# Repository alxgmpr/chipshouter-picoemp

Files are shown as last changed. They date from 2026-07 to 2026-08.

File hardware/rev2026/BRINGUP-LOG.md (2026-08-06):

# Rev-2026 Bring-Up Log — Board #1

Plan: `docs/superpowers/plans/2026-08-05-picoemp-rev2026-bringup.md`
Spec: `docs/superpowers/specs/2026-08-05-picoemp-rev2026-bringup-design.md`

Equipment: DMM; bench PSU with current limit. No scope, no HV probe.

---

## ⚠️ Designators below are board #1's, and rev B moved several

This log is a record of what was measured on the first assembled board. The
readings and conclusions stand. **The reference designators do not** — rev B
re-designated things, so a designator here may name a different part on a
later board.

**Follow this log by what each part is, not by what it is called.**

| What it is | Board #1 | Rev B |
|---|---|---|
| HV terminal block, the `HV_RTN` / `HV_SENSE` tap | `J3` | **`J4`** |
| Trigger input SMA | `J4` | **`J3`** |
| 7-pin header: `TRIG_IN`, `GP1`–`GP5`, `GND` | `P1` | **`J6`** |
| 2-pin header: `GND`, `HVPULSE` | `P2` | folded into the 5-pin |
| 4-pin header: `CHARGED`, `+3V3`, `GND`, `HVPWM` | `P3` | folded into the 5-pin |
| 5-pin header: `+3V3`, `CHARGED`, `HVPULSE`, `HVPWM`, `GND` | — | **`J5`** |

The HV output SMA, the JST power input, all three switches and the Pico keep
their designators.

**One functional change, not just a rename.** The arm switch now pulls its net
to `GND`; on board #1 it pulled up to `+3V3`. Both switches are now
pull-to-ground, which is why `firmware/micropython/bringup.py` configures both
with `PULL_UP` and treats a press as a low reading.

**Consequence: the current `bringup.py` will fail the ARM button check on
board #1.** With an internal pull-up on a pin that board #1's arm switch drives
to `+3V3`, the pin reads high whether or not the button is pressed, so the
press is never seen. That script now targets rev B. Board #1 needs the arm
switch read as `PULL_DOWN`, active high.

Everything electrical in the fault-injection path is unchanged — the charge
loop, the sense chain, the isolation barrier and the discharge path are the
same circuit.

---

## Phase 0 — cold checks

Date: 2026-08-05

Board had not been energized before these readings were taken.

| # | Measurement | Expected | Measured | Pass |
|---|---|---|---|---|
| 0.1 | J1 centre → J3.2 | 300 kΩ ±5 % | 299.5 kΩ | ✅ |
| 0.2 | Hold SW3, J1 centre → J3.1 | 300 kΩ ±5 % | 273 kΩ / 299.3 kΩ reversed (see note) | ✅ |
| 0.3 | GND (USB shell) → J3.1 | open > 20 MΩ | OL | ✅ |
| 0.4 | J1 centre → J1 shell | not a short | OL | ✅ |
| 0.5 | Pico 3V3(OUT) → GND | not a short | 36 kΩ | ✅ |
| 0.6 | J2.1 → J2.2 | not a short | 2.2 MΩ | ✅ |

### Note on 0.2 — 273 kΩ rather than 300 kΩ

`R2` is confirmed good by 0.1 at 299.5 kΩ, and SW3 is confirmed closing by
0.2 reading a finite value at all rather than OL. The 27 kΩ shortfall is a
second conduction path between the probe points, not a component fault:

```
J3.1 (HV_RTN) → T1 secondary (T1.3→T1.2) → HV_RECT → D2 anode→cathode → HV_RAIL (J1 centre)
```

`D2.1` is the cathode on `HV_RAIL` and `D2.2` the anode on `HV_RECT`, so this
path forward-biases when the DMM's **red** lead sits on J3.1, putting a
weakly-conducting diode branch in parallel with R2. Solving 273 ∥ 299.5 puts
that branch at ~3.0 MΩ, consistent with a silicon diode at sub-µA DMM test
current.

0.1 is unaffected because `HV_SENSE` never touches `HV_RTN`, so no D2 path
exists for that measurement — which is why it reads clean.

Reversed-polarity confirmation: **299.3 kΩ**, within 0.2 kΩ of 0.1's 299.5 kΩ.
D2 blocks in this direction and R2 is the only path, as predicted. Resolved.

**Practical consequence:** future resistance measurements between `HV_RAIL` and
`HV_RTN` must put the red lead on `HV_RAIL` (J1 centre). The other polarity
reads low through T1's secondary and D2 and does not indicate a fault.

Notes: Board had not been energized before these readings.

---

## Phase 1 — first power

Date: 2026-08-05
PSU: 5.0 V into J2. USB unplugged. Pico unprogrammed.

The PSU's current-limit function was unavailable (constant-voltage only), so
the DMM was used in series on its mA range instead — a direct current reading,
with the mA-jack fuse as the limit. Voltage was then read in a second pass with
the DMM back on volts.

| Reading | Expected | Measured | Pass |
|---|---|---|---|
| Supply current | < 100 mA, no limit | 0.87 mA | ✅ |
| Pico 3V3(OUT) → GND | 3.3 V ±5 % | 3.285 V (−0.45 %) | ✅ |

### Note on the 0.87 mA

Lower than an unprogrammed Pico normally idles at — the RP2040 bootrom's USB
device mode runs the core and usually draws tens of mA. The likely cause is
DMM burden voltage: on a low autoranged mA scale the shunt resistance drops
the input enough that the RP2040 never starts, and a core that isn't running
keeps the current low, which keeps the DMM on the low range.

Not a concern for what Phase 1 tests. Sub-mA draw with the 3V3 rail up means
no leakage path anywhere, which is the stronger version of the result we
wanted. Cross-check in Phase 2: with MicroPython flashed, draw should rise to
tens of mA. If it does not, revisit this.

---

## Phase 2 — I/O self-test

Date: 2026-08-05
MicroPython: v1.28.0, build `RPI_PICO`, `Raspberry Pi Pico with RP2040`
UF2: `RPI_PICO-20260406-v1.28.0.uf2`, familyID `0xe48bff56` (RP2040), header verified before flashing
Port: `/dev/tty.usbmodem212201`
Script: `firmware/micropython/bringup.py`

| Check | Expected | Observed | Pass |
|---|---|---|---|
| STATUS LED | lights alone | lit | ✅ |
| HV_DET LED | lights alone | lit | ✅ |
| CHARGE LED | lights alone | lit | ✅ |
| All three together | all lit | all lit | ✅ |
| CHARGED idle level | 1 | 1 | ✅ |
| ARM button | PASS | PASS | ✅ |
| PULSE button | PASS | PASS | ✅ |

The script's own `RESULT: PASS` covers only the two button presses — it
cannot sense the LEDs. The four LED rows above are operator-confirmed.

`U1` is `SC0915`, a plain Pico, so the non-W `RPI_PICO` build is correct.
Two other `/dev/tty.usbmodem*` ports on this host belong to an unrelated
device and do not respond to mpremote.

### Firmware defect found at the start of Phase 3 — CHARGED misread

`chargetest.py` aborted with "CHARGED already asserted" on its first run,
having read the same pin as 1 in Phase 2 twenty minutes earlier with nothing
electrical changed in between.

**No high voltage was involved.** Measured through ADC0, the `CHARGED` net sat
at a steady 3.20 V for 20 s including an SW3 press. A charged rail would have
had the LDA111 sinking current and holding the net near 0, and SW3 would have
produced a visible step. Neither happened.

Root cause: the RP2040 resets every GPIO pad with its pull-down enabled
(`PADS_BANK0` reset value `0x56`, bit 2 `PDE=1`), and `CHARGED` reaches **two**
pads — GP18 (U1.24) and GP26/ADC0 (U1.31). Both scripts configured only GP18,
leaving GP26's ~65 kΩ pull-down on the net. Two pull-downs in parallel against
R6's 22 kΩ pull-up divide the net to roughly 2 V, inside the RP2040's
indeterminate band (VIL 0.99 V, VIH 2.31 V). The digital read was arbitrary.

Diagnostic evidence — the level flipped on the exact line that reconfigured
GP26:

```
Pin(18, IN)             = 1
Pin(18, IN, PULL_DOWN)  = 0
Pin(18, IN, None)       = 0
-- configuring ADC0 on GP26 --
GP26 net voltage        = 2.767 V  -> settles 3.20 V
Pin(18, IN, None) now   = 1
```

Fix: configure both pads. `ADC(26)` disables that pad's digital pull, leaving
R6 as the only pull-up. `chargetest.py` now also reads `CHARGED` as a voltage
rather than a logic level, and refuses to charge if the net sits between 1.0
and 2.9 V rather than guessing. Verified on the board: 3.20–3.22 V steady,
GP18 = 1 on every sample.

**Upstream `cspico_simple.py` has the same defect** — `Signal(Pin(18, Pin.IN),
invert=True)` with GP26 never touched. It mostly works because a genuinely
charged rail pulls the net hard to near 0 V, which reads correctly; the failure
mode is a spurious "charged" at rest, which is what was seen here. Not fixed —
this port does not modify upstream firmware.

Not carried out: the Phase 1 current cross-check. Supply draw with
MicroPython running was not re-measured, so the 0.87 mA reading above
remains unexplained rather than confirmed as a DMM burden artifact. Low
priority — it did not block anything.

---

## Phase 3 — first charge

Date: 2026-08-05
Shield: Kapton-taped, **sits flush** (see open items). J1: dust cap fitted.
Power: USB. Script: `firmware/micropython/chargetest.py`

Three consecutive runs:

| Run | At rest | Time to assert | Result |
|---|---|---|---|
| 1 | 3.21 V | 2165 ms | PASS |
| 2 | 3.21 V | 2110 ms | PASS |
| 3 | 3.19 V | 2101 ms | PASS |

| Check | Expected | Observed | Pass |
|---|---|---|---|
| CHARGED asserts | within 10 s | 2.1 s | ✅ |
| Repeatability | — | 2101–2165 ms, 3 % spread | ✅ |
| SW3 releases CHARGED | yes | yes, all three runs | ✅ |

**What these numbers do and do not mean.** The charge time and its
repeatability are real: the T1 channel charges consistently, not marginally.

The "asserted at 0.99 V" the script prints is tautological — the poll loop
exits the moment the net crosses `CHARGED_MAX_V = 1.0`, so it reports the
threshold, not a measurement. Worth changing to sample after a short settle
if that number is ever wanted.

The discharge times (5899 / 3046 / 1101 ms) are dominated by operator reaction
time between the prompt and pressing SW3. τ is 141 ms, so the circuit's share
of each is small. These are not a measurement of discharge speed, and the
downward trend across runs is the operator getting quicker.

Rail voltage measured in Phase 4 — see below.

---

## Phase 4 — stock firmware

Date: 2026-08-05
Firmware: `firmware/micropython/cspico_simple.py` copied to `:main.py`

| Check | Expected | Observed | Pass |
|---|---|---|---|
| ARM lights CHARGE LED | immediately | yes | ✅ |
| HV LED follows | ~2 s | yes | ✅ |
| SW3 drops HV LED | yes | yes | ✅ |
| 60 s auto-disarm | CHARGE LED off | yes | ✅ |

PULSE not exercised — no injection tip. See spec section 8.

**The upstream CHARGED defect did not manifest on this board.** Stock firmware
configures GP18 only and leaves GP26's pull-down on the net, but the HV LED
behaved correctly throughout — no spurious assert at rest, no flicker. This
supports the earlier claim that upstream "mostly works" despite the defect,
which had been asserted without observation. One board, one session; not a
strong result, but it is now an observation rather than a guess.

### Rail voltage — approximately 261 V

Measured with the DMM across J3, i.e. `HV_SENSE` to `HV_RTN`: **250 V** while
charged, decaying after auto-disarm.

That reading is loaded. The DMM's 10 MΩ input sits in parallel with R1 plus
the opto LED, so it is not a direct rail measurement:

```
HV_RAIL --[R2 300k]-- HV_SENSE --+--[R1 20M]--[LED]-- HV_RTN
                                 +--[DMM 10M]--------/
```

Solving the node at 250 V with the LED at ~1.2 V:

| Branch | Current |
|---|---|
| through R1 + LED | (250 − 1.2) / 20 M = 12.4 µA |
| through the DMM | 250 / 10 M = 25.0 µA |
| total through R2 | 37.4 µA → 11.2 V across R2 |

**V_rail ≈ 261 V.** This corroborates the ~250 V figure that previously came
only from the firmware's empirically tuned duty cycle, and leaves comfortable
headroom against C3's 630 V and Q2's 650 V.

**Assumption: 10 MΩ DMM input impedance.** The result is sensitive to it — the
same 250 V reading at 1 MΩ input would imply a 329 V rail. Confirm the meter's
spec before treating 261 V as settled.

The observed decay after auto-disarm is consistent: the DMM shortens the bleed
path from 20.3 MΩ to ~6.97 MΩ, so τ falls from 9.5 s to 3.3 s.

This measurement is repeatable and is now the documented way to check the rail
without an HV probe.

---

## Bring-up complete

All five phases pass. The board charges to roughly 261 V in ~2.1 s, asserts
CHARGED, and discharges on SW3. Stock firmware is installed as `main.py`.

## Open after bring-up

- **Rail voltage is approximate, not qualified.** 261 V is derived from a
  loaded divider measurement with an assumed 10 MΩ meter input, not read
  directly. A proper HV probe would settle it.
- **No injection tip, so pulsing has never been exercised.** Suggested parts:
  Würth `744710603` inductor plus a `CONSMA013.062` edge-mount SMA male. See
  `hardware/injection_tips/README.md`.
- **Mounting holes mirrored.** MH1/MH2 sit on the opposite diagonal to the
  1551G's screw bores; the shield is Kapton-taped rather than screwed. The
  proposed fix is to swap MH1's and MH2's Y coordinates — but see the next
  item before editing anything.
- **The shield seats flush, contradicting the layout record.** `CLAUDE.md` and
  `LAYOUT-HANDOFF.md` both state Q2 fouls the shield rim with 0.00 mm clear
  against 2.32 mm needed, and call it the last open item before the shield
  sits flat. It sits flat on the physical board. Either that note is stale or
  the fabbed board differs from the working copy — which is itself on the
  `+25.4 mm` shifted layout rather than the `rev2026` geometry. Establish
  which revision was actually fabbed before touching MH1/MH2.
- **Phase 1's 0.87 mA draw was never explained**, and the cross-check with
  MicroPython running was not taken.
- **Upstream `cspico_simple.py` has the CHARGED two-pad defect** described
  above. Not fixed here; did not manifest on this board.
- **The trigger front-end is only half tested.** Phase 5 §5.3 passes on board
  #1: the buffered path from the header through R14 and U2 to GP0 carries DC,
  slow edges and short pulses. Everything entering through the **SMA** is
  still untested, as are the DC levels (§5.1) and the Schmitt trip points
  (§5.2). No shipped firmware reads GP0 either — `cspico_simple.py`,
  `bringup.py` and `chargetest.py` all ignore it, so the trigger does nothing
  on a board running stock firmware.

---

## Phase 5 — trigger front-end

Date: 2026-08-06 for §5.3, on board #1. **§5.0, §5.1 and §5.2 have not been
run** — their Measured and Pass columns are blank on purpose.

Script: `firmware/micropython/trigtest.py`

The chain, from the netlist:

```
J3 SMA centre ──┬── TRIG_IN ── R14 100R ──┬── U2.2 (A) ──> U2.4 (Y) ── GP0 (U1.1)
J6.1 header ────┘        net "TRIG_BUF" ──┴── R15 10k ── GND

U2 = 74LVC1G17 Schmitt buffer, SOT-23-5, on +3V3 with C6 100n
R16 = 0R bypass across the buffer, DNP — must stay unfitted
```

Two naming traps. **`TRIG_BUF` is the buffer's input node, not its output** —
the output net is plain `GP0`. And `GP0` is not on any header, so the only
places to probe it are U2 pin 4 and the Pico's pin 1.

**Board #1 is rev A, and the tables below are in rev B names.** Nothing
electrical differs in this path — same Pico pins, same nets, same parts — so
`trigtest.py` runs on rev A unedited. Only the silkscreen names change:

| What | Rev B (below) | Rev A (board #1) |
|---|---|---|
| Trigger input SMA | `J3` | **`J4`** |
| 7-pin header: `TRIG_IN`, `GP1`–`GP5`, `GND` | `J6` | **`P1`** |
| Loopback jumper | `J6.1 ↔ J6.2` | **`P1.1 ↔ P1.2`** |
| `+3V3` pin for 5.1.3 | `J5.1` | **`P3.2`** (4-pin: `CHARGED`, `+3V3`, `GND`, `HVPWM`) |

`J3` in a rev A context is the HV terminal block, not the trigger — keep the
two apart when probing.

### 5.0 — cold checks

Unpowered. Confirm U2, R14, R15 and C6 are actually populated first, and that
R16 is not.

| # | Measurement | Expected | Measured | Pass |
|---|---|---|---|---|
| 5.0.1 | J3 centre → J6.1, probed at the far end of a mated cable | 0 Ω | | |
| 5.0.2 | J3 centre → U2.2 | 100 Ω (R14) | | |
| 5.0.3 | U2.2 → GND | 10 kΩ (R15) | | |
| 5.0.4 | J3 centre → GND | 10.1 kΩ | | |
| 5.0.5 | J3 shell → GND | 0 Ω | | |
| 5.0.6 | U2.5 → Pico 3V3 | 0 Ω | | |
| 5.0.7 | U2.3 → GND | 0 Ω | | |
| 5.0.8 | U2.5 → GND | not a short | | |
| 5.0.9 | U2.2 → Pico pin 1 | open — **not** 0 Ω | | |

5.0.1 through the mated cable rather than the pad, because the edge-launch
SMA's centre-pin joint is the thing most likely to be bad. 5.0.9 catches R16
fitted, which would put the unbuffered node straight onto GP0.

`R15` is an easier probe point for the buffer input than U2's SOT-23-5 pins:
**pad 1 is the input node, pad 2 is GND**. Which one is which physically
depends on how R15 is rotated in the layout, so tell them apart with the
meter — the GND pad reads 0 Ω to ground — rather than by position.

### 5.1 — powered, static

USB power, nothing connected to the trigger.

| # | Measurement | Expected | Measured | Pass |
|---|---|---|---|---|
| 5.1.1 | U2.2 at rest | 0 V (R15 pulls it down) | | |
| 5.1.2 | U2.4 at rest | 0 V | | |
| 5.1.3 | U2.2 with TRIG_IN jumpered to J5.1 (+3V3) | 3.3 V | | |
| 5.1.4 | U2.4, same | 3.3 V | | |
| 5.1.5 | both, jumper removed | back to 0 V | | |

### 5.2 — threshold and hysteresis

Bench PSU into `TRIG_IN`, current limit 10 mA, swept slowly 0 → 2 V and back
while watching U2.4 with the DMM. Datasheet numbers are the VCC = 3.0 V column
of the Nexperia 74LVC1G17, rev 16.1; the rail here is 3.3 V, so the real trip
points sit a little above these.

| # | Measurement | Expected | Measured | Pass |
|---|---|---|---|---|
| 5.2.1 | Rising trip point (V_T+) | 1.29 – 1.71 V | | |
| 5.2.2 | Falling trip point (V_T−) | 0.88 – 1.24 V | | |
| 5.2.3 | Gap between them (V_H) | 0.31 – 0.64 V | | |

Two distinct trip points is the point of the measurement — it is what
distinguishes a real Schmitt part from a plain buffer fitted by mistake.
Input leakage is ≤ 1 µA, so R14 drops nothing and the applied voltage is the
node voltage.

### 5.3 — firmware

```
mpremote connect <port> run trigtest.py
```

Needs one jumper, `J6.1 ↔ J6.2` (`P1.1 ↔ P1.2` on board #1), and **nothing
else on TRIG_IN or the SMA** — GP1 would be fighting it.

Precondition: board disarmed and the cap down before mpremote connects. Stock
`main.py` is running on board #1, and `mpremote` interrupts it — but the
RP2040's PWM slice keeps running after the script that started it stops, so
interrupting mid-charge leaves HVPWM driving. `trigtest.py` never references
GP20 and so cannot stop it either. Confirm the HV LED is out first. The script drives its
own trigger through the whole chain and checks GP0 follows, so it is
self-checking rather than operator-judged.

| Check | Expected | Observed | Pass |
|---|---|---|---|
| `IDLE` | PASS — GP0 low and steady, trigger open | PASS | ✅ |
| `DC` | PASS — GP0 follows 0/1/0 | PASS | ✅ |
| `EDGES` | PASS — 50 sent, 50 counted | 50 / 50 | ✅ |
| `NARROW 100/10/1 us, back-to-back` | PASS on all four | PASS ×4 | ✅ |
| `RESULT` | PASS | PASS | ✅ |

**The buffered path is good on board #1.** GP1 → header → R14 → U2 → GP0
carries DC, 50 slow edges with no extras, and a pulse as short as two
consecutive MicroPython pin writes.

Two caveats on what that does *not* cover. The jumper enters at the header, so
the SMA and its centre-pin joint are untested — that is what §5.4 and the
`WATCH` phase are for. And `IDLE` is only a real test of R15 with the jumper
off: fitted, GP1 is already an output at 0 and holds the trigger down itself.

`WATCH` reported no source on the first three runs, correctly — nothing was
driving the trigger. On the first two the jumper was fitted mid-phase, which
does nothing on its own: GP1 was still an output at 0. The script now releases
GP1 to an input before `WATCH` and says so, so a jumper left in place no longer
fights an outside source.

It cannot make high voltage: GP20 and GP14 are never referenced, enforced by
`tests/test_bringup_firmware.py::test_cannot_drive_hv`.

### 5.4 — before plugging a pulse generator into the SMA

**There is no 50 Ω on this input.** R15 is a 10 k pulldown, not a terminator.
A generator whose amplitude is calibrated into 50 Ω delivers twice that into
an open end, so a 5 V setting arrives at the buffer as ~10 V — against a
5.5 V tolerant input with a 6.5 V absolute maximum. Set the generator to
high-Z, or fit a 50 Ω feedthrough terminator at the board, or measure the
amplitude at the SMA before connecting it.

The same reflection is why long unterminated coax with fast edges can produce
extra counted edges. The Schmitt's 0.3 – 0.6 V of hysteresis absorbs small
overshoot, not a 2 V reflection.

`J3`'s shell is board `GND`, so the coax bonds the target's ground to the
PicoEMP's low-voltage ground and hence to USB. It does not touch the HV
isolation barrier, but it is a ground loop with whatever is being glitched.

Propagation delay through U2 is 3.0 ns typ / 5.5 ns max at 3.0 – 3.6 V —
below what a logic analyser resolves, and far below the RP2040's response.

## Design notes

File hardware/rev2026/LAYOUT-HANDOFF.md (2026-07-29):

# Layout Record — PicoEMP Rev-2026

**Status: layout is done; the HV shield is chosen and screwed down, but two
part groups still foul its rim.** Board routed, both gates green. This
file records what was built and why. It was previously a set of instructions
for work not yet started; those instructions have been carried out and are kept
below only where the reasoning still matters.

For orientation in a fresh session, read `CLAUDE.md` in this directory first.

**Plan:** `docs/superpowers/plans/2026-07-25-picoemp-rev2026.md`
**Spec:** `docs/superpowers/specs/2026-07-25-picoemp-rev2026-design.md`
**Branch:** `rev2026`

---

## Verified state — 2026-07-28

| Gate | Result |
|---|---|
| `uv run --with pytest pytest tests/` | **66 passed**, 0 failed, 0 skipped |
| `kicad-cli pcb drc --severity-error --schematic-parity --exit-code-violations` | **0 errors, 0 unconnected, 0 parity issues**, exit 0 |
| Same, **without** `--severity-error` | **0 violations** — warnings are empty too |
| `kicad-cli sch erc --severity-error` | 0 violations |
| Routing | complete |
| Every symbol has a resolvable footprint | yes |

Board: 40.010 × 130.000 mm overall — the **body** is 40.010 × 125.000 and the
south **15.780 mm-wide SMA tab** carries the remaining 5.000 mm. 2 layers,
1.6 mm. **53 footprints** (45 SMD / 5 THT / 3 other — the mounting holes),
252 track segments, **102 vias**, **76 zones** (75 teardrops + the
`MCU GND Pour`). 53 schematic components, 64 nets. `R16` is the only DNP part.

**DRC warnings are empty.** Older revisions describe two cosmetic silk warnings
and nine from the intra-HV rule; both sets are fixed, and the
`Intra-HV spacing at full rail voltage` rule now passes at its 0.8 mm target.
The `Pad Keep Out TP7` keepouts are also gone.

---

## What changed from the as-received port

- **R9's part data corrected.** It carried R4's 75 Ω MPN, DigiKey PN and value
  while being a 2 k part. A genuine upstream schematic bug.
- **C5's missing value** restored to 100 n.
- All Altium metadata stripped; fields normalised to `MPN` / `Manufacturer` /
  `DigiKey`.
- **Symbol classes corrected** — IGBT (with its co-packed antiparallel diode),
  enhancement MOSFETs, non-Schottky rectifiers, a real Darlington opto, and a
  transformer symbol whose windings match this design's actual 1,4-primary /
  2,3-secondary grouping.
- **All five header footprints** moved from 1.00/1.27 mm to the correct 2.54 mm.
- **Designators restored to upstream's scheme** — `D6/D8/D9`, `P1/P2/P3`,
  `J1` = SMA — so `BUILD-DRAWING-REV04.PDF` and the README BOM explainer apply.
- **New trigger front-end:** `U2` 74LVC1G17 Schmitt buffer, `R14` 100 R series,
  `R15` 10 k pulldown, `C6` decoupling, `R16` 0 Ω bypass (DNP), `J4` optional
  SMA (populated).
- **J3** replaced with a Phoenix `MKDS 1,5/2-5.08` (5.08 mm, 300 V) for creepage.

---

## The 1 mm isolation barrier — how it was implemented

The value is **upstream's own design rule**, annotated on
`SCH-PICOEMP-REV04.PDF`:

> `ISOLATION BARRIER, 400V MIN.  >1MM CLEARANCE PER 61010-1.`

Corroborated by measurement — pad geometry on the hi-pot-validated original
board gives ~1.002 mm across the barrier in routed copper.

**Voltages, from primary sources** (component ratings are headroom, not
operating points):

| | |
|---|---|
| HV capacitor charge | **~250 V** — `firmware/micropython/cspico_simple.py` |
| Upstream barrier design rating | **400 V min** |
| Hi-pot proof test | 1 kV, "well beyond the voltages the device can generate" |

It is enforced as a **scoped DRC rule**, not as netclass clearance. An earlier
draft of this document instructed adding the 1 mm figure to the `HV` netclass;
that turned out to be wrong. As a plain netclass clearance it applies between
any two nets touching the class, which makes 0603 (0.70 mm between its own
pads) and 0805 (0.80 mm) parts illegal on HV nets. The `HV` class therefore
carries 0.2 mm clearance / 0.5 mm track, and `picoemp-rev2026.kicad_dru` scopes
the barrier correctly as HV-to-non-HV. Read that file before changing anything
here.

**Known exception:** T1's own primary↔secondary pad spacing is 0.770 mm, below
this rule. That is the ATB3225 package's geometry, not a routing choice, and
upstream accepted it. Targeted exceptions for T1 and T2 are in the `.dru`.

---

## Resolved — items that were open in the previous draft

- **`Q2` DPAK pad spacing.** Flagged as fab-blocking on a DRC reading of
  0.080 mm that could not be reconciled with geometry computing to 1.08 mm.
  Measured directly: **1.080 mm**. The reading was spurious; the footprint is
  fine at 250 V.
- **`LDA111` pad 3 parity.** The symbol has five pins, the footprint six pads,
  because pin 3's lead physically exists while being electrically NC.
  `--schematic-parity` now reports 0 issues. The pad was not deleted — doing so
  would leave a lead unsoldered.
- **Board setup.** Minimum clearance is 0.2 mm (was 0.0). Thickness 1.6 mm, as
  required by the edge-mount SMA which clamps the board edge and is specified
  for 0.062″.
- **Intra-HV clearance.** Recorded as 0.498 mm at SW3, "the thinnest copper on
  the HV side". No longer true — the `Intra-HV spacing at full rail voltage`
  rule in the `.dru` now reports **zero** violations at its 0.8 mm target, and
  SW3 does not feature. The header comment in the `.dru` still says "As of this
  writing it reports 9 violations"; that predates the fixes that cleared them.
  Sub-0.4 mm gaps do exist between other HV nets, but those pairs sit a few
  volts apart, not 250 — `HV_SENSE` is ~1.5% below `HV_RAIL` across the
  300 k / 20 M divider, and `HV_SENSE_LED` is one opto LED drop above `HV_RTN`.
  That is exactly why the rule is scoped to the three pairs that matter.
- **SW3 clearance under the shield.** Previously unverifiable "for want of a
  3D model" — `lib/models/TL3301AF160QJ.STEP` exists and the part measures
  **4.64 mm**, clearing the 1551G's 15.05 mm cavity easily.
- **The two short Edge.Cuts slots at y 96.354–99.300.** These were the
  1551B's snap-tab pockets, not creepage features — nearest HV-netclass copper
  was 16.6 mm. Removed with the switch to the 1551G.
- **MH1/MH2's 32.000 mm spacing.** Recorded as "the dimension a shield keys
  off". It was not — it was 40.010 minus two 4.000 mm corner insets, and
  upstream REV04's fab drill has the identical pattern.

## The HV safety shield — Hammond 1551G, not the 1551B

Upstream uses the **top half of a 1551B** (50 × 25 × 15) as a see-through shield
over the HV end. This port cannot: **J3's Phoenix terminal block is 13.80 mm
tall and a 1551B half-shell gives 5.80 mm of clear height above the board.** The
creepage upgrade to the 5.08 mm Phoenix part and the shield were never checked
against each other.

The replacement is the **1551G box, inverted, lid discarded**. The larger 1551
sizes are box + lid rather than two symmetric halves, so the box is far deeper
than any half-shell. Every figure below is measured from Hammond's own STEP —
`tools/fetch_hammond_shield_model.py` re-downloads and re-axes both models, and
they are gitignored because Hammond's models are not under this project's
licence.

| | 1551B top half | **1551G box, inverted** |
|---|---|---|
| Outer | 50 × 25 × 15 | **50.000 × 35.000 × 17.000** |
| Interior clear height | 5.80 | **15.050** |
| Interior L × W | 47.4 × 21.6 | **44.73 × 29.73** |
| Screws | 2 × #2, 19.000 pitch | **2 × #4 × ½″, diagonal** |

**The screw pattern is a diagonal pair on 38.500 × 23.500 mm** — *not* the
43.88 × 28.88 the drawing appears to give. That is the outside extent of the
Ø5.00 boss recesses: 43.88 − 5.00 and 28.88 − 5.00. The box's Ø2.50 bores and
the lid's Ø3.50 through-holes both sit at (±19.25, ∓11.75), which is what
"includes 2 cover screws" meant. Shell centre on this board is
**(124.390, 119.872)**, south edge flush with the board body, so the screws want
**(112.640, 100.622)** and **(136.140, 139.122)**.

`picoemp:Shield_Hammond_1551G_Box` carries the geometry. Silk marks the north
two corners at (106.890, 94.872) and (141.890, 94.872) plus a `1551G` label —
only the north edge is ambiguous, since the south edge is flush and the width is
centred.

**The lid is not waste.** Its two Ø3.50 holes are on the same diagonal, so the
stack is screw → lid → PCB → box bore, capturing an underside cover on the same
two screws. Its inner recess is 3.05 mm against J3's 3.50 mm pin protrusion, so
trim the pins.

### Still blocking a seat

The rim contacts the board across a solid ~2 mm band (|local Y| 23.0–25.0,
|local X| 15.4–17.5) with a chamfer inboard of it. Probing every part under the
shell against the real STEP, four still foul:

- **Q2** — 0.00 mm clear at local (−8.50, +23.29), needs 2.32. About **0.4 mm
  north**, 0.6 with margin. Beware: a scripted 0.6 mm move shorted `HV_OUT` to
  the `HV_RTN` trunk beside it, so the trunk moves in the same operation. This
  is the only part still fouling.
- ~~D3 / D4 / D5~~ — **resolved.** Moved +1.5 mm south to y 98.4 (with R6 out to
  (128.100, 98.075) to make room); they now clear by 12.75 mm.

Everything else clears: **J3 by 1.20 mm** (the whole point of the 1551G),
SW3 by 10.36, Q1 by 11.32, every passive by 13–14.5. Q4 and R10 sit under the
screw-boss recesses with 0.80 and 1.55 mm.

**MH1/MH2 are on the screw axes** — (112.640, 100.622) and (136.140, 139.122).
MH1's spot had to be cleared: `GND` tracks sat 0.677 mm inside the hole and R10
pad 1 0.206 mm inside, and nothing routes west of it (0.425 mm to the isolation
slot against the 0.65 mm a 0.25 mm track needs). R10 moved to
(116.900, 103.400) rot 180 with `GND` jogged onto B.Cu — vias at
(116.400, 104.700) and (113.000, 108.500) — which sidesteps the corridor
entirely. Nearest copper to MH1 is now +2.210 mm from the hole edge, and the
B.Cu run clears the nearest HV copper by 5.12 mm.

## Still open

- Q2 fouls the shield rim — above. The screw holes and D3/D4/D5 are done.
- TL3301 **internal** standoff at ~246 V across open contacts is unverified —
  no datasheet in repo, only a STEP model.
- P1/P2/P3 have no MPN.
- J3 has no routed creepage slot; the 5.08 mm part's 2.480 mm pad separation is
  the documented fallback. Its schematic `BOM Comments` field still says "Milled
  slot between pads" — stale.

---

## ⚠️ Still true: do not trust the old board's footprints

**The as-received board's imported footprints are not trustworthy.** At least
one — `SamacSys:SOP254P952X470-6N`, the optocoupler — has pads whose rotation
fuses them into two solid copper bars. It would have shorted pins 1‑2‑3 and
4‑5‑6 together.

- **The routed copper geometry is still a valid reference** — that is what was
  hi-pot tested.
- **The footprint definitions are not.** Render anything you take from that file
  before believing it (`kicad-cli fp export svg`).

Related: `hardware/altium_src/kc/` is a *different* in-progress REV04 migration
and its HV sense section is miswired. See `CLAUDE.md`.

---

## Other notes that remain relevant

**T1/T2 pin-1 dot must match `BUILD-DRAWING-REV04.PDF`.** Upstream reversed this
on the original prototype and got a wrong-polarity spike.

**Keep the trigger path short** — `P1.1 → R14 → U2 → GP0` — and away from the HV
section.

**SW3 silk-to-pad clearance is 0.05 mm.** Tight against typical fab guidance
(~0.15–0.2 mm), but it matches KiCad's own stock `TL3301NxxxxxG` precedent. If
your silk DRC rule is stricter, pull the silk notches wider rather than removing
them. This is the source of the two standing `silk_over_copper` warnings.

**Beware "Update Footprints from Library."** It has already wiped DNP
attributes on this project once (commit 3b90f5e). After running it, check that
`R16` is still DNP and that `Q1` still has six pads.

**SW3 now has a 3D model** — `lib/models/TL3301AF160QJ.STEP`, measuring 4.64 mm
tall, so its clearance under the shield is verified rather than assumed. The
note below is kept only for the SW1/SW2 comparison. Check
clearance against the 1551B half-shell by hand: SW1/SW2 are 4.30 mm, SW3 is
5.00 mm.

---

## Next

Tasks 12 and 13 — fab outputs, the DigiKey BOM, and a full pre-fabrication
design review.

**Do not order without** reviewing the gerbers in KiCad's Gerber Viewer,
including the drill file.

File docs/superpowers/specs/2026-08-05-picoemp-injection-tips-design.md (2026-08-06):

# PicoEMP Injection Tips and Fault Detector — Design Spec

**Date:** 2026-08-05
**Status:** Approved
**Follows:** `2026-08-05-picoemp-rev2026-bringup-design.md`
**Board:** Rev-2026 #1, bring-up complete — ~261 V rail, 2.1 s charge, verified charge/discharge

---

## 1. Goal

Build a small set of EM injection tips and prove which of them actually produce
a usable field, using a target that doubles as the detector.

Pulsing has never been exercised on this board — there has been no tip. This
spec covers the first pulse.

## 2. The constraint that shapes everything

**No oscilloscope.** A tip that produces no useful field is indistinguishable
from one that works: the board charges, the pulse fires, and nothing observable
happens either way. Tip-building without a detector is unfalsifiable, and the
whole point of making several tips is to compare them.

The resolution is a target that reports on itself. A spare Pico runs a
deterministic self-checking loop and counts its own corruptions. A wrong answer
is unambiguous proof the tip did something.

## 3. Decisions

| Question | Decision |
|---|---|
| Scope | Tips + free-running target. No trigger, no delay sweep. |
| Detector | The target itself — self-checking loop, fault counter over serial |
| Timing | Manual pulse. See §5. |
| Tip count | 3–4, chosen to span a range rather than to be individually optimal |
| Rigid connector | Taoglas `EMPCB.SMAMST.A` |
| Cable connector | Linx `CONSMA007` — bought, but not built first |
| Standoff | Tip resting on the target package |
| Target firmware | MicroPython |

## 4. Why no trigger

The trigger front-end (`J4` → `R14`/`R15` → `U2` Schmitt → GP0) is the only
genuinely new circuitry in this revision and remains untested. Exercising it is
worth doing — but not here.

The target loops **continuously**, so a randomly-timed pulse always lands
somewhere inside the sensitive window. MicroPython's interpreted execution
makes that window milliseconds wide. Aiming in time is what you need to
characterise a target — to find *which* instruction is vulnerable — not to
answer "does this tip produce a field."

Adding triggering now would mean debugging tip geometry, trigger timing and
delay sweep simultaneously, with no known-good reference for any of them. It
also requires the C firmware, and therefore the Pico SDK and a CMake build.

Triggering is the right destination. It is the wrong next step.

## 5. Tip set

**Buy 3–4 cheap inductors and let the fault counter rank them.** Ferrite
inductors cost under $2; the SMA connectors dominate the bill. With a working
detector, empirical ranking is cheaper and more reliable than prediction.

Selection criteria, in priority order:

1. **Unshielded or open-core construction.** A shielded inductor exists to
   contain its field, which is precisely backwards for a tip. Würth's WE-TIS
   series is explicitly shielded. The repo's `744779068` example works because
   its ferrite cover was removed. Filter on unshielded or open-drum parts.
2. **Core diameter spanning a range** — roughly 6–8 mm for a coarse,
   high-energy tip and 3–4 mm for something more spatially selective.
3. **Low inductance.** Induced voltage in the target follows dB/dt. For a fixed
   core the field is roughly independent of turn count — B ∝ N·I and
   I = V·√(C/L) ∝ 1/N, so the two cancel — and what changes with fewer turns is
   *speed*. Lower L discharges faster and couples harder. Favour the low-µH end.

**No part numbers are specified here.** The repo README's `744710603` does not
appear in Würth's current catalogue, and the README predates 2025. Resolving
real MPNs against live distributor stock belongs in the implementation plan,
not baked into a spec.

### Connectors

`EMPCB.SMAMST.A` (SMA plug, male, board edge, end launch) at $3.83/1 and
$3.26/10, against Linx `CONSMA013.062` at $5.85 for the same function. The
inductor solders to a scrap of PCB carrying the connector, keeping loop area
small.

**Verify board thickness from the datasheet before ordering.** End-launch SMAs
have a fixed slot; the Linx part's `.062` suffix denotes 0.062 in (1.57 mm),
but the Taoglas listing does not state one. Standard scrap FR4 is 1.6 mm and
this is very likely fine, but a mismatched slot means the PCB scrap will not
seat.

`CONSMA007` ($2.35, male plug, crimps to RG-174) is worth owning for a
pigtailed probe when a target needs reaching into. Not built first — a Pico on
a bench needs no reach. When it is built, the fault counter measures what the
cable costs, as a lower fault rate at identical geometry.

## 6. Target and detector

A **spare** Pico — distinct from the PicoEMP's own — running MicroPython.

Required behaviour:

- A deterministic self-checking computation (nested counters reaching a known
  product), repeated forever.
- A running count of results that did not match.
- A heartbeat line carrying a monotonic sequence number.
- Output over USB serial.

Two distinguishable signals:

| Observation | Meaning |
|---|---|
| Mismatch count increments | Data fault — the computation was corrupted |
| Sequence number restarts at zero | The target reset or crashed |

Both count as the tip having done something.

## 7. The control

**Before pulsing, run the target with the PicoEMP charged but not pulsing, for
at least as long as the intended test run. Expect zero faults.**

Without this baseline a fault count is unattributable. MicroPython on a
breadboard can produce anomalies unaided, and a nonzero baseline means the
experiment is measuring the setup rather than the tip.

If the baseline is nonzero, fix that before continuing. Comparing tips against
a noisy floor produces rankings that are not real.

## 8. Standoff

Rest the tip on the target package.

Optimum standoff is approximately R/√2, where R is probe radius (Gaine et al.,
cited in `hardware/injection_tips/README.md`) — about 1 mm for a 3 mm core.
Package height above the die already sits in that range, so contact is both
near-optimal and exactly repeatable. **Repeatability matters more than
optimality when the goal is comparing tips**, since position variation between
trials would swamp the difference being measured.

**Insulate the tip face with Kapton.** With a coil fitted, the coil is a DC
short from `HV_RAIL` to `HV_OUT`, so the SMA shell and the whole tip body sit
at essentially the full rail relative to `HV_RTN`. That is isolated from earth
and will not shock through the target, but it is 261 V of floating metal and
must not rest on exposed target pins.

## 9. Success criteria

| # | Criterion |
|---|---|
| 1 | Baseline run produces zero faults |
| 2 | At least one tip produces a repeatable, nonzero fault count |
| 3 | Tips are ranked by faults per pulse at fixed position |

Criterion 2 is the real gate — it is the first evidence this board can inject a
fault at all. Criterion 3 is what justifies having built more than one tip.

## 10. Safety

1. The pulse is a strong EM transient at close range. It can reset or corrupt
   **the PicoEMP's own Pico**, and disturb USB on both boards. Keep the host
   and both USB cables away from the tip.
2. Expect the target to crash. Flash corruption is a plausible outcome of
   glitching a board — use a spare, not one that matters.
3. All Phase 3 rules from the bring-up spec still apply: shield in place, SW3
   before contact, hands clear of J1.

## 11. Out of scope

- **Triggered injection and delay sweeps.** See §4. The natural follow-on, and
  the point at which the trigger front-end finally gets exercised.
- **Hand-wound and shaped-ferrite tips.** Sub-millimetre probes need a shaped
  core; no shaping capability is available. Off-the-shelf inductors only.
- **Rail voltage qualification.** Still approximate — 261 V derived from a
  loaded divider measurement. Unchanged by this work.

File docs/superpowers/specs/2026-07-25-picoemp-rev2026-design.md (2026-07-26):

# PicoEMP Rev-2026 — Design Spec

**Date:** 2026-07-25
**Status:** Approved
**Base:** NewAE ChipShouter-PicoEMP REV04

---

## 1. Goal

Produce a correct, buildable, 2026-sourceable KiCad revision of the PicoEMP. The
existing KiCad port is mid-migration and not fabricable: 20 duplicated footprints,
a netlist split between legacy Altium and new KiCad names with all copper on the
legacy side, five header footprints at the wrong pitch, and 26 unregistered
libraries. See `hardware/altium_src/kc/audit/AUDIT.md` for the full assessment.

This revision keeps the validated analog design and fixes everything around it.

## 2. Decisions

| Question | Decision |
|---|---|
| Scope | Modernize + targeted fixes |
| Layout | Fresh layout, replicating HV section geometry |
| Build route | **Full hand build. Bare PCB from JLC, no PCBA.** |
| Quantity | ~5 prototypes, personal use |
| Sourcing | **DigiKey** |
| J3 HV tap | Keep, wider pitch + milled creepage slot |
| Pico mount | SMD castellated reflow (hand-soldered) |
| Trigger I/O | Protect + Schmitt buffer, header + DNP SMA pads |
| Schematic strategy | Approach A — preserve verified connectivity, replace symbols/footprints/fields in place |

### Why approach A

The existing schematic's netlist was verified correct against the firmware pin
map, including the quirk where `CHARGED` routes to both GP18 and the ADC-capable
GP26:

| Firmware | Pico pad | Net |
|---|---|---|
| GP14 HVPULSE | 19 | `/HVPULSE` |
| GP18 CHARGED | 24 | `/CHARGED` |
| GP20 HVPWM | 26 | `/HVPWM` |
| GP26 ADC0 | 31 | `/CHARGED` (second tap) |
| GP0 trigger | 1 | to 1×7 header |
| GP6/7/11/27/28 | 9/10/15/32/34 | LEDs, buttons |
| VBUS | 40 | via D1 |
| 3V3 OUT | 36 | `+3V3` |

The hardest part of a schematic — correct connectivity — is already done and
independently confirmed. Redrawing risks it for no gain.

## 3. Frozen

Unchanged from REV04, because these were tuned empirically and documented in
`hardware/design_notes/`:

- **Topology**: T1 charge flyback → D2 rectifier → C3 storage → Q2 IGBT → coil,
  with T2 as the isolated gate-drive transformer.
- **Tuned values**: 2500 Hz at 1.22% duty for charging; 5 µs default pulse; 10 Ω
  gate series (R3/R7); 2 k shunt (R9); 18 V clamp (D7).
- **Pico pin assignment**, so existing firmware runs unmodified and serves as the
  bring-up reference.
- **40 × 116 mm outline, 2-layer**, Hammond 1551B half-shell fit.

## 4. Changes

1. BOM refreshed for 2026 DigiKey availability.
2. J3 moved to a wider-pitch connector with a milled creepage slot.
3. Trigger input protected and buffered.
4. Real HV netclass with enforced DRC.
5. Correct symbols and footprints, served from project-local libraries.
6. Reference designators restored to upstream's scheme.
7. Fresh layout, replicating HV geometry.

## 5. BOM

Sourced from DigiKey, hand-built. Because there is no JLC parts-library
constraint, **most of the upstream BOM is retained** — the substitutions
considered earlier existed only to satisfy JLC's library.

### 5.1 Must change

| # | Ref | Change | Reason |
|---|---|---|---|
| 1 | D6 D9 | `APT1608SRCPRV` → **`APT1608SURCK`** | Original is **obsolete and no longer manufactured**; DigiKey names this as the substitute |
| 2 | R9 | → **`RC0805FR-072KL`** (DK `311-2.00KCRCT-ND`) | Bug: value is 2 k but every part field said 75 R. Design notes confirm 2 k is the validated shunt |
| 3 | J3 | BG306 → **5.08 mm terminal block** + milled slot | Creepage; also drops the BG306's R1/R2 land ambiguity and bulk-only packaging |
| 4 | — | **New trigger front-end**: U2, R14, R15, R16, C6, J4 | Agreed robustness fix |

### 5.2 Retained

| Ref | Part | DigiKey | Status |
|---|---|---|---|
| C1 C2 | TDK C2012X5R1H475K125AB | `445-5980-1-ND` | Active |
| C3 | Murata KRM55TR72J474MH01K | `490-16845-1-ND` | Active |
| C5 | KEMET C0603C104K5RACTU | `399-5089-2-ND` | Active |
| D1 D3 D4 D5 | MCC SM4005PL-TP | `SM4005PL-TPMSCT-ND` | Active |
| D2 | onsemi MURA160T3G | — | Active |
| D7 | onsemi MM3Z18VB | `MM3Z18VBCT-ND` | Active, ±2% grade |
| D8 | Kingbright APT1608CGCK | `754-1116-1-ND` | Active |
| Q1 | IXYS LDA111STR | `212-LDA111SCT-ND` | Active, 23-wk lead |
| Q3 Q4 | AO3422 | — | Active; lowest Vgs(th) of the candidates |
| R1 | CRMA2010AF20M0FKEF | — | Active; 2000 V working, 4× margin |
| R3 R7 | RC0603FR-0710RL | `311-10.0HRCT-ND` | |
| R4 | RC0805FR-0775RL | `311-75.0CRCT-ND` | |
| R5 R10–R13 | RC0603FR-071KL | `311-1.00KHRCT-ND` | |
| R6 | RC0603FR-0722KL | `311-22.0KHRCT-ND` | |
| U1 | Raspberry Pi SC0915 | — | Active; guaranteed to Jan 2036 |
| J1 | Amphenol 132289 **or** Cinch 142-0701-801 | — | Interchangeable pair. **Not** Molex 73251-1150 — 8.76 mm vs 8.50 mm ground pitch plus two locating holes |
| J2 | JST S2B-XH-A(LF)(SN) | `455-2257-ND` | Side entry, 2.5 mm |

**R2 default: retain the TE `3522300KFT`** (DK `A121215CT-ND`), consistent with
the principle of keeping validated parts elsewhere in this revision. It sits below
the opto LED carrying ~24 µA and dissipating ~0.2 mW, so the 3 W / 250 V rating is
not required — if its 17-week lead time blocks the order, substitute any generic
300 k 2512 1% without further analysis.

### 5.2b Switches, headers, mechanical

| Ref | Part | Note |
|---|---|---|
| SW1 SW2 SW3 | C&K KSC7 series, J-bend, 6.2 × 6.2 mm | Actuator heights selected per §10. Upstream used `KSC741JLFS` (390 gf, 4.30 mm) for SW1/SW2 and `TL3301AF160QJ` (160 gf, 5.00 mm) for SW3 |
| P1 | 1×7 header, **2.54 mm** | Pitch corrected — the current port has 1.00 mm |
| P2 | 1×2 header, **2.54 mm** | Pitch corrected — currently 1.27 mm |
| P3 | 1×4 header, **2.54 mm** | Pitch corrected — currently 1.00 mm |
| MH1–MH3 | M3 mounting holes | `MountingHole:MountingHole_3.2mm_M3_Pad_Via` |
| — | Hammond **1551BTRD** shield | Or 1551BCLR / BTSK / BBK / BGY — all fit identically. 3D-printable alternative in `hardware/shield/` |

### 5.2c Off-board, order alongside

Not on the schematic but needed to actually use the tool:

| Item | Part | Note |
|---|---|---|
| Battery holder | Sparkfun `PRT-09925` | 2×AA with switch, JST-XH pigtail → J2 |
| Probe SMA | `CONSMA013.062` | Mates with J1 |
| Probe inductor | `PCV-0-472-03L` | |
| Ferrite | `744710603` | |
| USB isolator | Seeed `114991949` or Adafruit `2107` | **Strongly recommended** when communicating during operation |

### 5.3 New parts

| Ref | Part | Purpose |
|---|---|---|
| U2 | 74LVC1G17, SOT-23-5 | Non-inverting Schmitt buffer on trigger; 5.5 V tolerant input |
| R14 | 100 R 0603 | Trigger series limit |
| R15 | 10 k 0603 | Trigger pulldown — prevents a floating input self-triggering |
| R16 | 0 Ω 0603, **DNP** | Buffer bypass. Populate only with U2 removed |
| C6 | 100 nF 0603 | U2 decoupling |
| J4 | Edge-mount SMA pads, **DNP** | Optional trigger input, no commitment |

### 5.4 NRND — lifetime buy

| Ref | Part | DigiKey | Qty |
|---|---|---|---|
| T1 T2 | ATB322524-0110-T000 | `445-8636-1-ND`, 3,878 stock | **30** |
| Q2 | RGT16BM65DTL | 8,984 stock | **10** |

Both are NRND. The transformer has **no equivalent from any vendor in any
package** — the ATB3225 family has exactly two members and both are NRND. This is
the design's single point of failure.

Q2 is **retained rather than substituted**: it is the validated device, and
upstream warns that "gate charge may be different which will affect drive
waveform." ST `STGD6M65DF2` (650 V, TO-252, co-packed antiparallel diode, in full
production) is recorded as the forward path when ROHM stock is exhausted. Any
replacement must have a co-packed antiparallel diode.

Expected cost: ~$45–60 per board at qty 5, plus ~$45 one-time for the NRND
stockpile. Bare PCBs from JLC are a few dollars for five.

## 6. Schematic and libraries

### 6.1 Library strategy

Create **project-local** `sym-lib-table` and `fp-lib-table`, committed with the
design, so the project opens correctly on any machine.

Available from KiCad stock libraries:

| Need | Footprint |
|---|---|
| D1 D3 D4 D5 | `Diode_SMD:D_SOD-123F` |
| D7 | `Diode_SMD:D_SOD-323F` |
| D2 | `Diode_SMD:D_SMA` |
| Q2 | `Package_TO_SOT_SMD:TO-252-3_TabPin2` |
| Q3 Q4 | `Package_TO_SOT_SMD:SOT-23` |
| U2 | `Package_TO_SOT_SMD:SOT-23-5` |
| C3 | `Capacitor_SMD:C_2220_5750Metric` |
| J1 J4 | `Connector_Coaxial:SMA_Amphenol_132289_EdgeMount` |
| J2 | `Connector_JST:JST_XH_S2B-XH-A_1x02_P2.50mm_Horizontal` |
| U1 | `Module:RaspberryPi_Pico_SMD` |

To be created from manufacturer datasheets:

1. **T1/T2 — ATB322524**, 3.2 × 2.5 mm, 4 pads.
2. **Q1 — LDA111STR**, 6-pin gull-wing SMD, 2.54 mm pitch, 9.52 mm span. KiCad
   has no generic SOP-6 opto land.
3. **Tact switch** and **J3 terminal block**, once those parts are fixed.

### 6.2 Symbol corrections

| Ref | From | To |
|---|---|---|
| Q2 | `Device:Q_NMOS_Depletion` | Project-local IGBT **with antiparallel diode**. KiCad's `Q_NIGBT_*` family has no co-packed-diode variant |
| Q3 Q4 | `Device:Q_NMOS_Depletion` | `Device:Q_NMOS` (enhancement) |
| D1 D3 D4 D5 | `Device:D_Schottky_Small` | `Device:D_Small`. Fixes a documented upstream errata — these were never Schottky |
| Q1 | `*:root_0_mirrored_LDA111STR_*` | Project-local LDA111 symbol with **Darlington** output |
| T1 T2 | `NewAE_AltiumLib:root_0_xformer…` | `Device:Transformer_1P_1S` |

### 6.3 Field normalization

- `MANUFACTURE PART NUMBER 1` → `MPN`
- `MANUFACTURE 1` → `Manufacturer`
- `SUPPLIER PART NUMBER 1` → `DigiKey`
- `PART NUMBER` → **delete** (holds NewAE internal codes like `RCHIP-1K-0603`)
- Delete Altium cruft: `COMPONENT GROUP/KIND/TYPE`, `PIN COUNT`,
  `PP MATERIAL STACK`, `PP ROTATION`, `MOUNTING TECHNOLOGY`,
  `LATESTREVISIONDATE`, `PUBLISHER`, `SNAPEDA_LINK`, `CHECK_PRICES`,
  `AVAILABILITY`, `PRICE`
- Flatten `${ALTIUM_VALUE}` to literal values on all eleven affected symbols;
  give C5 its missing `100n`
- Populate `Datasheet` on every part

### 6.4 Trigger front-end

```
P1.1  ──┬── R14 100R ──┬── U2 74LVC1G17 ──── GP0 (U1 pad 1)
        │              │     (Schmitt)
J4 ─────┘           R15 10k          │
(DNP)                  │          C6 100n
                      GND            │
                                    GND

R16 (0R, DNP): trigger node ──────── GP0   [bypass; never fit with U2]
```

Non-inverting, preserving the firmware's `wait 1 PIN 0` polarity. Adds ~4.6 ns
propagation delay, negligible against the 8 ns PIO quantum and the ~95 ns IGBT
fall time. GP0 becomes input-only from the header's perspective, which matches
firmware usage.

### 6.5 Designators

Restore upstream's scheme so `BUILD-DRAWING-REV04.PDF` and the README BOM
explainer stay valid: `D6/D8/D9` LEDs, `P1/P2/P3` headers, `J1` = SMA,
`J2` = JST, `J3` = HV tap. New parts take `U2, R14, R15, R16, C6, J4`.

## 7. Layout and design rules

### 7.1 Board setup

2-layer, **1.6 mm thickness — must be stated explicitly on the fab order**. The
edge-mount SMA is specified for 0.062″ (1.57 mm) board and clamps the edge.
Outline stays 40 × 116 mm for 1551B shield fit.

### 7.2 Net classes

Replaces the current single 0.2 mm class with `min_clearance` disabled.

| Class | Nets | Clearance |
|---|---|---|
| HV | T1 secondary → D2 → C3 → Q2 collector → J1 centre; R1 top; J3 | Derived by measurement — see below |
| Default | all others | 0.2 mm |

The HV clearance value is **derived, not invented**: measure the existing board's
actual minimum HV-to-other clearance, then set the rule to that value. That copper
was hi-pot tested at 1 kV upstream, so a rule derived from it enforces "no worse
than the validated board." Open the geometry further wherever the fresh layout
allows it for free.

Restore `min_clearance` to a real value so DRC actually runs.

### 7.3 J3 creepage slot

Milled slot between the two HV pads to break the surface creepage path. The
original 2.07 mm pad gap passes IPC-2221B at ~600 V but fails IEC 60664-1
creepage (≈3.2 mm required), and the BG306's 500 VAC rating is a one-minute proof
test, not a working rating.

Fallback if the slot proves impractical: wider pad separation plus conformal
coating.

### 7.4 HV section

Replicate component placement and copper geometry for T1, T2, C1, C2, C3, D2,
D3–D5, Q1, Q2, R1, R2, J3 from the existing board. Route the logic side freely.
The analog layout is part of what was validated.

Transformer dot orientation must match the assembly drawing — upstream flags this
specifically, and reversing it produced the wrong-polarity spike on the original
prototype.

## 8. Verification gates

Each gate blocks the next.

1. **Git initialised, baseline committed.** *(Done — commit `154c225`.)*
2. **ERC clean** — zero errors.
3. **Netlist diff** against the current board. Every difference must be
   intentional: the trigger front-end, J3, and the designator renames.
4. **DRC clean** under the new HV rules.
5. **3D view + shield fit**, particularly switch actuator heights against the
   1551B half-shell.
6. **Fab output review** — gerbers, drill, slot — before ordering.

## 9. Bring-up

Staged, because the board generates ~500 V.

1. Logic only — omit T1, T2, C3, Q2. Verify 3V3, LEDs, buttons, USB enumeration,
   stock firmware runs.
2. Scope the trigger front-end: feed an edge into P1.1, confirm clean output at
   GP0, measure actual buffer delay.
3. Populate HV section. Arm with **no coil and no probe fitted**; confirm CHARGED
   asserts and the 60 s timeout disarms.
4. First pulses into a resistive test jig, not a coil, with the shield fitted.
5. Compare gate-drive waveform against the scope traces in
   `hardware/design_notes/`. This is the acceptance test for the analog path.

## 10. Items to resolve during implementation

These have defined resolution methods, not open questions:

| Item | Resolution |
|---|---|
| Switch actuator height | Measure the 1551B half-shell clearance with the Pico reflowed flat, then select heights from the C&K KSC7 catalogue. SW3 needs to clear the shield; SW1/SW2 are ergonomic only |
| Switch actuation force | Upstream used 390 gf for SW1/SW2, plausibly a deliberate safety choice. Confirm against the chosen part's datasheet |
| D7 land: SOD-323 vs SOD-323F | Datasheet says SOD-323**F**, 200 mW; the current schematic field says only `SOD323`. Verify against the onsemi datasheet and draw to match |
| D1/D3/D4/D5 land: SOD-123F vs SOD-123FL | MCC's drawing gives a 2.36 mm land span. Verify KiCad's `D_SOD-123F` matches before using it |
| JLC minimum routed slot width | Check JLC's current capability page before committing the J3 slot geometry |

## 11. Out of scope

No FPGA, no on-board ADC or comparator trigger front-end, no change to energy
storage or switch topology, no firmware rewrite. Each is defensible later; none is
needed for a correct 2026 board, and each would require re-validation.

Rationale for deferring the FPGA specifically: the PIO trigger path already runs
at the full 125 MHz, giving an 8 ns quantum. The IGBT's 95 ns fall time and the
gate-drive transformer's 0.4 µH leakage dominate that by an order of magnitude, so
faster digital timing buys nothing. What a ChipWhisperer/Husky actually offers —
clock-synchronous glitching and SAD/pattern triggering — is reachable through the
existing external-trigger path (`picoemp_configure_pulse_external()` sets GP14 to
an input), which this revision improves rather than replaces.

## 12. Provenance and licensing

This repository is grafted onto upstream `newaetech/chipshouter-picoemp` history.
Upstream HEAD is `eb2284d` (2024-08-28) and has not moved since; the working copy
was verified byte-identical to it apart from local additions.

Upstream is licensed **CC BY-SA 3.0**. This revision is a derivative work, so if
published it must carry the same licence and attribute NewAE Technology.

Two defects found during the audit are genuine **upstream** bugs worth reporting:

- **R9** carries R4's part data throughout the Altium source (`RCHIP-75R-0805`,
  `RC0805FR-0775RL`, DK `311-75.0CRCT-ND`) despite a value of 2 k. The published
  `.xls` BOM has the correct `RC0805FR-072KL`, so only the schematic is wrong.
- **APT1608SRCPRV** (D6/D9) is obsolete and no longer manufactured, so the
  published BOM can no longer be ordered as-is.

## 13. Deliverables

- Clean `.kicad_sch` and `.kicad_pcb`
- Project-local symbol and footprint libraries
- DigiKey CSV BOM, cart-ready
- Gerbers and drill files for JLC bare-PCB fabrication
- Build note documenting what changed from REV04

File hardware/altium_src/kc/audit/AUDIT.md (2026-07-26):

# PicoEMP KiCad Port — Audit

Audited 2026-07-25 against upstream `chipshouter-picoemp` REV04 (Altium source, `BOM for ChipShouter-PicoEMP.xls`, and the "BOM explainer" in `hardware/README.md`).

Files audited:
- `ChipShouter-Pico.kicad_sch` (48 real components, flat sheet)
- `ChipShouter-Pico.kicad_pcb` (73 footprint instances, 53 unique refs, 2-layer)
- `chipshouter-pico-mcu.kicad_sch` (orphaned — not referenced by the project)
- `production/` (stale export from 2026-07-23, pre-migration)

---

## 1. Blocking issues — the board is not fabricable in its current state

### 1.1 The PCB carries two parallel copies of the design

20 reference designators have **two footprints each** on the board — the original
Altium-imported one and a new KiCad one placed on top of it:

`C1 C2 C5 R1 R2 R3 R4 R5 R6 R7 R9 R10 R11 R12 R13 MH1 MH2 MH3 J1 J2`

`J1` is the worst case: it holds **two different parts** — the original edge-mount
SMA (`CON-SMA-MALE-PCB-EDGE062`) and a new 1x7 pin header. The SMA was
simultaneously re-created as `J6`.

### 1.2 None of the new footprints are connected

All 384 routed segments sit on the legacy Altium net names (`NetC3_2`, `NetP1_1`,
`NetJ1_2`, `VCC`, …). Every KiCad-style net has **zero** copper:

```
+3V3  /CHARGED  /HVPULSE  /HVPWM  Net-(C1-Pad2)  Net-(C5-Pad2)  Net-(D1-A)
Net-(D1-K)  Net-(D2-K)  Net-(D3-K)  Net-(D4-K)  Net-(D5-K)  Net-(D7-A)
Net-(D7-K)  Net-(J1-Pin_1..6)  Net-(J3-Pin_2)  Net-(J6-Ext)  Net-(LED1-A)
Net-(LED2-A)  Net-(LED3-A)  Net-(R7-Pad2)  Net-(U1-GPIO6/7/11/27/28)
```

Each node now exists twice — once under its Altium name (with copper) and once
under its KiCad name (without). `VCC` (31 pads, routed) and `+3V3` (3 pads,
unrouted) are the same rail, split.

The new symbols have been placed and wired in the schematic, but no clean
"Update PCB from Schematic" has ever completed.

### 1.3 Every header footprint has the wrong pitch

All original headers are **2.54 mm**. Every replacement chosen is 1.00 mm or
1.27 mm — a 2–2.5× pitch error. Measured from the board file:

| Ref | Original footprint | Pitch | New footprint assigned | Pitch |
|---|---|---|---|---|
| P1 → J1 | `Miscellaneous Connectors:HDR1X7` | 2.54 | `PinHeader_1x07_P1.00mm_Vertical` | 1.00 |
| P2 → J4 | `Miscellaneous Connectors:HDR1X2` | 2.54 | `PinHeader_1x02_P1.27mm_Vertical` | 1.27 |
| P3 → J5 | `Miscellaneous Connectors:HDR1X4` | 2.54 | `PinHeader_1x04_P1.00mm_Vertical` | 1.00 |
| J2 | `22-23-2021` (Molex KK) | 2.54 | `PinHeader_1x02_P1.27mm_Vertical` | 1.27 |

J2 is the battery input and the actual part is a **JST XH (2.5 mm pitch)**
`S2B-XH-A(LF)(SN)` — a 1.27 mm header is wrong by 2×.

### 1.4 No project library tables

There is no `fp-lib-table` or `sym-lib-table` in the project directory, and the
global table contains only the stock KiCad libraries. **All 26** custom libraries
referenced by the design are unregistered:

```
main  SamacSys  NewAE_AltiumLib  CKG57N_2220  DSS13UTR  ATB322524  MOUNT_M3_TIGHT
CK_KSC7J  LED-0603-RED  LED-0603-GREEN  GCT_BG306  DPAK_TO-252AA_M  SOT95P245X110-3M
RESC1608X55N  RESC2012X70N  RESC5025X06N  RESC6432X06N  CAPC0805_M  CAPC0603_M
CON-SMA-MALE-PCB-EDGE062  DO-214AC  SOD323  22-23-2021  "Miscellaneous Connectors"
MODULE_SC0915_TH  C__Users_colin_Documents_AltiumLL_SamacSys.PcbLib
```

The board still renders because KiCad embeds full footprint geometry in
`.kicad_pcb`. But nothing can be edited, re-linked, or re-synced, and the project
is not portable to another machine.

---

## 2. Component-level gaps

Full per-reference table: `audit/bom-gap-analysis.csv`

### 2.1 Eight components have no footprint at all in the schematic

`D1  Q2  Q3  Q4  SW1  SW2  SW3  J3`

Q2 is the IGBT and Q3/Q4 are the gate-drive MOSFETs — the three most
layout-sensitive parts on the board.

### 2.2 Nine footprints have no library prefix (invalid in KiCad)

| Ref | Footprint field | Should be |
|---|---|---|
| C3 | `CKG57N_2220` | 2220 / EIA 5750 metric, height ≤5 mm for the shield |
| D2 | `SMA` | `Diode_SMD:D_SMA` (DO-214AC) |
| D3 D4 D5 | `DSS13UTR` | verify actual SM4005PL-TP package |
| D7 | `SOD323` | `Diode_SMD:D_SOD-323` |
| T1 T2 | `ATB322524` | custom — needs a real library entry |
| Q1 | `C__Users_colin_Documents_AltiumLL_SamacSys.PcbLib:SOP254P952X470-6N` | absolute Windows path from the original author's PC |

### 2.3 Two symbols have unresolvable `lib_id`s

- `Q1` → `*:root_0_mirrored_LDA111STR_*` — contains literal wildcards
- `T1`, `T2` → `NewAE_AltiumLib:root_0_xformer_2_2_hv_NewAE_AltiumLib.DBLib`

### 2.4 Wrong symbols chosen

| Ref | Part | Symbol used | Problem |
|---|---|---|---|
| Q2 | RGT16BM65DTL (IGBT) | `Device:Q_NMOS_Depletion` | It's an IGBT, not a depletion MOSFET |
| Q3 Q4 | AO3422 | `Device:Q_NMOS_Depletion` | Enhancement-mode, not depletion |
| D1 D3 D4 D5 | SM4005PL-TP | `Device:D_Schottky_Small` | Standard silicon rectifier |

D1/D3/D4/D5 is worth calling out: this is a **known upstream errata** that the port
inherited. `hardware/README.md` says explicitly that the schematic "claimed they
were Schottky diodes, but as @settinger caught this was never the case."

### 2.5 R9 carries R4's part data — real ordering bug

R9's `Value` is `2k`, but every sourcing field still says 75R:

```
PART NUMBER              RCHIP-75R-0805     (should be RCHIP-2K-0805)
MANUFACTURE PART NUMBER  RC0805FR-0775RL    (should be RC0805FR-072KL)
SUPPLIER PART NUMBER     311-75.0CRCT-ND    (should be 311-2.00KCRCT-ND)
ALTIUM_VALUE             75R                (should be 2k)
```

Ordering from this BOM gets a 75R where a 2k belongs. This is not cosmetic — the
upstream design notes identify the **2k shunt on R9 as the final validated gate-drive
choice**, arrived at after sweeping no-shunt / 2k / 10k / 22k.

### 2.6 C5's value renders literally

Eleven symbols use `${ALTIUM_VALUE}` as their `Value`, which KiCad resolves from a
companion `ALTIUM_VALUE` property. That works for R1–R13. **C5 has no
`ALTIUM_VALUE` property**, so its value displays and exports as the literal string
`${ALTIUM_VALUE}`. C5 should be 100 nF 0603.

All eleven should be flattened to real values regardless — the indirection breaks
any BOM tool that doesn't do variable substitution.

### 2.7 The `PART NUMBER` field is NewAE's internal code, not an MPN

`PART NUMBER` holds values like `RCHIP-1K-0603`, `ATB322524_PROTO`,
`MOUNT_M3_TIGHT`. The real MPN lives in `MANUFACTURE PART NUMBER 1`. Any BOM
export keyed on `PART NUMBER` — which is what the field name invites — produces
unorderable internal codes. The BOM analyzer made exactly this mistake.

Fields to normalize: `PART NUMBER` → `MPN`, `MANUFACTURE 1` → `Manufacturer`,
`MANUFACTURE PART NUMBER 1` → `MPN`, `SUPPLIER PART NUMBER 1` → `DigiKey`.

### 2.8 J1–J5 are all DNP and excluded from BOM

Defensible for J3 (HV calibration, upstream says optional) and arguably the debug
headers. **Not** defensible for J2 — that's the battery power input.

### 2.9 Zero LCSC part numbers

Not one component has an LCSC number. `production/bom.csv` has an empty
`LCSC Part #` column on all 28 lines. Nothing can be assembled by JLCPCB yet.

---

## 3. Not in the BOM at all (off-board, upstream Part 4)

| Item | Upstream PN | Note |
|---|---|---|
| Enclosure | Hammond `1551BTRD` | 3D-printable alternative in `hardware/shield/` |
| Battery holder | Sparkfun `PRT-09925` | 2×AA with switch, JST-XH pigtail → J2 |
| Probe SMA | `CONSMA013.062` | mates with J6 |
| Probe inductor | `PCV-0-472-03L` | |
| Ferrite | `744710603` | |
| USB isolator | Seeed `114991949` or Adafruit `2107` | **strongly recommended** in operation |

---

## 4. Design-rule observations

- Board is 2-layer — fine and cheap at JLCPCB.
- **There is no high-voltage net class.** A single netclass (`Default` / `All Nets`)
  applies 0.2 mm clearance to everything, and `min_clearance` is set to `0.0`
  (disabled). This board generates ~500 V and upstream hi-pot tests it at 1 kV.
  The existing copper inherits the Altium spacing, but nothing in the current rule
  set protects it — any re-route will silently close the isolation gap.
  Add an `HV` netclass covering `NetC3_2` / the transformer secondary / J3 / J6
  before touching the layout.
- `EXCLUDE DNP` is `false` in `fabrication-toolkit-options.json` while J1–J5 are
  marked DNP. Decide which behaviour you want before exporting.

## 4a. READ THIS FIRST — net state of the sourcing findings

Sections 4b–4g were written as research landed, and later passes corrected
earlier ones. **This table is the reconciled answer.** Where a later section
contradicts an earlier one, the later one wins.

### Lifecycle — the parts with no forward path

| Ref | Part | Status | Successor |
|---|---|---|---|
| T1 T2 | ATB322524-0110-T000 | **NRND** (§4b, §4e) | **None from any vendor, any package** |
| Q2 | RGT16BM65DTL | **NRND** (§4e — §4b said Active, wrong) | None at ROHM in DPAK → **STGD6M65DF2** |
| D6 D9 | APT1608SRCPRV | **Obsolete** (§4c, §4g) | KT-0603R / APT1608SURCK |

Everything else on the board is Active. Buy T1/T2 and Q2 in quantity now.

### Long lead times on Active parts

D7 MM3Z18VB **39 wk** · US1J-13-F **32 wk, currently out of stock** ·
LDA111STR **23 wk** · C1/C2 TDK **24 wk** · U1 SC0915 **18 wk** ·
R2 3522300KFT **17 wk** · C5 KEMET **12 wk**

### Traps that will bite you

1. **The LCSC SMA does not fit your footprint.** Molex `C841205` has 8.76 mm
   ground pitch + 2 drilled locating holes; your `SMA_Amphenol_132289_EdgeMount`
   has 8.50 mm and no holes. Respin or consign. (§4g — §4c was wrong.)
2. **D7's footprint field says `SOD323`; the part is SOD-323F.** Different land.
   (§4f)
3. **Pico W / Pico 2 W are not drop-ins** — GPIO23/24/25/29 are reassigned to the
   radio. Plain Pico 2 (SC1631) *is* a clean swap. (§4g)
4. **BG306 `-2-` is the R2 mirrored land pattern**; R1 is the stocked standard.
   And `-G` is bulk box, not reel. (§4d)
5. **TL3301 QJ vs QG is lead form**, not packaging — J-lead vs gull wing, not
   footprint-compatible. (§4c, §4d)
6. **SM4005PL is standard recovery (trr 1–3 µs)**, MURA160/US1J are 75 ns. Never
   treat them as alternates for each other. (§4f)
7. **Don't sub CRCW-HP or RCA for R1** — those are anti-surge families, not
   high-voltage. R1's schematic property claiming 400 V is wrong; the real
   CRMA2010 rating is 2000 V. (§4f)
8. **Green LED Vf matters** — an emerald-green 525 nm part at Vf 3.1 V gives
   ~0.2 mA through the existing 1 k and is invisible. (§4c)

### Corrections to my own earlier claims, for the record

| Claim | Where | Corrected to |
|---|---|---|
| Q2 RGT16BM65DTL is Active | §4b | **NRND at ROHM** (§4e) |
| AO3422 is 30 V | brief | **55 V**, and load-bearing (§4c) |
| PMV37ENEAR "don't design it in" | §4c | **Active at Nexperia** — fine by hand, not via JLC (§4d) |
| TL3301AF160QJ has no LCSC listing | §4c | **`C273520` exists**, Active, 11-wk lead (§4d) |
| All three SMAs interchangeable | §4c | **Molex is not** (§4g) |
| D7 is SOD-323, 300 mW | §4b | **SOD-323F, 200 mW** (§4f) |
| CRMA2010 is 400 V rated | §2.7 metadata | **2000 V** (§4f) |
| "Standardize all three switches" | §4c | Valid, but SW3's 5 mm height is deliberate (§4d) |

### Assembly reality at JLCPCB

Only **one** part on the board is a JLCPCB Basic part as-designed. Adopting the
§4c/§4b swaps (C5, D2, red LED) adds three more. Everything else is Extended →
per-line setup fee.

**Cannot be machine-placed regardless of part choice:** the edge-mount SMA
(wave/manual, $3.50 + $0.0173/joint, +1 day), the JST XH if added (through-hole),
and the HV output connector (absent from JLC's library, and specified in bulk
box packing).

## 4b. Sourcing & lifecycle — HV path

Verified against LCSC/JLCPCB parts library and manufacturer pages, 2026-07-25.
Stock figures go stale; re-check before ordering.

### The one part that should change your plans

**T1/T2 — ATB322524-0110-T000 is Not For New Designs.** Digi-Key lists Product
Status "Not For New Designs"; other distributors report "PRODUCTION (NOT
RECOMMENDED FOR NEW DESIGN)". The series has exactly two members
(`ATB322524` and the 1.5 mm-tall `ATB322515`, `C415291`) and **both are NRND**.
There is no TDK successor series, and no equivalent 3.2×2.5 mm 1:10 SMD step-up
transformer from Würth, Coilcraft, Sumida or Murata.

Good news: contrary to its reputation it is currently **well stocked** —
`C249001`, LCSC retail 4,721 / JLCPCB library 973, $0.42 @1k. **Buy a lifetime
supply now.** This part is the single point of failure for the whole design.

Also note its withstanding voltage is **500 Vrms** on a ~500 V rail — essentially
zero margin. That's inherent to the original design, not something the port
introduced.

### JLCPCB assembly economics

**Only one part in the entire HV path is a JLCPCB Basic part** (US1M, and only if
you adopt it as the D2 substitute). Everything else is Extended, which means a
per-line setup fee. Budget for that, or accept hand-assembly on some lines.

### Per-part findings

| Ref | Part | Status | LCSC | Action |
|---|---|---|---|---|
| Q2 | RGT16BM65DTL | Active | `C3193927`, **retail stock 22** | Stock is the risk, not lifecycle |
| Q1 | LDA111STR | Active | `C17531663` | See note below |
| T1 T2 | ATB322524-0110-T000 | **NRND** | `C249001` | Buy lifetime supply |
| C3 | KRM55TR72J474MH01K | — | **not stocked** | Substitute required |
| D2 | MURA160T3G | Active | `C50432` **stock 0** | Substitute required |
| D1 D3 D4 D5 | SM4005PL-TP | Active | `C151774` retail only — **not in JLC assembly library** | Substitute required for PCBA |
| D7 | MM3Z18VB | Active | **not stocked** | Substitute required |
| R1 | CRMA2010AF20M0FKEF | Active | `C2091374` | Keep |
| R2 | 3522300KFT | Active | `C4262190` | Can downgrade — see below |

### Substitutions worth taking

- **D2 → US1M (`C412437`).** SMA, **1000 V** vs 600 V, same trr 75 ns, a
  **JLCPCB Basic part** with 503k in stock, and ~20× cheaper ($0.006 vs $0.10).
  Strictly better than both the original and upstream's `US1J-13-F` suggestion.
  600 V on a ~500 V rail plus flyback overshoot was always thin.
- **D1/D3/D4/D5 → ES1J (`C2892680`).** SOD-123FL, 600 V 1 A, JLC stock 53k,
  $0.005. Required anyway since the original isn't in the assembly library.
- **D7 → MM3Z18VST1G (`C236092`).** onsemi SOD-323, Vz 17.56–18.35 V (**±2%**) —
  the same tolerance grade as the "B" suffix original. Do **not** reach for
  `BZT52C18S` (±5%) unless you have to; upstream warns this zener "drastically
  affects the drive waveform," and a failed D7 destroys Q2.
- **C3 → FM55X474K631EFG (`C692326`).** 0.47 µF 630 V X7R 2220, $0.40 @1k.
  The board's `CKG57N_2220` land (8.0 mm span, 4.0 mm gap) accepts both
  metal-terminal and plain 2220 chips, so no footprint change.
  Two caveats: any 630 V class-2 MLCC loses a large fraction of its capacitance
  at 500 V DC bias (true of the original too), and the Murata KRM55 /TDK CKG57N
  metal terminals exist specifically for **board-flex crack protection** — a
  plain 2220 gives that up.
- **R2 → RC2512FK-07300KL (`C137027`), optional.** $0.036 vs $0.62. Safe because
  R2 is *not* a high-voltage position: it sits in series *below* the opto LED
  (HV → R1 20 M → Q1 LED → R2 300 k → GND), so at ~24 µA it drops only ~7.4 V and
  dissipates ~0.2 mW. R1 takes essentially the entire 490 V. Keep the TE part only
  if you want margin against R1 failing short.

### Substitutions to be careful with

- **Q2.** Any IGBT replacement **must** have a co-packed antiparallel diode.
  Best drop-in is **STGD6M65DF2 (`C472580`)** — ST, TO-252, 650 V, same G/C/E
  pinout, soft/fast antiparallel diode, JLC stock 808, $0.68.
  `AOD5B65MQ1E` (`C3193928`) is cheaper but has roughly half the current and
  power (52 W vs 94 W) and a lower Vge(th) of 4.2 V, so it turns on earlier —
  recheck gate drive and the D7 clamp if you use it.
  **Avoid** `ISL9V3040D3ST-F085C` (400 V clamped ignition IGBT — will avalanche)
  and `NCE07TD60BK` (no co-packed diode found in its datasheet).
- **Q1.** Correction to the audit above and to common description: LDA111STR is
  **not** a solid-state relay. It's a unidirectional-input optocoupler with a
  **Darlington output**, CTR min 300%, BVceo only 30 V. The isolation is the
  barrier, not the output rating. In circuit the LED is fed through R1 (20 M) off
  the ~500 V rail, so **LED current is only ~24 µA** — that is precisely why
  upstream says other optos won't work as-is. Candidate subs (`4N33SR2M`
  `C898962`, `TIL113SM` `C900043`) share the standard 6-pin opto pinout and fit
  `SOP254P952X470-6N`, but are all specified at **If = 10 mA**. Expect to drop R1
  to ~4.7 M for usable CTR, which quadruples bleeder current and shortens HV
  decay. Upstream notes the feedback circuit can simply be omitted.
- **R1.** Keep `CRMA2010AF20M0FKEF`. It is effectively the only 20 MΩ HV-rated
  2010 at LCSC, and its margin is comfortable (0.5 W, 2000 V working vs ~490 V
  actual — 4×). **Do not drop in a plain CRCW/RC 2010**: standard 2010 thick
  films are 200 V working and will drift or arc at ~490 V.

### Correction to §2.4 above

The agent's schematic read shows D1/D3/D4/D5 are **not** in the 500 V path.
D3/D4 sit on the HVPWM gate-drive line to Q3, D5 on HVPULSE to Q4, and D1 is
battery-input protection at J2. Their 600 V rating is safety margin against
isolation breakdown, not a working requirement — consistent with upstream's
"in circuit they will be exposed to 4V max ever." The wrong *symbol*
(`D_Schottky_Small`) is still worth fixing; the part choice is not urgent.

Also: the `DSS13UTR` footprint geometry (pads 1.15 × 1.30 mm at ±1.55 mm,
4.25 mm span) confirms **SOD-123FL** — not SMA/DO-214AC and not SMAF.

### Not independently verified

Digi-Key/Mouser "Product Status" flags for LDA111STR, CRMA2010AF20M0FKEF and
MM3Z18VB could not be surfaced directly. TDK's own product pages for both ATB
parts returned HTTP 403, so the NRND status rests on Digi-Key and secondary
distributors rather than TDK directly.

## 4c. Sourcing & lifecycle — logic, connectors, switches, LEDs

### Obsolete or unavailable

- **D6/D9 red LED `APT1608SRCPRV` is OBSOLETE** at Kingbright, and has no LCSC
  listing. Must be replaced. → **`C2286` KT-0603R**, JLCPCB **Basic**,
  7.8 M in stock, $0.0053. Clean drop-in.
- **SW3 `TL3301AF160QJ` — no LCSC listing**, and all QJ variants are dead stock
  (15 / 16 / 0 units across the family).
- **J3 `BG306-02-A-2-0400-L-G` — not on LCSC at all.** Consign or substitute.
- **C1/C2 `C2012X5R1H475K125AB`** — exact MPN not on LCSC (nearest TDK has 87 units).
- **`S2B-XH-A` was never ported.** Zero occurrences in the KiCad schematic —
  J2 carries the Molex KK-254 (`22-23-2021`) identity instead. If you want the
  JST XH battery input, it needs adding: `C157931`, 2.5 mm pitch, THT.

### AO3422 — the datasheet spec I gave you was wrong

Q3/Q4 are **55 V / 2.1 A**, not 30 V. That matters: tracing the schematic, Q3
(gate `HVPWM`) and Q4 (gate `HVPULSE`) each drain into an ATB322524 **flyback
primary**. The drain sees Vin + reflected voltage + leakage spike, so the 55 V is
deliberate headroom, not incidental. Vgs(th) is 0.6/1.3/2.0 V and the part is
characterized to 2.5 V gate drive, so 3.3 V RP2040 drive has ≥1.3 V worst-case
overdrive — fine.

Status: **Active** (Digi-Key, 608 k stock). One small distributor shows NRND —
an outlier. Note the **AO3422L** variant *is* obsolete; don't order that.
LCSC `C37130`, JLC assembly stock 28 k, Extended.

Upstream's suggested alternate **PMV37ENEAR is effectively unavailable**
(`C553095`, LCSC retail stock **1**). Do not design it in.

**There is no JLCPCB Basic equivalent at 55 V.** The only Basic SOT-23 N-channel
parts ≥30 V are 2N7002 (`C8545` — 115 mA, far too weak) and AO3400A (`C20917` —
only 30 V).

→ **CJ2310 (`C75882`)** is the best swap: 60 V, 3 A, identical Vgs(th) window
(0.5–2.0 V), *lower* Rds(on) (125 mΩ vs 160 mΩ @4.5 V), same SOT-23 pinout,
262 k in stock, $0.031 — 9× the stock at half the price of the AO3422.
AO3400A only if you add a primary snubber and scope the drain ringing to confirm
it stays under 30 V; chasing "Basic" here costs 25 V of avalanche margin on a
flyback switch.

### Switches — assembly stock is the blocker, and SW3 has a lead-form trap

**SW1/SW2 `KSC741JLFS`** is Active at C&K, LCSC retail 12,874 — but **JLC
assembly stock is only 39**. At two per board that's ~19 boards.
→ `C221750` **KSC441JST2LFS**, same C&K 6.2×6.2 mm J-lead family, IP67, 957 in
stock. Verify the J-lead pad pattern is identical before committing.

**SW3:** in the E-Switch TL3301 series the final letter is the **lead form** —
**QJ = J-lead, QG = gull-wing**. They are *not* footprint-interchangeable. The
available `C273519` TL3301AF160**QG** has the same actuator height and 160 gf
force but needs a gull-wing pad change.

This reconciles with upstream's note that "SW1 SW2: you can use the same PN as
SW3 (the footprint is the same)" — that holds for the J-lead QJ part against the
J-lead KSC741J, not for the QG.

⚠️ **Schematic/PCB mismatch on SW3**: the schematic says `TL3301AF160QJ` with no
footprint; the PCB places `CK_KSC7J` (the KSC741J footprint). Cleanest resolution
is to **standardize all three switches on one part** — which also fixes the SW1/SW2
stock problem.

Note the force change if you go cheap: `C318884` (Basic, 918 k stock, $0.018) is
**160 gf vs 390 gf**. These are the arm/trigger buttons; the heavy action is
arguably a deliberate safety feature. Treat that as a design decision, not a
substitution.

### J3 — the HV output connector is over-stressed ⚠️

C3 is a 0.47 µF / **630 V** storage cap, so this 0.1"-pitch connector carries
roughly **500–600 V**.

Measured J3 pad geometry from the board file: pads 1.02 × 1.9 mm, offset
(2.54, −3.3) mm → **closest corner-to-corner spacing ≈ 2.07 mm**.

| Standard | Requirement at ~600 V | Result |
|---|---|---|
| IPC-2221B, external uncoated | ≈0.50 mm | **passes** |
| IEC 60664-1 creepage, PD2, mat. group IIIa | ≈3.2 mm | **fails** |

But the binding constraint is the connector itself: the BG306's **500 VAC
dielectric withstanding voltage is a one-minute proof test, not a working
rating**. Good practice puts DWV at 2–3× working voltage. Running ~600 V against
a 500 V proof test leaves *negative* margin.

Options, in order:
1. **Go wider pitch** — `C25170858` PZ508V (5.08 mm, THT, $0.064) or JST VH
   3.96 mm (`C16728` VH-2A, 111 k stock, $0.023). 1.5–2× the creepage.
2. **Keep 2.54 mm but mill a slot between the two HV pads** to break the surface
   creepage path, plus conformal coating. Cheapest fix, keeps existing injection
   tips compatible.
3. If you must stay 2.54 mm SMD: `C5142235` or `C42381025` — but both are
   **right-angle** while the BG306 is top-entry vertical, so almost certainly not
   a drop-in.

### Edge-mount SMA

Amphenol **132289**, Cinch **142-0701-801** and Molex **73251-1150** are
cross-referenced as interchangeable, all 50 Ω edge-mount for 0.062" board — so
your `Connector_Coaxial:SMA_Amphenol_132289_EdgeMount` choice is sound. Caveat:
Molex describes theirs as right-angle vs end-launch for the other two; verify
ground-tab and center-pin geometry.

Only the Molex is on LCSC — `C841205`, JLC 2,684, **$4.19** (by far the most
expensive part on the board), Extended.

⚠️ **Avoid the cheap "SMA-KE" parts** (`C496549`, `C504007`, ~$0.40). Their
datasheets show **vertical PCB-mount jacks** — transmission perpendicular to the
board. Not edge-launch, not drop-ins, despite matching the search terms.

**JLC cannot machine-place this** — an edge-mount connector straddles the board
edge. Hand-solder regardless.

### Green LED — check Vf before substituting

D6/D8/D9 run from **+3V3 through 1 k** (R11/R12/R13). The original APT1608CGCK is
a 570 nm yellow-green at Vf ≈2.2–2.5 V → ~0.8–1.1 mA. An "emerald green" 525 nm
InGaN part at Vf ≈3.1 V gives **~0.2 mA — essentially invisible**.

There is **no JLCPCB Basic 0603 green LED**; the only Basic 0603 parts are red
and white. → **`C965805` XL-1608SYGC-06**, Vf 2.2 V, 570–575 nm, 730 k stock,
$0.006. If you want the Basic 0805 green (`C2297`) you must also drop R11–R13 to
~100–220 Ω.

### Raspberry Pi Pico

`C7203002`, JLC stock **834**, $6.16, Extended. Low stock plus high price makes
this a common order-blocker; realistic options are consignment or hand-soldering.

**Pico 2 (SC1631) is pin-compatible** — same 40-pin castellated layout, same
51×21 mm outline, same BOOTSEL/USB/LED placement, and GPIO23/24/25/29 keep their
functions. Only physical difference is one extra underside test pad. But **the
plain Pico 2 is not on LCSC** (only Pico 2 W, `C42394205`).
*Unverified:* whether the RP2350 A2 GPIO input erratum affects any PicoEMP input
path — worth checking before switching, since this tool reads GPIO.

### Cheap wins

- **C5 → `C14663` CC0603KRX7R9BB104** (YAGEO 100 nF 50 V X7R 0603): JLCPCB
  **Basic**, 81 M stock, **$0.0022** vs $0.0186. No reason not to.
- **C1/C2 → `C98192` CL21A475KBQNNNE** (Samsung 4.7 µF 50 V X5R 0805), 1.18 M
  stock, $0.018. Keep 50 V — C1/C2 sit on the flyback primary rail where the
  designer wanted ringing headroom; the nearest Basic part is only 25 V.

### Cannot be machine-assembled by JLCPCB, whatever part you pick

The edge-mount SMA (J1/J6), the JST XH if you add it (through-hole), and the HV
output connector (absent from JLC's library). Budget for hand-soldering or
consignment on those three.

### Recommended swap summary

| Ref | From | To | LCSC | Why |
|---|---|---|---|---|
| Q3 Q4 | AO3422 | CJ2310 | `C75882` | 60 V, better Rds(on), 9× stock, ½ price |
| SW1 SW2 | KSC741JLFS | KSC441JST2LFS | `C221750` | JLC stock 39 → 957, same family |
| SW3 | TL3301AF160QJ | standardize with SW1/SW2 | — | QJ unavailable; QG is a different lead form |
| J3 | BG306 (2.54 mm) | wider pitch, or slot the PCB | `C16728` / `C25170858` | 600 V on a 500 V-DWV 0.1" connector |
| D6 D9 | APT1608SRCPRV | KT-0603R | `C2286` | **obsolete** → Basic, 7.8 M stock |
| D8 | APT1608CGCK | XL-1608SYGC-06 | `C965805` | Vf 2.2 V matches the 1k/3V3 drive |
| C1 C2 | TDK C2012X5R… | CL21A475KBQNNNE | `C98192` | not on LCSC → 1.18 M stock |
| C5 | KEMET C0603C104 | CC0603KRX7R9BB104 | `C14663` | Basic, 8× cheaper |
| D2 | MURA160T3G | US1M | `C412437` | Basic, 1000 V vs 600 V, 20× cheaper |
| D1 D3 D4 D5 | SM4005PL-TP | ES1J | `C2892680` | original absent from JLC library |
| D7 | MM3Z18VB | MM3Z18VST1G | `C236092` | not stocked; ±2% grade preserved |
| C3 | KRM55TR72J474MH01K | FM55X474K631EFG | `C692326` | not stocked |
| R2 | 3522300KFT | RC2512FK-07300KL | `C137027` | optional; 20× cheaper, not an HV position |

## 4d. Corrections — verified against manufacturer datasheets

A later lifecycle pass contradicted several claims in §4c. These supersede it.

### PMV37ENEAR is Active at Nexperia — I overstated the case against it

§4c said "effectively unavailable — do not design it in." That was based on LCSC
stock of 1, and it conflated *LCSC availability* with *lifecycle*.

Nexperia's product page states **"Product status: Production."** It is a good
part: 60 V, 3.5 A, Vgs(th) 1.3/1.7/2.7 V, Rds(on) 64 mΩ @4.5 V, AEC-Q101
qualified, Tj to 175 °C. The `R` suffix is just reel packaging — Nexperia's
ordering table lists the base type `PMV37ENEA`.

**Correct statement:** perfectly viable for a hand build ordered from
DigiKey/Mouser; not viable through LCSC/JLCPCB assembly. If you're going the
JLC-assembly route, CJ2310 is still the recommendation — but on threshold it's
worth noting the AO3422 (0.6–2.0 V) and CJ2310 (0.5–2.0 V) both have a *lower*
Vgs(th) window than the PMV37ENEA (1.3–2.7 V).

### TL3301AF160QJ is listed at LCSC and is Active at E-Switch

§4c said "no LCSC listing" and left lifecycle unverified. Both wrong:

- **Active** at E-Switch per Digi-Key, with an 11-week standard factory lead time.
  Also stocked at Newark, Future, Heisener.
- **It is on LCSC as `C273520`** — poorly stocked, but it exists. The
  well-stocked QG variant is `C273519`.

The QJ/QG distinction holds and is slightly richer than stated: in the TL3301
ordering scheme the two trailing characters are **contact material** (`Q` = silver,
`R` = gold) then **termination** (`J` = J-lead, `G` = gull wing). Same 6×6 mm
switch either way, but J-lead pads tuck under the body and gull-wing pads extend
outward — **not footprint-compatible**.

### "Standardize all three switches" needs a caveat — the height difference is deliberate

| | Body | Actuator height | Force |
|---|---|---|---|
| KSC741J LFS (SW1/SW2) | 6.2 × 6.2 mm | **4.30 mm** | **390 gf** |
| TL3301AF160QJ (SW3) | 6.0 × 6.0 mm | **5.00 mm** | 160 gf |

Upstream's README says SW3 "should be 5mm high to provide clearance," and
separately that "if you are mounting R-Pi Pico with pins you probably want higher
switches (like SW3)." So the taller actuator on SW3 is an intentional mechanical
choice, not an accident of sourcing.

Standardizing is still the cleanest fix for the schematic/PCB mismatch, but pick
the height against your actual build: 5 mm if the Pico is on pin headers or you
want discharge-button clearance through the shield, 4.3 mm if the Pico is
reflowed flat. Both parts are J-lead, so the land pattern is the compatible axis —
that is what upstream's "the footprint is the same" refers to.

Also note the feel difference is large (390 gf vs 160 gf). §4c flagged the heavy
action as a possible safety feature on the arm/trigger buttons; that reading is
supported by the fact that SW1/SW2 got the 390 gf part and the optional discharge
button got the 160 gf one.

### BG306 — two ordering-code details that affect your layout and assembly

Verified against GCT's factory drawing (Rev D3). The part is a **female socket**
(2.54 mm pitch, vertical top-entry, SMT, LCP, phosphor bronze, gold flash),
mating with GCT BG301/303/304/305 pins. 3 A, **500 VAC DWV** — confirming §4c.

Decoding `BG306-02-A-2-0400-L-G`:

- **`-2-` is the R2 land pattern**, not a mounting or gender option. R1 and R2
  differ only in the solder-pad offset relative to pin 1 (mirrored). **R1 is the
  more commonly stocked variant** and is what GCT treats as standard.
  ⚠️ **Verify your J3 pads match R2**, not R1 — this is exactly the kind of thing
  an Altium→KiCad footprint port gets backwards.
- **`-G` is plastic-box bulk packing** (1,000 pcs MOQ), *not* tape and reel.
  Tape-and-reel (`B`) is only offered for 3–8 contacts **and only on the standard
  R1 footprint**. So R2 + reel may not be a stocked combination at all — meaning
  this part cannot be machine-placed as specified regardless of who assembles it.

Both points reinforce §4c's recommendation to move J3 to a wider pitch: you'd be
solving the creepage problem and the packaging problem at the same time.

### S2B-XH-A is side-entry, not vertical

If you add the JST XH battery input: `S2B-XH-A` is **side-entry (right-angle)**
through-hole. **`B2B-XH-A` is the top-entry (vertical) counterpart** — same
family, same 2.5 mm pitch. The `S` vs `B` prefix is exactly this distinction.
3 A, 250 V, −25 to +85 °C.

Pick deliberately: the original board takes the battery pigtail off the edge,
which is what the side-entry part is for.

### Confirmed, no change

- **AO3422**: Active/Production, datasheet Rev 2.1 (March 2024). 55 V, 2.1 A,
  Vgs(th) 0.6/1.3/2.0 V, explicitly rated for 2.5–12 V gate drive. §4c's
  correction to the 30 V figure stands.
- **KSC741J LFS**: Active. SMT **J-bend** (the `J` in the part number is the
  termination option), IP67, 300k cycles, 50 mA @ 32 VDC.

*Caveats from this pass:* aosmd.com 404'd and C&K/Littelfuse returned 403 to
automated fetch, so AO3422 and KSC741J statuses rest on Digi-Key/Mouser plus
current-dated datasheets rather than manufacturer lifecycle pages.

## 4e. Correction — Q2 is also NRND. Two of three critical parts are now on notice.

### RGT16BM65DTL is NRND at ROHM

§4b said "Active — Rohm's product page lists it as Recommended." **That is wrong.**
ROHM's own product page states **"Not recommended for new designs."** Distributors
have not caught up — Digi-Key still shows Active with 8,984 in stock, which is
where the earlier reading came from.

The whole low-current RGT branch is NRND, not just this part:

| Part | Package | Status at rohm.com |
|---|---|---|
| RGT16BM65D | TO-252 / TO-252GE | Not recommended for new designs |
| RGT8BM65D | TO-252GE | Not recommended for new designs |
| RGT16NL65D | LPDL / TO-263L | Not recommended for new designs |
| RGT16NS65D | LPDS / TO-263S | Not recommended for new designs |

**There is no ROHM successor in DPAK.** Reading ROHM's 2024 shortform IGBT
catalog: the TO-252 column across the entire 650 V Field Stop Trench portfolio
contains exactly two parts — RGT8BM65D (4 A) and RGT16BM65D (8 A) — and both are
now NRND. Every newer 650 V family is large-package only and ≥20 A:

- RGTV (tsc 2 µs) — TO-220NFM, TO-247N/GE
- RGS (tsc 8 µs) — TO-220NFM, TO-3PFM
- RGTH / RGW / RGWS (high & ultra-high speed) — TO-247N, TO-247GE

ROHM publishes **no named replacement** — the product page offers only a generic
"Recommended Products Search." No PCN or cross-reference document was found.

Two spec corrections while we're here: **VGES is ±30 V**, not ±20 V (unusually
high, and useful headroom given D7 clamps the gate at 18 V). And RGT is *not* a
high-speed family in ROHM's own taxonomy — it's the 5 µs short-circuit-tolerant
general-inverter series (the fast families are RGW/RGWS/RGTH). At tf 95 ns it's
still fine for this flyback.

### What this means

The upstream README names five parts as "very hard to sub and core to the
design." **Two of them are now NRND**, and they are the two with no drop-in
replacement anywhere:

| Part | Role | Status | Successor |
|---|---|---|---|
| **T1/T2 ATB322524** | HV flyback transformer, ×2 per board | NRND | **none — no vendor, any package** |
| **Q2 RGT16BM65DTL** | Main pulse switch | NRND | none at ROHM in DPAK; other vendors only |
| Q1 LDA111STR | HV sense opto | Active | n/a — but **23-week lead time** |
| D7 MM3Z18VB | Gate clamp | Active | MM3Z18VST1G |
| U1 SC0915 | Pico | Active | Pico 2 pin-compatible |

Both NRND parts still have healthy distributor stock today. Neither is EOL. But
the design has no forward path on either without a vendor change, and one of
them (the transformer) has no equivalent from *anyone* in that footprint.

**Practical stance:** buy Q2 and T1/T2 in quantity now, same as the transformer
advice in §4b. For Q2 specifically, §4b's recommendation to move to
**STGD6M65DF2 (`C472580`)** is now more than a stock workaround — it's the
lifecycle answer too, since ST's part is in full production and ROHM has no DPAK
path forward. Confirm the co-packed antiparallel diode requirement holds.

If you ever do consider a MOSFET instead (upstream says "in theory you can use a
MOSFET, pinout should be compatible"), a 650 V DPAK superjunction part like ROHM
**R6507END3** exists — but that's a real circuit change, not a drop-in: no
co-packed FRD, different tail-current behaviour, different gate drive.

### LDA111STR — confirmed Active, with a supply caveat

Digi-Key: Active, 1,515 in stock, 7,000 factory stock, **23-week manufacturer
lead time**. That lead time is worth treating as a soft supply warning even
though the lifecycle is clean.

Corroborates §4b: it is a **Darlington-output optocoupler**, not an SSR —
Littelfuse files it under Optocouplers → Single Optocouplers. VCEO **30 V**,
100 mA, CTR 300–30,000% @ IF = 1 mA, isolation 3750 Vrms.

New and useful: **turn-on 8 µs, turn-off 345 µs.** That is slow — fine for the
enable/interlock/HV-sense role it actually has, and conclusively useless for
pulse timing. Anyone tempted to repurpose it should know that.

Suffixes: `LDA111` = 6-DIP, `LDA111S` = 6-SMD gull-wing, `LDA111STR` = same on
tape and reel. Littelfuse does **not** cross-reference the OptoMOS SSRs
(CPC1017N, CPC1002N, LCA110) as replacements — those are MOSFET-output relays
with entirely different characteristics.

### ATB322524 — confirmed, with the full family table

| Part | Ratio | L @100 kHz | DCR pri/sec | Leakage | Withstand | Rated I | Size (mm) |
|---|---|---|---|---|---|---|---|
| ATB322515-0110-T000 | 1:10 | 7.0 µH ±20% | 0.5 Ω / 60 Ω | 0.4 µH | 500 Vrms | 0.6 A | 3.2 × 2.5 × **1.55** |
| ATB322524-0110-T000 | **1:10.2** | 7.0 µH ±20% | 0.5 Ω / 60 Ω | 0.4 µH | 500 Vrms | 0.7 A | 3.2 × 2.5 × **2.4** |

That is the entire ATB3225 step-up family — two parts, both NRND. Decode:
`ATB` + `322524` (L×W×T) + `-0110` (turn ratio) + `-T` (taping) + `000`.
No other ratio codes exist.

A Digi-Key forum thread asking this exact question got the reply from Digi-Key
tech support that they could not find an alternative. Nearest functional
relatives are much larger and pin-incompatible: Coilcraft **LPR6235**
(6.2 × 3.5 mm, 1:20/1:50/1:100) and Würth **74488540070/120/250**
(1:100/1:50/1:20) — both need a new footprint and a reworked flyback ratio.

### Verification caveats for this pass

rohm.com was read directly, so the Q2 NRND call is first-hand. But
littelfuse.com and product.tdk.com both returned HTTP 403 to automated fetch, so
the LDA111 and ATB322524 statuses still rest on Digi-Key plus TTI/Octopart
mirroring the manufacturer-declared status, not on manufacturer lifecycle pages.
No TDK PCN or last-time-buy date was found — that needs a direct query to TDK or
a franchised distributor.

## 4f. Corrections — D7 package, diode recovery class, R1 voltage rating

### D7 is SOD-323**F**, 200 mW — your footprint field says `SOD323` ⚠️

Read from the onsemi B-series datasheet: MM3Z18VB is **SOD-323F (SC-90)**, the
**flat-lead** variant, at **200 mW** — not plain SOD-323 at 300 mW. Several
distributor listings state "SOD-323 / 300 mW" sloppily, which is where the wrong
figure in §4b came from.

**SOD-323F and SOD-323 are different land patterns.** Your schematic's Footprint
field is the bare string `SOD323` (already flagged in §2.2 as having no library
prefix) — when you give it a real library reference, make sure it resolves to
**SOD-323F**, not SOD-323.

This also affects the §4b substitute: `MM3Z18VST1G` was described as
"SOD-323, 300 mW." Verify the package of whatever you pick actually matches the
land you draw. Note there is a near-identical Diotec part **MM3Z18** (no `VB`) at
300 mW / ±5% — easy to order by mistake.

Manufacturer is **onsemi**, originally **Fairchild** (onsemi absorbed them in
2016). No genuine alternate manufacturer for this exact MPN was found in
distributor catalogs. **39-week factory lead time** at Digi-Key despite ~369 k in
stock.

### SM4005PL-TP is STANDARD recovery — trr 1000–3000 ns

From MCC's own datasheet: **trr = 1000 ns min / 3000 ns max**. That is
**~15–40× slower** than MURA160T3G or US1J (both 75 ns).

**These are not interchangeable.** If SM4005PL and MURA160/US1J ever end up on
the same BOM line or listed as alternates for each other, that substitution is
only valid for 50/60 Hz line rectification — not in any switching, snubber or
flyback role.

In this design that's tolerable, because §4b established D1/D3/D4/D5 sit on gate
drive lines and battery input rather than the HV path. But it does mean §4b's
suggested **ES1J (trr 35 ns)** is a *faster* part than the original, not an
equivalent one — the closest true functional twin is **S1JFL (`C894229`)**,
standard recovery, SOD-123FL. Either works here; know which you're choosing.

Package confirmed **SOD-123FL** from MCC's package drawing (3.30–3.85 mm overall,
land pattern 0.91 × 1.22 mm on 2.36 mm span). SOD-123FL = DO-219AB = SMF =
S-Flat = "SMAF" are the same flat-lead family.

Nice detail that explains the whole `D_Schottky_Small` confusion in §2.4:
**DSS13U is a real part — an SMC Diode Solutions 30 V 1 A Schottky in SOD-123FL.**
The Altium footprint got its name from a Schottky part that shares the package,
which is very likely how the wrong symbol class propagated into the schematic.

Also: MCC does **not** make a non-PL "SM4005." The `PL` suffix *is* the SOD-123FL
variant. Bare "SM4005" is a generic industry number whose package varies by
vendor — Rectron/Weitron/CDIL ship SMA, but **Diotec's SM4005 is a MELF
(DO-213AB)**. Don't order by the short number.

### R1's `RATED VOLTAGE` property says 400 VDC — the real figure is 2000 V

§2.7 flagged the Altium metadata fields as low-quality. Here's a concrete case:
the `RATED VOLTAGE` property on R1 reads **400VDC**. Vishay's current datasheet
(doc 68043, rev Oct 2024) gives CRMA2010 a **2000 V** maximum working voltage.

At 20 MΩ / 0.5 W the √(P×R) limit is 3162 V, so the part is bound by the 2000 V
ceiling — roughly **4× margin** over the ~490 V it actually sees. §4b's "keep it"
call stands, with even more headroom than stated.

Manufacturer is **Vishay** (sold as Vishay Dale), not Bourns. Active at Digi-Key.
Decode: `CRMA|2010|A` 3-sided term `|F` Ni-barrier `|20M0` `|F` ±1% `|K` 100 ppm
`|E` Sn100 `|F` full reel.

**Correction to §4b's fallback list:** Bourns **CHV2010A** at 20 MΩ is available
**only at ±5%** — its ±1% range stops at 10 MΩ. The §4b suggestion of two 10 MΩ
CHV2010 in series is unaffected (10 MΩ is inside the ±1% range), but don't expect
a single 20 MΩ 1% Bourns part.

Better 1:1 alternates if you ever need one, both 2000 V at 2010:
**Vishay CRHV** (the non-automotive twin of CRMA — same family) and
**KOA Speer HV73** (2000 VDC, 10 kΩ–100 MΩ, ±0.5/1/2/5%).

⚠️ **Do not sub CRCW-HP or RCA.** Those are *anti-surge / high-power* families,
not high-voltage families. CRCW2010's limiting element voltage is 400 V — which
is almost certainly the source of the wrong number in the schematic property.

### Lead times worth planning around

Lifecycle is clean on these, but the factory lead times are long enough to matter
if you order at the wrong moment:

| Part | Ref | Lead time | Note |
|---|---|---|---|
| MM3Z18VB | D7 | **39 weeks** | ~369 k in stock now |
| US1J-13-F | D2 alt | **32 weeks** | **currently out of stock at Digi-Key** |
| LDA111STR | Q1 | 23 weeks | §4e |
| 3522300KFT | R2 | 17 weeks | §4b suggests a cheaper sub anyway |

The US1J stock-out reinforces §4b's recommendation to use **US1M** for D2
instead — it's a Basic part with 503 k in JLC stock, and 1000 V rather than 600 V.

### Confirmed, no change

- **MURA160T3G** — Active, 600 V / 1 A / trr 75 ns / DO-214AC.
- **3522300KFT** — Active, TE/CGS Type 3522 (formerly Holsworthy), 250 V working
  / 500 V max overload. §4b's figures stand.

### Verification caveats for this pass

onsemi.com, mccsemi.com (HTML) and te.com all return HTTP 403 to automated
fetch, so lifecycle status for MURA160T3G, MM3Z18VB, SM4005PL-TP and 3522300KFT
rests on Digi-Key's Active field rather than manufacturer pages. The MCC and
Vishay *datasheets* were read directly, so the package and electrical corrections
above are first-hand. TE's Type 3522 datasheet was never retrieved — the 250 V /
500 V figures come from element14/Newark parametric data, so give that a browser
check if it becomes load-bearing.

## 4g. Corrections — the SMA sub does not fit your footprint; Pico W is not a drop-in

### ⚠️ The only LCSC-stocked SMA is incompatible with the footprint you chose

§4c said Amphenol 132289, Cinch 142-0701-801 and Molex 73251-1150 are "cross-
referenced as interchangeable." **That is wrong for the Molex** — which is a
problem, because the Molex is the *only* one of the three on LCSC (`C841205`),
and your schematic/PCB uses `Connector_Coaxial:SMA_Amphenol_132289_EdgeMount`.

Measured from the KiCad 10 libraries on this machine:

| | Amphenol 132289 | Molex 73251-1150 |
|---|---|---|
| Ground-pad pitch | **8.50 mm** (Y = ±4.25) | **8.76 mm** (Y = ±4.38) |
| Signal pad | 1.5 × 5.08 mm, on centerline | 5.08 × 2.29 mm at X = −1.72 |
| Drilled holes | **none** — pure SMD land | **2 × Ø0.46 mm locating posts** |

Two hard blockers: the ground pitch is 0.26 mm off, and the Molex needs two
drilled locating holes near the board edge that the Amphenol pattern doesn't
have. **Swapping to the Molex requires a board respin**, not just a BOM edit.

**Amphenol 132289 ↔ Cinch 142-0701-801 remains a valid second-source pair** —
both are the classic .375" square-flange end-launch jack for .062" board, and
TE/Linx's own cross-reference guide lists both as equivalents of Linx
`CONSMA003.062-L`. Neither is on LCSC.

All three accept 1.57 mm / .062" board, so PCB thickness is not the
differentiator — the land pattern is.

**Practical consequence:** you have three options, none of which is "order
`C841205` and move on":
1. Keep the Amphenol/Cinch footprint and **consign** the connector (it's
   hand-soldered either way — see below).
2. Use **JLCPCB's own in-house SMA `C9900107125`** (package TH-5P, wave
   soldering, Economic + Standard tiers) and draw its footprint.
3. Respin the J6 land for the Molex, accepting the two extra drill hits.

*Caveat:* Amphenol's and Molex's own drawing PDFs both 403'd, so these
dimensions come from the KiCad library footprints (which cite those drawings)
plus the Cinch drawing, which was read directly. **Verify against manufacturer
drawings before committing to fab** if you plan to second-source across them.

### JLCPCB cannot machine-place any edge-mount SMA — confirmed as far as it can be

JLC's own SMA (`C9900107125`) is listed as package **TH-5P, assembly method
"Wave Soldering."** `CON-SMA-EDGE-S` (`C5356059`) is Standard-PCBA only. No
official statement says any edge-mount SMA is machine-placed, and all evidence
points to the manual path.

Concrete cost of the through-hole/manual path: **$3.50 hand-soldering fee +
$0.0173 per joint**, and **+1 day** on SMT time. JLC's T&Cs warn that "there will
be some risk since the secondary processing is all carried out manually."

Also relevant if you consign: consigned parts "will not be tested regarding
quality or function before or after PCBA production," and JLC disclaims
responsibility for defects traced to them. And JLC only assembles boards it also
fabricated.

### ⚠️ Pico W / Pico 2 W are footprint-compatible but NOT pin-function compatible

§4c listed Pico 2 W (`C42394205`) among the LCSC options without qualification.
**Do not treat a W board as a drop-in.** On the wireless variants the four
housekeeping GPIOs are reassigned to the CYW43439 radio:

| GPIO | Pico / Pico 2 | Pico W / Pico 2 W |
|---|---|---|
| 23 | SMPS power-save control | **WL_ON** |
| 24 | VBUS sense | **WL_D** |
| 25 | user LED | **WL_CS** |
| 29 | ADC3 / VSYS÷3 | **WL_CLK** (shared) |

The user LED moves to the radio chip (WL_GPIO0), and reading VSYS requires
cooperating with the SPI bus to the radio. Part numbers: Pico W = SC0918,
Pico 2 W = SC1633.

### Pico 2 (SC1631) confirmed a genuine drop-in — my §4c flag resolved

Verified against the official Pico 2 datasheet: same 51 × 21 mm × 1 mm board,
same 40-pin castellated + 2.54 mm THT layout, same 4 × 2.1 mm mounting holes,
same 26 exposed GPIO with 3 ADC — and critically **GPIO23/24/25/29 keep their
Pico 1 functions**, which is the thing that usually breaks these swaps.
Raspberry Pi lists "Hardware and software compatibility with Raspberry Pi Pico 1"
as a Pico 2 feature.

**Longevity commitments, verbatim from the datasheets:**
- Pico 1 series (SC0915, SC0918): **"will remain in production until at least
  January 2036"**
- Pico 2: **"guarantee availability … until at least January 2040"**

SC0915 is Active at Digi-Key (~45.8 k stock, 18-week lead). So there's no
lifecycle pressure to move — but if you do, SC1631 is clean.

Two caveats carried forward: **no JLCPCB part number was found for the plain
Pico 2 (SC1631)** — Pico, Pico H, Pico W and Pico 2 W all have C-numbers, but the
non-W Pico 2 didn't surface. And the **RP2350 GPIO-input errata** remains
unverified — a firmware concern, not a footprint one, but worth checking for a
tool that reads GPIO.

### Red LED obsolescence confirmed, with the manufacturer's own substitute

Digi-Key status on APT1608SRCPRV: **"Obsolete and no longer manufactured,"** and
Digi-Key names **APT1608SURCK** as the substitute. §4c's finding stands.

Useful for matching the replacement: the original is Vf **1.85 V typ / 2.5 V max**
at 20 mA, λdom 640 nm, 150° viewing angle. The `C2286` KT-0603R recommended in
§4c (Vf 1.8–2.4 V) is a good electrical match.

Green APT1608CGCK is **Active** (7-week lead), Vf **2.1 V typ**, λdom 570 nm — so
§4c's Vf-matching argument for `C965805` (2.2 V) is sound.

### Both capacitors are Active — the §4c swaps are for stock, not lifecycle

- **TDK C2012X5R1H475K125AB**: Active, 24-week lead. Not an EOL problem — §4c's
  substitution is purely because LCSC doesn't stock it.
- **KEMET C0603C104K5RACTU**: Active, ~6.7 M in stock, 12-week lead. Lowest-risk
  part on the board.

⚠️ **DC bias on C1/C2 is worth taking seriously.** A 4.7 µF 50 V X5R in an 0805
at ~1.25 mm thickness is near the physical limit for that dielectric volume, and
Class-II ceramics lose capacitance steeply under DC bias. TDK publishes a DC Bias
curve for this exact P/N, but **product.tdk.com 403'd, so no numeric derating was
obtained — do not accept a percentage figure without pulling that curve
yourself** (TDK's MLCC product centre / SEAT tool has it interactively). If you
need real 4.7 µF at working voltage, measure at bias, move to 1206, or
overspecify. This applies equally to the Samsung substitute in §4c.

## 5. Housekeeping

- `chipshouter-pico-mcu.kicad_sch` (1.1 MB) is orphaned — the project references
  only the flat top sheet. It still contains stale duplicates of D1, R11–R13,
  SW1, SW2, U1. Delete it or it will be mistaken for live design data.
- `production/` is a stale 2026-07-23 export of the pre-migration board.
- **The project is not under version control.** `.history/` is VS Code local
  history, not a repo. A migration of this scope without git is the single
  highest-risk thing here.

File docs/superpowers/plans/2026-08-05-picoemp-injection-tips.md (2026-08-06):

# PicoEMP Injection Tips Implementation Plan

> **For agentic workers:** REQUIRED SUB-SKILL: Use superpowers:subagent-driven-development (recommended) or superpowers:executing-plans to implement this plan task-by-task. Steps use checkbox (`- [ ]`) syntax for tracking.

**Goal:** Build five EM injection tips and determine, with evidence, which of them can inject a fault into a live target.

**Architecture:** A spare Pico runs a self-checking loop and prints one line per block; a host-side analyser turns a captured log into a fault count. Tips are five off-the-shelf ferrite inductors on SMA plugs, four of them forming a diameter sweep at constant inductance so a difference in fault rate is attributable to core size alone. A baseline run with the board charged but not pulsing gates everything downstream.

**Tech Stack:** MicroPython on RP2040; `mpremote` over USB CDC; pytest for the analyser and the target's expected-value constant.

## Global Constraints

- **Spec:** `docs/superpowers/specs/2026-08-05-picoemp-injection-tips-design.md`. Section references are to it.
- **The target must be a spare Pico**, not the PicoEMP's own, and not one that matters. Flash corruption is a plausible outcome.
- **Insulate every tip face with Kapton.** With a coil fitted the SMA shell sits at essentially the full rail relative to `HV_RTN` — 261 V of floating metal that must not rest on target pins.
- **Keep the host laptop and both USB cables away from the tip.** The pulse can reset or corrupt the PicoEMP's own Pico.
- All Phase 3 bring-up rules still apply: shield in place, SW3 before contact, hands clear of J1.
- **Python via `uv` only** (`uv run --with pytest pytest`). Never bare `pip`.
- Charge PWM stays at **2500 Hz, `duty_u16(800)`**. Do not retune.

## Deviation from the spec

§3 of the spec says 3–4 tips. **This plan builds five.** A second distributor
search surfaced two more in-stock 10 µH parts at 8.5 mm and 10.0 mm, which
turns two scattered diameter points into a four-point sweep at constant
inductance — a better-sampled experiment for about $1.40 more. Build effort is
held near the spec's number by assembling the four sweep tips first and keeping
the fifth in reserve (Task 5).

## Parts

Inductors — all unshielded, through-hole, radial drum core:

| Role | MPN | Dia | L | I peak | t to peak | $1 | Stock |
|---|---|---|---|---|---|---|---|
| Sweep A | `7447462100` | 6.0 mm | 10 µH | 57 A | 3.4 µs | 0.90 | 672 |
| Sweep B | `744772100` | 7.8 mm | 10 µH | 57 A | 3.4 µs | 0.97 | 3063 |
| Sweep C | `DRC-0707-100K-UL` | 8.5 mm | 10 µH | 57 A | 3.4 µs | 0.70 | 566 |
| Sweep D | `DRC-0807-100K-UL` | 10.0 mm | 10 µH | 57 A | 3.4 µs | 0.70 | 463 |
| Reserve | `7447462022` | 6.0 mm | 2.2 µH | 121 A | 1.6 µs | 0.90 | 197 |

Currents are `V·√(C/L)` and times `(π/2)·√(LC)` with C = 0.47 µF and V = 261 V.

Connectors: **5 × Taoglas `EMPCB.SMAMST.A`**, SMA plug male, board edge, end
launch, $3.26 at qty 10.

Total about $20.

## File Structure

| File | Responsibility |
|---|---|
| `firmware/micropython/glitch_target.py` | Target: self-checking loop, one line per block. No GPIO — pure compute and print. |
| `hardware/rev2026/tools/analyze_glitch_log.py` | Host: turn a captured log into block/fault counts. |
| `hardware/rev2026/tests/test_glitch_target.py` | Host tests for both of the above. |
| `hardware/rev2026/TIP-LOG.md` | Results: baseline, per-tip fault rates, ranking. |

`glitch_target.py` deliberately imports nothing from `machine`, so its
computation is importable and testable on CPython.

---

### Task 1: The target's self-checking loop

**Files:**
- Create: `firmware/micropython/glitch_target.py`
- Create: `hardware/rev2026/tests/test_glitch_target.py`

**Interfaces:**
- Consumes: nothing.
- Produces: `glitch_target.py` exposing `BLOCK_N` (int), `EXPECTED` (int), `compute_block()` returning int, and `format_line(seq, acc)` returning a string. Task 2's analyser parses the exact format `format_line` emits.

- [ ] **Step 1: Write the failing tests**

Create `hardware/rev2026/tests/test_glitch_target.py`:

```python
"""Host-side checks on the glitch target.

The load-bearing test is that EXPECTED actually equals what compute_block()
returns. If that constant were wrong, every block would report a fault, the
baseline control in Task 5 would be nonzero, and the whole experiment would
be measuring a typo. glitch_target.py imports nothing from `machine`
precisely so this can run on CPython.
"""

import importlib.util
import sys

import conftest

REPO = conftest.ROOT.parents[1]
TARGET = REPO / 'firmware' / 'micropython' / 'glitch_target.py'

def _load():
    spec = importlib.util.spec_from_file_location('glitch_target', TARGET)
    mod = importlib.util.module_from_spec(spec)
    sys.modules['glitch_target'] = mod
    spec.loader.exec_module(mod)
    return mod

def test_expected_matches_the_computation():
    """The constant the target compares against is the value it computes."""
    gt = _load()
    assert gt.compute_block() == gt.EXPECTED

def test_block_is_large_enough_to_be_hit():
    """The vulnerable window must be wide enough for an untriggered pulse.

    A block of a few hundred iterations would complete in microseconds and a
    hand-pressed pulse would essentially never land inside it. See spec
    section 4 -- skipping the trigger is only justified by a wide window.
    """
    gt = _load()
    assert gt.BLOCK_N >= 10000, \
        f'BLOCK_N = {gt.BLOCK_N} is too small for untriggered pulsing'

def test_line_format_is_parseable():
    """format_line emits exactly what the analyser expects."""
    gt = _load()
    assert gt.format_line(7, 12345) == 'SEQ 7 ACC 12345'

def test_target_uses_no_gpio():
    """The target must not touch hardware -- it has to run on CPython too."""
    source = TARGET.read_text()
    assert 'import machine' not in source
    assert 'from machine' not in source
```

- [ ] **Step 2: Run tests to verify they fail**

```bash
cd hardware/rev2026 && uv run --with pytest pytest tests/test_glitch_target.py -v
```

Expected: all four FAIL — `glitch_target.py` does not exist, so `_load()` raises `FileNotFoundError`.

- [ ] **Step 3: Write `firmware/micropython/glitch_target.py`**

```python
# PicoEMP glitch target -- a Pico that reports on its own corruption.
#
# Runs a deterministic block of work, checks the result, and prints one line
# per block. A line whose ACC differs from EXPECTED is a data fault. If the
# capture stops, the target reset.
#
# Imports nothing from `machine` on purpose: the computation must be
# importable on CPython so tests/test_glitch_target.py can verify EXPECTED.
#
# Run with:  mpremote connect <port> run glitch_target.py
#
# THIS BOARD WILL BE DELIBERATELY GLITCHED. Use a spare Pico. Flash
# corruption is a plausible outcome.

BLOCK_N = 100000
EXPECTED = BLOCK_N

def compute_block():
    """Count to BLOCK_N the slow way.

    Deliberately the simplest possible loop. A fault that skips, repeats or
    corrupts one iteration shows up directly in the total, with nothing else
    going on to confuse the attribution.
    """
    acc = 0
    for _ in range(BLOCK_N):
        acc += 1
    return acc

def format_line(seq, acc):
    return 'SEQ %d ACC %d' % (seq, acc)

def main():
    print('GLITCH TARGET BLOCK_N %d EXPECTED %d' % (BLOCK_N, EXPECTED))
    seq = 0
    while True:
        print(format_line(seq, compute_block()))
        seq += 1

if __name__ == '__main__':
    main()
```

- [ ] **Step 4: Run tests to verify they pass**

```bash
cd hardware/rev2026 && uv run --with pytest pytest tests/test_glitch_target.py -v
```

Expected: four PASS.

- [ ] **Step 5: Time one block on the actual target**

Connect the **spare** Pico. Flash MicroPython on it if it is bare, exactly as in the bring-up plan Task 4 — `RPI_PICO` build for an RP2040, confirmed via `Board-ID` in `/Volumes/RPI-RP2/INFO_UF2.TXT`.

```bash
uv run --with mpremote mpremote connect <target-port> run firmware/micropython/glitch_target.py
```

Watch the rate of `SEQ` lines. **Aim for roughly one line per second.** If blocks are much faster than that the vulnerable window is narrow and pulses will mostly miss; much slower and each trial takes too long. Adjust `BLOCK_N` and update `EXPECTED` to match, then re-run Step 4 — the test will catch a mismatch.

This step also confirms the `__name__ == '__main__'` guard fires under `mpremote run`. If nothing prints, that is why; call `main()` unconditionally and re-run the tests.

- [ ] **Step 6: Commit**

```bash
git add firmware/micropython/glitch_target.py hardware/rev2026/tests/test_glitch_target.py
git commit -m "Glitch target: self-checking loop with a host-verified expected value"
```

---

### Task 2: The log analyser

**Files:**
- Create: `hardware/rev2026/tools/analyze_glitch_log.py`
- Modify: `hardware/rev2026/tests/test_glitch_target.py`

**Interfaces:**
- Consumes: the `SEQ <n> ACC <v>` format produced by `format_line` in Task 1.
- Produces: `analyze(text, expected)` returning a dict with keys `blocks` (int), `faults` (list of `(seq, acc)` tuples), `fault_rate` (float), `last_seq` (int or None), `malformed` (int).

- [ ] **Step 1: Write the failing tests**

Append to `hardware/rev2026/tests/test_glitch_target.py`:

```python
import importlib.util as _ilu

ANALYZER = conftest.ROOT / 'tools' / 'analyze_glitch_log.py'

def _load_analyzer():
    spec = _ilu.spec_from_file_location('analyze_glitch_log', ANALYZER)
    mod = _ilu.module_from_spec(spec)
    sys.modules['analyze_glitch_log'] = mod
    spec.loader.exec_module(mod)
    return mod

CLEAN_LOG = """GLITCH TARGET BLOCK_N 100000 EXPECTED 100000
SEQ 0 ACC 100000
SEQ 1 ACC 100000
SEQ 2 ACC 100000
"""

FAULTED_LOG = """GLITCH TARGET BLOCK_N 100000 EXPECTED 100000
SEQ 0 ACC 100000
SEQ 1 ACC 99999
SEQ 2 ACC 100000
SEQ 3 ACC 100002
"""

def test_clean_log_reports_no_faults():
    a = _load_analyzer().analyze(CLEAN_LOG, 100000)
    assert a['blocks'] == 3
    assert a['faults'] == []
    assert a['fault_rate'] == 0.0
    assert a['last_seq'] == 2

def test_faulted_log_reports_both_directions():
    """Both a low and a high ACC are faults -- a glitch can skip or repeat."""
    a = _load_analyzer().analyze(FAULTED_LOG, 100000)
    assert a['blocks'] == 4
    assert a['faults'] == [(1, 99999), (3, 100002)]
    assert a['fault_rate'] == 0.5

def test_truncated_final_line_is_counted_not_crashed():
    """A capture cut off mid-line must not look like a fault.

    The target is reset by design during these runs, so the last line of a
    real log is very often a partial one. Counting that as a corrupted
    result would manufacture faults out of the capture ending.
    """
    a = _load_analyzer().analyze(CLEAN_LOG + 'SEQ 3 AC', 100000)
    assert a['blocks'] == 3
    assert a['faults'] == []
    assert a['malformed'] == 1

def test_empty_log_is_not_a_division_by_zero():
    a = _load_analyzer().analyze('', 100000)
    assert a['blocks'] == 0
    assert a['fault_rate'] == 0.0
    assert a['last_seq'] is None
```

- [ ] **Step 2: Run tests to verify they fail**

```bash
cd hardware/rev2026 && uv run --with pytest pytest tests/test_glitch_target.py -v
```

Expected: the four new tests FAIL with `FileNotFoundError`; Task 1's four still PASS.

- [ ] **Step 3: Write `hardware/rev2026/tools/analyze_glitch_log.py`**

```python
#!/usr/bin/env python3
"""Turn a captured glitch-target log into a fault count.

Usage:  uv run tools/analyze_glitch_log.py <logfile> [expected]

A fault is any block whose ACC differs from EXPECTED, in either direction --
a glitch can skip an iteration or repeat one. A truncated final line is
counted as malformed rather than as a fault: the target gets reset on purpose
during these runs, so real logs routinely end mid-line.
"""

import re
import sys

LINE = re.compile(r'^SEQ (\d+) ACC (\d+)$')
HEADER = re.compile(r'^GLITCH TARGET BLOCK_N (\d+) EXPECTED (\d+)$')

def analyze(text, expected):
    blocks = 0
    faults = []
    malformed = 0
    last_seq = None
    for line in text.splitlines():
        line = line.strip()
        if not line or HEADER.match(line):
            continue
        m = LINE.match(line)
        if not m:
            malformed += 1
            continue
        seq, acc = int(m.group(1)), int(m.group(2))
        blocks += 1
        last_seq = seq
        if acc != expected:
            faults.append((seq, acc))
    return {
        'blocks': blocks,
        'faults': faults,
        'fault_rate': (len(faults) / blocks) if blocks else 0.0,
        'last_seq': last_seq,
        'malformed': malformed,
    }

def main(argv):
    if not 2 <= len(argv) <= 3:
        print(__doc__.strip())
        return 2
    text = open(argv[1]).read()
    if len(argv) == 3:
        expected = int(argv[2])
    else:
        m = HEADER.search(text)
        if not m:
            print('No header line in log; pass expected explicitly.')
            return 2
        expected = int(m.group(2))
    a = analyze(text, expected)
    print('blocks     %d' % a['blocks'])
    print('faults     %d' % len(a['faults']))
    print('fault rate %.4f' % a['fault_rate'])
    print('last seq   %s' % a['last_seq'])
    print('malformed  %d' % a['malformed'])
    for seq, acc in a['faults']:
        print('  SEQ %d ACC %d (delta %+d)' % (seq, acc, acc - expected))
    return 0

if __name__ == '__main__':
    sys.exit(main(sys.argv))
```

- [ ] **Step 4: Run tests to verify they pass**

```bash
cd hardware/rev2026 && uv run --with pytest pytest tests/test_glitch_target.py -v
```

Expected: eight PASS.

- [ ] **Step 5: Run the full suite**

```bash
cd hardware/rev2026 && uv run --with pytest pytest tests/
```

Expected: 77 pre-existing plus 8 new = 85 passing.

- [ ] **Step 6: Commit**
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

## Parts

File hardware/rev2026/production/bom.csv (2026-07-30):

Designator | Footprint | Quantity | Value | LCSC Part #
C1, C2 | 0805 | 2 | 4.7uF/50V | C2012X5R1H475K125AB
C3 | 2220 | 1 | 0.47uF,630V,X7T | GR355DD7LQ474KW01K
C5, C6 | 0603 | 2 | 100n | C0603C104K5RACTU
D1, D3, D4, D5 | D_SOD-123FL | 4 | SM4005PL-TP | SM4005PL-TP
D2 | D_SMA | 1 | MURA160T3G | MURA160T3G
D6, D9 | 0603 | 2 | LED, 0603, Red | APT1608SURCK
D7 | D_SOD-323F | 1 | MM3Z18VB | MM3Z18VB
D8 | 0603 | 1 | LED, 0603, Green | APT1608CGCK
J1, J4 | SMA_Linx_CONSMA020_062_G_EdgeMount | 2 | EDGE-SMA | CONSMA020.062-G
J2 | JST_XH_S2B-XH-A_1x02_P2.50mm_Horizontal | 1 | 1x2_Pin_Header | S2B-XH-A(LF)(SN)
J3 | TerminalBlock_Phoenix_MKDSN-1,5-2-5.08_1x02_P5.08mm_Horizontal | 1 | MKDSN 1,5/2-5,08 | 1548128
P1 | PinHeader_1x07_P2.54mm_Vertical | 1 | Header 7
P2 | PinHeader_1x02_P2.54mm_Vertical | 1 | Header 2
P3 | PinHeader_1x04_P2.54mm_Vertical | 1 | Header 4
Q1 | SOP-6_LDA111 | 1 | LDA111STR | LDA111STR
Q2 | TO-252-3_TabPin2 | 1 | RGT16BM65DTL | RGT16BM65DTL
Q3, Q4 | SOT-23 | 2 | AO3422 | AO3422
R1 | 2010 | 1 | 20M | CRMA2010AF20M0FKEF
R10, R11, R12, R13, R5 | 0603 | 5 | 1k | RC0603FR-071KL
R14 | 0603 | 1 | 100R | RC0603FR-07100RL
R15 | 0603 | 1 | 10k | RC0603FR-0710KL
R2 | 2512 | 1 | 300K | 3522300KFT
R3, R7 | 0603 | 2 | 10R | RC0603FR-0710RL
R4 | 0805 | 1 | 75R | RC0805FR-0775RL
R6 | 0603 | 1 | 22k | RC0603FR-0722KL
R9 | 0805 | 1 | 2k | RC0805FR-072KL
SW1, SW2 | SW_Push_1P1T_NO_CK_KSC7xxJ | 2 | KSC741J LFS | KSC741JLFS
SW3 | SW_Push_ESwitch_TL3301AJ | 1 | TL3301AF160QJ | TL3301AF160QJ
T1, T2 | ATB322524 | 2 | ATB322524 | ATB322524-0110-T000
U1 | RaspberryPi_Pico_SMD | 1 | SC0915 | SC0915
U2 | SOT-23-5 | 1 | 74LVC1G17 | 74LVC1G17GV,125

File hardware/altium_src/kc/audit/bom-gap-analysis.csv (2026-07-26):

Ref | Sch Value | ALTIUM_VALUE | Upstream Desc | Upstream MPN | Upstream Mfr | Sch MPN | Internal PN | Footprint | FP Status | Symbol lib_id | Sym Status | Issues
C1 | 4.7uF/50V |  | 4.7uF 50V 0805 | C2012X5R1H475K125AB | TDK |  |  | Capacitor_SMD:C_0805_2012Metric_Pad1.18x1.45mm_HandSolder | OK | Device:C_Small | OK
C2 | 4.7uF/50V |  | 4.7uF 50V 0805 | C2012X5R1H475K125AB | TDK |  |  | Capacitor_SMD:C_0805_2012Metric_Pad1.18x1.45mm_HandSolder | OK | Device:C_Small | OK
C3 | 0.47uF,630V,X7T |  | 0.47uF 630V X7T 2220 | KRM55TR72J474MH01K | Murata |  |  | CKG57N_2220 | UNRESOLVABLE | Device:C_Small | OK | footprint unresolvable ((no lib prefix))
C5 | ${ALTIUM_VALUE} |  | 100nF 0603 | C0603C104K5RACTU | KEMET |  |  | Capacitor_SMD:C_0603_1608Metric_Pad1.08x0.95mm_HandSolder | OK | Device:C_Small | OK | VALUE RENDERS LITERALLY
D1 | SM4005PL-TP |  | 600V 1A rectifier | SM4005PL-TP | MCC |  |  |  | MISSING | Device:D_Schottky_Small | OK | footprint missing ((none))
D2 | MURA160T3G |  | 600V 1A fast recovery | MURA160T3G | onsemi |  |  | SMA | UNRESOLVABLE | Device:D_Small | OK | footprint unresolvable ((no lib prefix))
D3 | SM4005PL-TP |  | 600V 1A rectifier | SM4005PL-TP | MCC |  |  | DSS13UTR | UNRESOLVABLE | Device:D_Schottky_Small | OK | footprint unresolvable ((no lib prefix))
D4 | SM4005PL-TP |  | 600V 1A rectifier | SM4005PL-TP | MCC |  |  | DSS13UTR | UNRESOLVABLE | Device:D_Schottky_Small | OK | footprint unresolvable ((no lib prefix))
D5 | SM4005PL-TP |  | 600V 1A rectifier | SM4005PL-TP | MCC |  |  | DSS13UTR | UNRESOLVABLE | Device:D_Schottky_Small | OK | footprint unresolvable ((no lib prefix))
D7 | MM3Z18VB |  | 18V zener SOD-323 | MM3Z18VB | onsemi |  |  | SOD323 | UNRESOLVABLE | Device:D_Zener_Small | OK | footprint unresolvable ((no lib prefix))
J1 | Header 7 |  | 1x7 hdr 2.54mm | - | - |  |  | Connector_PinHeader_1.00mm:PinHeader_1x07_P1.00mm_Vertical | OK | Connector:Conn_01x07_Pin | OK | DNP; excluded from BOM
J2 | 1x2_Pin_Header |  | JST XH 2-pin THT | S2B-XH-A(LF)(SN) | JST | 22-23-2021n22-23-2021 | Molex_2_Pin | Connector_PinHeader_1.27mm:PinHeader_1x02_P1.27mm_Vertical | OK | Connector:Conn_01x02_Pin | OK | MPN MISMATCH vs upstream (22-23-2021n22-23-2021 vs S2B-XH-A(LF)(SN)); DNP; excluded from BOM
J3 | BG306-02-A-2-0400-L-G |  | 2-pin SMD hdr (HV cal) | BG306-02-A-2-0400-L-G | GCT |  |  |  | MISSING | Connector:Conn_01x02_Pin | OK | footprint missing ((none)); DNP; excluded from BOM
J4 | Header 2 |  | 1x2 hdr 2.54mm | - | - |  |  | Connector_PinHeader_1.27mm:PinHeader_1x02_P1.27mm_Vertical | OK | Connector:Conn_01x02_Pin | OK | DNP; excluded from BOM
J5 | Header 4 |  | 1x4 hdr 2.54mm | - | - |  |  | Connector_PinHeader_1.00mm:PinHeader_1x04_P1.00mm_Vertical | OK | Connector:Conn_01x04_Pin | OK | DNP; excluded from BOM
J6 | EDGE-SMA |  | Edge-mount SMA | 0732511150 / 142-0701-801 | Molex / Cinch |  |  | Connector_Coaxial:SMA_Amphenol_132289_EdgeMount | OK | Connector:Conn_Coaxial_Power | OK
LED1 | LED, 0603, Red |  | Red 0603 LED | APT1608SRCPRV | Kingbright |  |  | LED_SMD:LED_0603_1608Metric_Pad1.05x0.95mm_HandSolder | OK | Device:LED | OK
LED2 | LED, 0603, Green |  | Green 0603 LED | APT1608CGCK | Kingbright |  |  | LED_SMD:LED_0603_1608Metric_Pad1.05x0.95mm_HandSolder | OK | Device:LED | OK
LED3 | LED, 0603, Red |  | Red 0603 LED | APT1608SRCPRV | Kingbright |  |  | LED_SMD:LED_0603_1608Metric_Pad1.05x0.95mm_HandSolder | OK | Device:LED | OK
Q1 | LDA111STR |  | Low-current opto | LDA111STR | IXYS | LDA111STR |  | C__Users_colin_Documents_AltiumLL_SamacSys.PcbLib:SOP254P952X470-6N | UNRESOLVABLE | *:root_0_mirrored_LDA111STR_* | UNRESOLVABLE | footprint unresolvable (C__Users_colin_Documents_AltiumLL_SamacSys.PcbLib); symbol lib unresolvable (*:root_0_mirrored_LDA111STR_*)
Q2 | RGT16BM65DTL |  | IGBT 650V DPAK | RGT16BM65DTL | Rohm |  |  |  | MISSING | Device:Q_NMOS_Depletion | OK | footprint missing ((none))
Q3 | AO3422 |  | NMOS 30V SOT-23 | AO3422 | AOS |  |  |  | MISSING | Device:Q_NMOS_Depletion | OK | footprint missing ((none))
Q4 | AO3422 |  | NMOS 30V SOT-23 | AO3422 | AOS |  |  |  | MISSING | Device:Q_NMOS_Depletion | OK | footprint missing ((none))
R1 | ${ALTIUM_VALUE} | 20M | 20M 2010 1% | CRMA2010AF20M0FKEF | Vishay | CRMA2010AF20M0FKEF | RCHIP-20M-2010 | Resistor_SMD:R_2010_5025Metric_Pad1.40x2.65mm_HandSolder | OK | Device:R_Small | OK | value is a variable ref, not flattened
R2 | ${ALTIUM_VALUE} | 300K | 300K 2512 3W | 3522300KFT | TE/CGS | 3522300KFT | RCHIP-300K-2512 | Resistor_SMD:R_2512_6332Metric_Pad1.40x3.35mm_HandSolder | OK | Device:R_Small | OK | value is a variable ref, not flattened
R3 | ${ALTIUM_VALUE} | 10R | 10R 0603 | RC0603FR-0710RL | Yageo | RC0603FR-0710RL | RCHIP-10R-0603 | Resistor_SMD:R_0603_1608Metric_Pad0.98x0.95mm_HandSolder | OK | Device:R_Small | OK | value is a variable ref, not flattened
R4 | 75R | 75R | 75R 0805 | RC0805FR-0775RL | Yageo | RC0805FR-0775RL | RCHIP-75R-0805 | Resistor_SMD:R_0805_2012Metric_Pad1.20x1.40mm_HandSolder | OK | Device:R_Small | OK
R5 | ${ALTIUM_VALUE} | 1k | 1k 0603 | RC0603FR-071KL | Yageo | RC0603FR-071KL | RCHIP-1K-0603 | Resistor_SMD:R_0603_1608Metric_Pad0.98x0.95mm_HandSolder | OK | Device:R_Small | OK | value is a variable ref, not flattened
R6 | ${ALTIUM_VALUE} | 22k | 22k 0603 | RC0603FR-0722KL | Yageo | RC0603FR-0722KL | RCHIP-22K-0603 | Resistor_SMD:R_0603_1608Metric_Pad0.98x0.95mm_HandSolder | OK | Device:R_Small | OK | value is a variable ref, not flattened
R7 | ${ALTIUM_VALUE} | 10R | 10R 0603 | RC0603FR-0710RL | Yageo | RC0603FR-0710RL | RCHIP-10R-0603 | Resistor_SMD:R_0603_1608Metric_Pad0.98x0.95mm_HandSolder | OK | Device:R_Small | OK | value is a variable ref, not flattened
R9 | 2k | 75R | 2k 0805 | RC0805FR-072KL | Yageo | RC0805FR-0775RL | RCHIP-75R-0805 | Resistor_SMD:R_0805_2012Metric_Pad1.20x1.40mm_HandSolder | OK | Device:R_Small | OK | MPN MISMATCH vs upstream (RC0805FR-0775RL vs RC0805FR-072KL)
R10 | ${ALTIUM_VALUE} | 1k | 1k 0603 | RC0603FR-071KL | Yageo | RC0603FR-071KL | RCHIP-1K-0603 | Resistor_SMD:R_0603_1608Metric_Pad0.98x0.95mm_HandSolder | OK | Device:R_Small | OK | value is a variable ref, not flattened
R11 | ${ALTIUM_VALUE} | 1k | 1k 0603 | RC0603FR-071KL | Yageo | RC0603FR-071KL | RCHIP-1K-0603 | Resistor_SMD:R_0603_1608Metric_Pad0.98x0.95mm_HandSolder | OK | Device:R_Small | OK | value is a variable ref, not flattened
R12 | ${ALTIUM_VALUE} | 1k | 1k 0603 | RC0603FR-071KL | Yageo | RC0603FR-071KL | RCHIP-1K-0603 | Resistor_SMD:R_0603_1608Metric_Pad0.98x0.95mm_HandSolder | OK | Device:R_Small | OK | value is a variable ref, not flattened
R13 | ${ALTIUM_VALUE} | 1k | 1k 0603 | RC0603FR-071KL | Yageo | RC0603FR-071KL | RCHIP-1K-0603 | Resistor_SMD:R_0603_1608Metric_Pad0.98x0.95mm_HandSolder | OK | Device:R_Small | OK | value is a variable ref, not flattened
SW1 | KSC741J LFS |  | Tactile SPST | KSC741JLFS | ITT C&K |  |  |  | MISSING | Switch:SW_Push | OK | footprint missing ((none))
SW2 | KSC741J LFS |  | Tactile SPST | KSC741JLFS | ITT C&K |  |  |  | MISSING | Switch:SW_Push | OK | footprint missing ((none))
SW3 | TL3301AF160QJ |  | Tactile SPST (discharge) | TL3301AF160QJ | E-Switch |  |  |  | MISSING | Switch:SW_Push | OK | footprint missing ((none))
T1 | ATB322524 |  | 1:10 HV pulse xfmr | ATB322524-0110-T000 | TDK | ATB322524 | ATB322524_PROTO | ATB322524 | UNRESOLVABLE | NewAE_AltiumLib:root_0_xformer_2_2_hv_NewAE_AltiumLib.DBLib | UNRESOLVABLE | footprint unresolvable ((no lib prefix)); symbol lib unresolvable (NewAE_AltiumLib:root_0_xformer_2_2_hv_NewAE_AltiumLib.DBLib)
T2 | ATB322524 |  | 1:10 HV pulse xfmr | ATB322524-0110-T000 | TDK | ATB322524 | ATB322524_PROTO | ATB322524 | UNRESOLVABLE | NewAE_AltiumLib:root_0_xformer_2_2_hv_NewAE_AltiumLib.DBLib | UNRESOLVABLE | footprint unresolvable ((no lib prefix)); symbol lib unresolvable (NewAE_AltiumLib:root_0_xformer_2_2_hv_NewAE_AltiumLib.DBLib)
U1 | SC0915 | * | RPi Pico module | SC0915 | Raspberry Pi |  | SC0915 | Module:RaspberryPi_Pico_SMD | OK | MCU_Module:RaspberryPi_Pico_Extensive | OK

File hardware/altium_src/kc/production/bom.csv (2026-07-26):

Designator | Footprint | Quantity | Value | LCSC Part #
C1, C2 | CAPC0805_M | 2 | 4.7uF/50V
C3 | CKG57N_2220 | 1 | 0.47uF,630V,X7T
C5 | CAPC0603_M | 1 | 100n
D1, D3, D4, D5 | DSS13UTR | 4 | DSS13UTR
D2 | DO-214AC | 1 | MURA160T3G
D6, D9 | LED-0603-RED | 2 | LED, 0603, Red
D7 | SOD323 | 1 | MM3Z18VB
D8 | LED-0603-GREEN | 1 | LED, 0603, Green
J1 | CON-SMA-MALE-PCB-EDGE062 | 1 | EDGE-SMA
J2 | 22-23-2021 | 1 | 1x2_Pin_Header
J3 | BG306-R2-2PIN | 1 | BG306-02-A-2-0400-L-G
MH1, MH2, MH3 | MOUNT_M3_TIGHT | 3 | M3, Tight Fit
P1 | HDR1X7 | 1 | Header 7
P2 | HDR1X2 | 1 | Header 2
P3 | HDR1X4 | 1 | Header 4
Q1 | SOP254P952X470-6N | 1 | LDA111STR
Q2 | DPAK_TO-252AA_M | 1 | RGT16BM65DTL
Q3, Q4 | SOT95P245X110-3M | 2 | AO3422
R1 | RESC5025X06N | 1 | 20M
R10, R11, R12, R13, R5 | RESC1608X55N | 5 | 1k
R2 | RESC6432X06N | 1 | 300K
R3, R7 | RESC1608X55N | 2 | 10R
R4 | RESC2012X70N | 1 | 75R
R6 | RESC1608X55N | 1 | 22k
R9 | RESC2012X70N | 1 | 2k
SW1, SW2, SW3 | CK_KSC7J | 3 | KSC741J LFS
T1, T2 | ATB322524 | 2 | ATB322524
U1 | MODULE_SC0915_TH | 1 | SC0915

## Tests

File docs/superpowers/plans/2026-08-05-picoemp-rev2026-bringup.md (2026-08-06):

# PicoEMP Rev-2026 Bring-Up Implementation Plan

> **For agentic workers:** REQUIRED SUB-SKILL: Use superpowers:subagent-driven-development (recommended) or superpowers:executing-plans to implement this plan task-by-task. Steps use checkbox (`- [ ]`) syntax for tracking.

**Goal:** Take the first hand-assembled Rev-2026 board from "just soldered" to a verified charge-and-discharge cycle, with every step gated on a cheaper test passing first.

**Architecture:** Two throwaway-safe MicroPython scripts plus a measurement log. `bringup.py` exercises LEDs, buttons and the CHARGED input and is *structurally incapable* of making high voltage — it never references GP20 or GP14, and a host-side AST test enforces that permanently. `chargetest.py` is the only file that touches GP20, and does so under a hard timeout in a `try/finally`. Bench phases are recorded in a log file so a failure is diagnosable later.

**Tech Stack:** MicroPython on RP2040/RP2350; `mpremote` over USB CDC (driven from Bash, no Thonny needed); pytest for host-side static checks; `kicad-cli` netlist export as the pin-map source of truth.

## Global Constraints

- **Spec:** `docs/superpowers/specs/2026-08-05-picoemp-rev2026-bringup-design.md`. All section references below are to it.
- **Pulsing is out of scope.** No task may configure GP14 (`HVPULSE`). No injection tip exists.
- **Phase order is a safety gate.** A failing phase stops the sequence; do not proceed to the next task.
- **Discharge before contact.** Hold `SW3` one second before touching the board any time it has been armed.
- **Never touch J1.** Its centre pin carries `HV_RAIL` continuously while charged, not only during a pulse.
- **Python via `uv` only** (`uv run --with pytest pytest`), per `hardware/rev2026/CLAUDE.md`. Never bare `pip`.
- Charge PWM parameters are fixed at **2500 Hz, `duty_u16(800)`** — the empirically tuned values from `firmware/micropython/cspico_simple.py`. Do not retune.
- Rail voltage is **never measured** (§7). `CHARGED` asserting proves the sense chain conducts, not that the rail is 250 V.

## File Structure

| File | Responsibility |
|---|---|
| `hardware/rev2026/BRINGUP-LOG.md` | Measured values and pass/fail per phase. Created Task 1, appended thereafter. |
| `firmware/micropython/bringup.py` | Phase 2 I/O self-test. Provably cannot charge. Never edited to add charging. |
| `firmware/micropython/chargetest.py` | Phase 3 commanded, timeout-bounded charge/discharge. The only file touching GP20. |
| `hardware/rev2026/tests/test_bringup_firmware.py` | Host-side: pin map matches netlist; safety invariants hold. |

Splitting the two scripts is deliberate. Keeping `bringup.py` permanently charge-free makes "Phase 2 cannot make high voltage" a checkable invariant rather than a claim about a code path.

---

### Task 1: Phase 0 — cold checks and the log

No power, no code. Deliverable is a completed measurement table.

**Files:**
- Create: `hardware/rev2026/BRINGUP-LOG.md`

**Interfaces:**
- Consumes: nothing.
- Produces: `BRINGUP-LOG.md` with a `## Phase 0` section. Later tasks append `## Phase N` sections in the same table format.

- [ ] **Step 1: Confirm the board has never been energized**

If it has been powered since assembly, hold `SW3` for one second before proceeding. C3 self-bleeds at τ ≈ 9.5 s but stalls at the opto LED knee, so time alone is not sufficient.

- [ ] **Step 2: Take the six readings**

DMM on resistance. Probe points per §4:

| # | Measurement | Expect | Failure means |
|---|---|---|---|
| 0.1 | J1 centre pin → J3.2 | 300 kΩ ±5 % | `R2` missing/bad — no fast discharge path |
| 0.2 | **Hold SW3**, J1 centre pin → J3.1 | 300 kΩ ±5 % | `SW3` not closing — no manual discharge |
| 0.3 | P3.3 (GND) → J3.1 | open, > 20 MΩ | Isolation barrier breached |
| 0.4 | J1 centre pin → J1 shell | not a short | IGBT `Q2` shorted collector-to-emitter |
| 0.5 | P3.2 (+3V3) → P3.3 (GND) | not a short | 3V3 rail fault |
| 0.6 | J2.1 → J2.2 | not a short | Input rail fault |

Expected-but-not-a-fault: `J3.2 → J3.1` with SW3 **released** reads open, not 20 MΩ. The DMM's ohms source is under 1 V and will not forward-bias the opto LED in series with R1.

- [ ] **Step 3: Write the log**

Create `hardware/rev2026/BRINGUP-LOG.md`:

```markdown
# Rev-2026 Bring-Up Log — Board #1

Plan: `docs/superpowers/plans/2026-08-05-picoemp-rev2026-bringup.md`
Spec: `docs/superpowers/specs/2026-08-05-picoemp-rev2026-bringup-design.md`

Equipment: DMM; bench PSU with current limit. No scope, no HV probe.

---

## Phase 0 — cold checks

Date: YYYY-MM-DD

| # | Measurement | Expected | Measured | Pass |
|---|---|---|---|---|
| 0.1 | J1 centre → J3.2 | 300 kΩ ±5 % | | |
| 0.2 | Hold SW3, J1 centre → J3.1 | 300 kΩ ±5 % | | |
| 0.3 | GND → J3.1 | open > 20 MΩ | | |
| 0.4 | J1 centre → J1 shell | not a short | | |
| 0.5 | +3V3 → GND | not a short | | |
| 0.6 | J2.1 → J2.2 | not a short | | |

Notes:
```

Fill in the Measured and Pass columns with the actual readings. Replace `YYYY-MM-DD` with the real date.

- [ ] **Step 4: Gate**

If any row fails, stop. Do not start Task 2. Record what failed in Notes.

- [ ] **Step 5: Commit**

```bash
git add hardware/rev2026/BRINGUP-LOG.md
git commit -m "Phase 0 cold checks on board #1"
```

---

### Task 2: Phase 1 — first power, current-limited

**Files:**
- Modify: `hardware/rev2026/BRINGUP-LOG.md`

**Interfaces:**
- Consumes: Task 1's gate (Phase 0 all-pass).
- Produces: a powered board known free of assembly shorts.

- [ ] **Step 1: Set up the supply**

Bench PSU to **5.0 V, current limit 100 mA**, output OFF. USB unplugged. The Pico is unprogrammed at this point — that is intentional. GPIOs default high-Z and `R5`/`R10` hold Q3's and Q4's gates at GND, so HV-off is the passive state and no firmware bug can change it.

Connect to `J2` (S2B-XH-A, JST XH 2.50 mm): **pin 1 = `VEXT_IN`, pin 2 = `GND`**. Verify polarity with the DMM against P3.3 before enabling the output.

- [ ] **Step 2: Enable output and read**

| Reading | Expect |
|---|---|
| PSU current | well under 100 mA, not in limit |
| P3.2 → P3.3 | 3.3 V ±5 % |

If the PSU goes into current limit, switch off immediately and stop. That is the assembly-short screen doing its job.

- [ ] **Step 3: Append to the log**

```markdown
## Phase 1 — first power, current-limited

Date: YYYY-MM-DD
PSU: 5.0 V, limit 100 mA, into J2. USB unplugged. Pico unprogrammed.

| Reading | Expected | Measured | Pass |
|---|---|---|---|
| PSU current | < 100 mA, no limit | | |
| +3V3 (P3.2 → P3.3) | 3.3 V ±5 % | | |

Notes:
```

- [ ] **Step 4: Power down**

PSU output off, disconnect J2. Remaining phases run on USB.

- [ ] **Step 5: Commit**

```bash
git add hardware/rev2026/BRINGUP-LOG.md
git commit -m "Phase 1 first power on board #1"
```

---

### Task 3: `bringup.py` and its safety invariant

Host-side work. No hardware needed; can be done while the board sits unpowered.

**Files:**
- Create: `firmware/micropython/bringup.py`
- Create: `hardware/rev2026/tests/test_bringup_firmware.py`

**Interfaces:**
- Consumes: `tests/test_netlist.py::_nets` (existing helper mapping a kicad-cli netlist to `{net_name: {"REF.PIN", ...}}`), `tests/conftest.py::SCH`.
- Produces: `firmware/micropython/bringup.py` exposing module-level int constants `PIN_STATUS_LED = 7`, `PIN_HV_DET_LED = 6`, `PIN_CHARGE_LED = 27`, `PIN_ARM_SW = 28`, `PIN_PULSE_SW = 11`, `PIN_CHARGED = 18`, and a `main()` taking no arguments. Task 6's test imports `GPIO_TO_PAD` from `tests/test_bringup_firmware.py`.

- [ ] **Step 1: Write the failing tests**

Create `hardware/rev2026/tests/test_bringup_firmware.py`:

```python
"""Host-side checks on the bring-up firmware.

Two things are enforced here. First, the scripts' pin numbers must match
the board -- a transposed digit would light the wrong LED at best and
drive HVPWM at worst. Second, bringup.py must remain structurally unable
to make high voltage: Phase 2 of the spec claims "there is no command, no
code path, and no button that can make high voltage", and that claim is
only worth anything if something checks it.
"""

import ast
import subprocess

import pytest

import conftest
from test_netlist import KC, _nets

REPO = conftest.ROOT.parents[1]
BRINGUP = REPO / 'firmware' / 'micropython' / 'bringup.py'
CHARGETEST = REPO / 'firmware' / 'micropython' / 'chargetest.py'

# Raspberry Pi Pico GPIO number -> physical pad number on the module.
# The Pico is not regularly numbered (GND pads interrupt the sequence at
# 3, 8, 13, 18, 23, 28, 33, 38), so this is an explicit table rather than
# arithmetic.
GPIO_TO_PAD = {
    0: 1, 1: 2, 2: 4, 3: 5, 4: 6, 5: 7, 6: 9, 7: 10, 8: 11, 9: 12,
    10: 14, 11: 15, 12: 16, 13: 17, 14: 19, 15: 20, 16: 21, 17: 22,
    18: 24, 19: 25, 20: 26, 21: 27, 22: 29, 26: 31, 27: 32, 28: 34,
}

# bringup.py constant name -> net-name fragment its GPIO must land on.
BRINGUP_PINS = {
    'PIN_STATUS_LED': 'STATUS_LED',
    'PIN_HV_DET_LED': 'HV_DET_LED',
    'PIN_CHARGE_LED': 'CHARGE_LED',
    'PIN_ARM_SW': 'ARM_SW',
    'PIN_PULSE_SW': 'PULSE_SW',
    'PIN_CHARGED': 'CHARGED',
}

# GPIOs that must never appear in bringup.py, and why.
FORBIDDEN_IN_BRINGUP = {20: 'HVPWM -- would enable charging', 14: 'HVPULSE -- pulsing is out of scope'}

def _constants(path):
    """Module-level `NAME = <int>` assignments, as a dict."""
    tree = ast.parse(path.read_text())
    out = {}
    for node in tree.body:
        if isinstance(node, ast.Assign) and isinstance(node.value, ast.Constant) \
                and isinstance(node.value.value, int):
            for target in node.targets:
                if isinstance(target, ast.Name):
                    out[target.id] = node.value.value
    return out

def _int_literals(path):
    """Every integer literal anywhere in the module."""
    return {n.value for n in ast.walk(ast.parse(path.read_text()))
            if isinstance(n, ast.Constant) and isinstance(n.value, int)}

@pytest.fixture(scope='module')
def node_to_net(tmp_path_factory):
    out = tmp_path_factory.mktemp('net') / 'net.net'
    subprocess.run([KC, 'sch', 'export', 'netlist', '--format', 'kicadsexpr',
                    '-o', str(out), str(conftest.SCH)], check=True,
                   capture_output=True)
    nets = _nets(out.read_text())
    return {n: name for name, nodes in nets.items() for n in nodes}

def test_bringup_pin_map_matches_netlist(node_to_net):
    """Every pin constant lands on the net its name claims."""
    consts = _constants(BRINGUP)
    for name, fragment in BRINGUP_PINS.items():
        assert name in consts, f'{name} not defined in bringup.py'
        gpio = consts[name]
        assert gpio in GPIO_TO_PAD, f'{name} = GP{gpio} is not a Pico GPIO'
        node = f'U1.{GPIO_TO_PAD[gpio]}'
        assert node in node_to_net, f'{name} = GP{gpio} ({node}) is not connected'
        assert fragment in node_to_net[node], \
            f'{name} = GP{gpio} sits on net {node_to_net[node]!r}, expected {fragment!r}'

def test_bringup_cannot_drive_hv():
    """bringup.py must not mention GP20 or GP14 at all.

    This is deliberately blunt. Checking "GP20 is only used behind a guard"
    would require reasoning about reachability; checking that the number
    never appears is decidable, and costs nothing because bringup.py has
    no legitimate reason to reference either pin.
    """
    literals = _int_literals(BRINGUP)
    for gpio, why in FORBIDDEN_IN_BRINGUP.items():
        assert gpio not in literals, \
            f'bringup.py contains the literal {gpio} -- {why}'

def test_bringup_never_imports_pwm():
    """No PWM import means no way to drive the transformer, whatever the pin."""
    source = BRINGUP.read_text()
    assert 'PWM' not in source, 'bringup.py references PWM'
```

- [ ] **Step 2: Run the tests to verify they fail**

```bash
cd hardware/rev2026 && uv run --with pytest pytest tests/test_bringup_firmware.py -v
```

Expected: all three FAIL — `bringup.py` does not exist yet, so `_constants` raises `FileNotFoundError`.

- [ ] **Step 3: Write `firmware/micropython/bringup.py`**

```python
# PicoEMP bring-up self-test -- Phase 2
#
# Exercises every LED, both buttons and the CHARGED input, and prints a
# structured result. It CANNOT make high voltage: GP20 (HVPWM) and GP14
# (HVPULSE) are never referenced, so both stay high-Z and R5/R10 hold the
# Q3/Q4 gates at GND. `tests/test_bringup_firmware.py` enforces that.
#
# Run with:  mpremote connect <port> run bringup.py
# Do not save this as main.py -- it is a test, not the firmware.

from machine import Pin
import utime

PIN_STATUS_LED = 7
PIN_HV_DET_LED = 6
PIN_CHARGE_LED = 27
PIN_ARM_SW = 28
PIN_PULSE_SW = 11
PIN_CHARGED = 18

LEDS = (
    ('STATUS', PIN_STATUS_LED),
    ('HV_DET', PIN_HV_DET_LED),
    ('CHARGE', PIN_CHARGE_LED),
)

BUTTON_TIMEOUT_MS = 15000

def led_walk():
    """Light each LED alone for a second, then all three together."""
    pins = [(name, Pin(gpio, Pin.OUT)) for name, gpio in LEDS]
    for _, pin in pins:
        pin.off()
    for name, pin in pins:
        print('LED %s: ON -- confirm it lit' % name)
        pin.on()
        utime.sleep_ms(1000)
        pin.off()
    print('LED ALL: ON')
    for _, pin in pins:
        pin.on()
    utime.sleep_ms(2000)
    for _, pin in pins:
        pin.off()
    print('LED ALL: OFF')

def wait_for_press(name, pin, pressed_level):
    """Block until `pin` reads `pressed_level`, or the timeout expires."""
    print('BUTTON %s: press it now (%d s)' % (name, BUTTON_TIMEOUT_MS // 1000))
    deadline = utime.ticks_add(utime.ticks_ms(), BUTTON_TIMEOUT_MS)
    while utime.ticks_diff(deadline, utime.ticks_ms()) > 0:
        if pin.value() == pressed_level:
            print('BUTTON %s: PASS' % name)
            return True
        utime.sleep_ms(10)
    print('BUTTON %s: FAIL -- no press seen' % name)
    return False

def main():
    print('=== PicoEMP bring-up self-test (Phase 2) ===')
    print('HVPWM and HVPULSE are not driven by this script.')

    led_walk()

    # SW1 pulls ARM_SW up to +3V3, so pressed reads high against a pulldown.
    arm = Pin(PIN_ARM_SW, Pin.IN, Pin.PULL_DOWN)
    # SW2 pulls PULSE_SW down to GND, so pressed reads low against a pullup.
    pulse = Pin(PIN_PULSE_SW, Pin.IN, Pin.PULL_UP)
    # R6 already pulls CHARGED up to +3V3; the opto pulls it low when the
    # rail is charged. No internal pull.
    charged = Pin(PIN_CHARGED, Pin.IN)

    print('CHARGED idle level: %d (1 = not charged, expected at rest)'
          % charged.value())

    ok_arm = wait_for_press('ARM', arm, 1)
    ok_pulse = wait_for_press('PULSE', pulse, 0)

    print('=== RESULT: %s ===' % ('PASS' if (ok_arm and ok_pulse) else 'FAIL'))

main()
```

- [ ] **Step 4: Run the tests to verify they pass**

```bash
cd hardware/rev2026 && uv run --with pytest pytest tests/test_bringup_firmware.py -v
```

Expected: `test_bringup_pin_map_matches_netlist`, `test_bringup_cannot_drive_hv` and `test_bringup_never_imports_pwm` all PASS.

- [ ] **Step 5: Run the full suite for regressions**

```bash
cd hardware/rev2026 && uv run --with pytest pytest tests/
```

Expected: 66 pre-existing tests still pass, plus the 3 new ones.

- [ ] **Step 6: Commit**

```bash
git add firmware/micropython/bringup.py hardware/rev2026/tests/test_bringup_firmware.py
git commit -m "Phase 2 bring-up self-test, with its no-HV invariant enforced"
```

---

### Task 4: Phase 2 — flash and run the self-test

**Files:**
- Modify: `hardware/rev2026/BRINGUP-LOG.md`

**Interfaces:**
- Consumes: `firmware/micropython/bringup.py` from Task 3; Task 2's gate.
- Produces: a Pico running MicroPython, with a verified I/O set.

- [ ] **Step 1: Identify the Pico variant**

Hold BOOTSEL, plug USB. A volume named `RPI-RP2` (RP2040) or `RP2350` mounts.

```bash
cat /Volumes/RPI-RP2/INFO_UF2.TXT 2>/dev/null || cat /Volumes/RP2350/INFO_UF2.TXT
```

The `Board-ID` line names the exact board — `RPI-RP2` for a Pico/Pico W, `RP2350` for a Pico 2/Pico 2 W. This determines which UF2 to fetch.

- [ ] **Step 2: Get the MicroPython UF2**

Downloading a file needs the operator's go-ahead. Ask before fetching; or the operator downloads the matching build from `micropython.org/download/` themselves. Do not guess the variant — flashing an RP2350 build to an RP2040 leaves a Pico that does not enumerate.

- [ ] **Step 3: Flash**

```bash
cp <micropython>.uf2 /Volumes/RPI-RP2/
```

The volume unmounts and the Pico reboots into MicroPython.

- [ ] **Step 4: Find the port**

```bash
ls /dev/tty.usbmodem*
```

- [ ] **Step 5: Run the self-test**

```bash
uv run --with mpremote mpremote connect /dev/tty.usbmodemXXXX run firmware/micropython/bringup.py
```

Watch the board through the LED walk, then press ARM and PULSE when prompted. Expected final line: `=== RESULT: PASS ===`.

- [ ] **Step 6: Append to the log**

```markdown
## Phase 2 — I/O self-test

Date: YYYY-MM-DD
MicroPython build:
Port:

| Check | Expected | Observed | Pass |
|---|---|---|---|
| STATUS LED | lights alone | | |
| HV_DET LED | lights alone | | |
| CHARGE LED | lights alone | | |
| All three together | all lit | | |
| CHARGED idle level | 1 | | |
| ARM button | PASS | | |
| PULSE button | PASS | | |

Notes:
```

- [ ] **Step 7: Gate**

Any LED that does not light, or either button not registering, stops the sequence. An LED failure is cosmetic but a button failure is not: `SW3` is a different switch from `SW1`/`SW2`, but a soldering problem on one tactile switch is reason to re-check all three, and `SW3` is the discharge control.

- [ ] **Step 8: Commit**

```bash
git add hardware/rev2026/BRINGUP-LOG.md
git commit -m "Phase 2 I/O self-test on board #1"
```

---

### Task 5: `chargetest.py`

**Files:**
- Create: `firmware/micropython/chargetest.py`
- Modify: `hardware/rev2026/tests/test_bringup_firmware.py`

**Interfaces:**
- Consumes: `GPIO_TO_PAD`, `_constants`, `_int_literals`, `node_to_net` fixture, and the `CHARGETEST` path constant — all already defined in `tests/test_bringup_firmware.py` by Task 3.
- Produces: `firmware/micropython/chargetest.py` with `PIN_HVPWM = 20`, `PIN_CHARGED = 18`, `PIN_HV_DET_LED = 6`, `CHARGE_TIMEOUT_MS`, `pwm_on()`, `pwm_off()`, `main()`.

- [ ] **Step 1: Write the failing tests**

Append to `hardware/rev2026/tests/test_bringup_firmware.py`:

```python
def test_chargetest_pin_map_matches_netlist(node_to_net):
    """chargetest.py's own pin constants land on the right nets."""
    expected = {
        'PIN_HVPWM': 'HVPWM',
        'PIN_CHARGED': 'CHARGED',
        'PIN_HV_DET_LED': 'HV_DET_LED',
    }
    consts = _constants(CHARGETEST)
    for name, fragment in expected.items():
        assert name in consts, f'{name} not defined in chargetest.py'
        gpio = consts[name]
        assert gpio in GPIO_TO_PAD, f'{name} = GP{gpio} is not a Pico GPIO'
        node = f'U1.{GPIO_TO_PAD[gpio]}'
        assert node in node_to_net, f'{name} = GP{gpio} ({node}) is not connected'
        assert fragment in node_to_net[node], \
            f'{name} = GP{gpio} sits on net {node_to_net[node]!r}, expected {fragment!r}'

def test_chargetest_does_not_pulse():
    """Pulsing is out of scope: GP14 must not appear."""
    assert 14 not in _int_literals(CHARGETEST), \
        'chargetest.py contains the literal 14 -- HVPULSE, pulsing is out of scope'

def test_chargetest_pwm_is_bounded():
    """Charging must be enabled only inside a try whose finally stops it.

    Without this, an exception mid-charge (a keyboard interrupt from
    mpremote, an mpremote disconnect) leaves the transformer running with
    nobody watching.
    """
    tree = ast.parse(CHARGETEST.read_text())
    tries = [n for n in ast.walk(tree) if isinstance(n, ast.Try) and n.finalbody]
    assert tries, 'chargetest.py has no try/finally'

    def calls_pwm_off(nodes):
        return any(isinstance(n, ast.Call) and isinstance(n.func, ast.Name)
                   and n.func.id == 'pwm_off'
                   for node in nodes for n in ast.walk(node))

    assert any(calls_pwm_off(t.finalbody) for t in tries), \
        'no try/finally in chargetest.py calls pwm_off() in its finally'

def test_chargetest_has_a_charge_timeout():
    """A charge attempt must be time-bounded, per the spec's Phase 3."""
    consts = _constants(CHARGETEST)
    assert 'CHARGE_TIMEOUT_MS' in consts, 'no CHARGE_TIMEOUT_MS in chargetest.py'
    assert 0 < consts['CHARGE_TIMEOUT_MS'] <= 30000, \
        f"CHARGE_TIMEOUT_MS = {consts['CHARGE_TIMEOUT_MS']} is not a sane bound"
```

- [ ] **Step 2: Run the tests to verify they fail**

```bash
cd hardware/rev2026 && uv run --with pytest pytest tests/test_bringup_firmware.py -v
```

Expected: the four new tests FAIL (`chargetest.py` does not exist); the three from Task 3 still PASS.

- [ ] **Step 3: Write `firmware/micropython/chargetest.py`**

```python
# PicoEMP commanded charge test -- Phase 3
#
# The ONLY script in this set that drives GP20 (HVPWM). It charges for at
# most CHARGE_TIMEOUT_MS, reports whether CHARGED asserted, then stops the
# PWM unconditionally and waits for the operator to discharge with SW3.
#
# SAFETY: J1's centre pin carries HV_RAIL from the moment CHARGED asserts
# until discharge -- not only during a pulse. Cap it, keep the shield on,
# and hold SW3 for a second before touching anything.
#
# Run with:  mpremote connect <port> run chargetest.py

from machine import Pin, PWM
import utime

PIN_HVPWM = 20
PIN_CHARGED = 18
PIN_HV_DET_LED = 6
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

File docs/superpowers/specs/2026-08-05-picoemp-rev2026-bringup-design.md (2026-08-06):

# PicoEMP Rev-2026 — First-Article Bring-Up Spec

**Date:** 2026-08-05
**Status:** Approved
**Subject:** First assembled Rev-2026 board, serial #1
**Board branch:** `rev2026`

---

## 1. Goal

Take one hand-assembled Rev-2026 board from "just soldered" to "verified able to
charge and discharge its high-voltage rail," without ever putting the operator
or the board at risk of a fault that a cheaper test would have caught first.

Pulse output is explicitly **out of scope**. No injection tip exists yet, and an
open SMA is the wrong load for a first pulse. See §8.

## 2. Constraints

| Constraint | Value |
|---|---|
| Test equipment | DMM; bench PSU with adjustable current limit |
| No oscilloscope | Rail voltage is **inferred**, never measured (§7) |
| No HV probe | Same |
| Injection tip | None available |
| HV shield | Hot-glued in place — see §6 |

## 3. Established facts

These were verified against the netlist and board file, not assumed.

**Stock firmware runs unmodified.** Every GPIO in `cspico_simple.py` and
`firmware/c/` matches this board:

| Net | Pico pin | GPIO | Firmware |
|---|---|---|---|
| `ARM_SW` | 34 | GP28 | `Pin(28)` |
| `PULSE_SW` | 15 | GP11 | `Pin(11)` |
| `CHARGED` | 24, 31 | GP18, GP26/ADC0 | `Pin(18)` |
| `CHARGE_LED` | 32 | GP27 | `Pin(27)` |
| `HV_DET_LED` | 9 | GP6 | `Pin(6)` |
| `STATUS_LED` | 10 | GP7 | `Pin(7)` |
| `HVPULSE` | 19 | GP14 | `pulse_out_pin = 14` |
| `HVPWM` | 26 | GP20 | `Pin(20)` |
| `GP0` (trigger in) | 1 | GP0 | C fw `fast_trigger` |

**HV charging draws from the Pico's own 3V3 regulator**, not VBUS:
`+3V3 → D3 → R4 (75 R) / R3 (10 R) → T1 / T2 primaries`. USB alone powers the
whole board, and 3V3-rail current is therefore a direct charging indicator.

**An unprogrammed Pico cannot charge.** GPIOs default high-Z; `R5` and `R10`
pull Q3's and Q4's gates to `GND`. HV-off is the passive state.

**`SW3` is the discharge control.** It shorts `HV_SENSE ↔ HV_RTN`, shunting R1
and the opto LED and leaving `R2` (300 k) across C3 — τ = 141 ms, peak 833 µA.
Unattended, C3 also self-bleeds through R2 + R1 + opto at τ ≈ 9.5 s, down to the
opto LED knee.

**The SMA carries the rail continuously while charged.** `J1` pad 1 (centre pin)
is on `HV_RAIL`; pads 2 (shell tabs) are on `HV_OUT`. The centre pin sits at
approximately the full rail relative to the shell from the moment `CHARGED`
asserts until discharge — not only during a pulse. J1 is outside the shield by
design.

## 4. Probe points

The 2.54 mm headers make every signal reachable without clipping to fine-pitch
parts.

| Signal | Location |
|---|---|
| `GND` | P3.3, P2.1, P1.7, J2.2 |
| `+3V3` | P3.2 |
| `CHARGED` | P3.1 |
| `HVPWM` | P3.4 |
| `HVPULSE` | P2.2 |
| `TRIG_IN` | P1.1, J4 centre |
| `HV_RTN` | J3.1 |
| `HV_SENSE` | J3.2 |
| `HV_RAIL` | J1 centre pin |
| `HV_OUT` | J1 shell |

`J2` is an S2B-XH-A (JST XH, 2.50 mm): pin 1 = `VEXT_IN`, pin 2 = `GND`.

## 5. Phases

Each phase gates the next. A failure stops the sequence.

### Phase 0 — cold checks

Nothing powered. On the first run the board has never been energized, so C3
cannot hold charge. If Phase 0 is repeated after Phase 3, hold `SW3` for one
second first.

| # | Measurement | Expect | Meaning of failure |
|---|---|---|---|
| 0.1 | J1 centre → J3.2 | 300 kΩ ±5 % | `R2` missing or bad — no fast discharge path |
| 0.2 | **Hold SW3**, J1 centre → J3.1 | 300 kΩ ±5 % | `SW3` not closing — no manual discharge |
| 0.3 | Any GND → J3.1 | open (> 20 MΩ) | Isolation barrier breached |
| 0.4 | J1 centre → J1 shell | not a short | IGBT `Q2` shorted C-to-E |
| 0.5 | P3.2 → GND | not a short | 3V3 rail fault |
| 0.6 | J2.1 → GND | not a short | Input rail fault |

0.1 and 0.2 together validate the complete discharge loop **before anything can
charge**. This is the single highest-value phase.

One reading to expect but not to trust: `J3.2 → J3.1` with SW3 **released**
runs through R1 plus the opto LED. A DMM's ohms source is typically under 1 V
and will not forward-bias the LED, so it reads open rather than 20 MΩ. That is
normal and is why 0.2 holds SW3 instead.

### Phase 1 — first power, current-limited, no firmware

Bench PSU **5.0 V, limit 100 mA**, into J2. USB unplugged. Pico unprogrammed.

- PSU must not enter current limit.
- `+3V3` at P3.2 reads 3.3 V ±5 %.

Pass criterion: rail up, no current limit. This is the assembly-short screen; it
is the only phase where current limiting is load-bearing.

### Phase 2 — bring-up firmware over USB

Flash MicroPython, then a purpose-written bring-up script — **not** stock
firmware.

The script's defining property: **it never configures GP20.** `HVPWM` stays
high-Z, so charging is impossible for as long as it runs. There is no command,
no code path, and no button that can make high voltage in Phase 2.

It must:
- drive `STATUS_LED`, `HV_DET_LED` and `CHARGE_LED` individually on command
- report `ARM_SW`, `PULSE_SW` and `CHARGED` state
- print over USB serial, drivable through the serial MCP tools

Pass criterion: all three LEDs light on command; both buttons read correctly;
`CHARGED` reads its idle state.

### Phase 3 — first charge

Shield glued down. Plastic dust cap on J1. USB power (Phase 1 already cleared
shorts, and the console is needed here).

Add a **time-limited, explicitly commanded** charge routine to the script:
enable HVPWM at the tuned 2500 Hz / 1.22 % duty, with a hard timeout.

Expected sequence:
1. 3V3-rail current steps up.
2. After a few seconds, `CHARGED` asserts and the HV LED lights.
3. Stop PWM.
4. Press `SW3`. `CHARGED` de-asserts.

Pass criterion: charge asserts, and discharge drops it. Hands clear of J1 for
the whole phase.

### Phase 4 — stock firmware

`cspico_simple.py` as `main.py`, or the C firmware for its serial console.
Confirm ARM and the HV LED behave as in Phase 3. **Still no pulsing.**

## 6. HV shield

The 1551G box seats only from the underside: the board's `MH1`/`MH2` pattern is
the mirror of the box's screw diagonal.

For this article the box is **hot-glued** over the HV section. This is accepted
as adequate for Phases 3–4 — the box is captive, the operator's hands stay clear
of it, and J1 (the actual exposed hazard) is outside the shield either way.

Expect the box to rock rather than sit flush: `Q2` is a known rim fouler
(0.00 mm clear against 2.32 mm needed) and was the last open layout item. Glue
takes up the gap.

**Root cause, for the next revision.** The re-axed `Hammond_1551G_Box.step`
places its two Ø2.50 bores at (−11.75, −19.25) and (+11.75, +19.25) from shell
centre — exactly where MH1/MH2 sit. But KiCad negates Y when placing a 3D model
at a footprint, so model-frame Y runs opposite to board-frame Y. Positions read
off the model and used directly as board coordinates come out mirrored, which
flips a diagonal pair onto the other diagonal.

Fix: **swap MH1's and MH2's Y coordinates.** They already sit at shell-centre
∓19.25, so the swap mirrors the pair without moving anything else. To be
confirmed against the physical box before the file is edited. Not part of this
bring-up.

## 7. What is not being measured

With no HV probe, rail voltage is never read directly. `CHARGED` asserting means
enough voltage to drive the sense chain's opto through R2 + R1 — it does **not**
confirm ~250 V. The firmware's tuned duty cycle is the only basis for that
figure.

Consequence: Phase 3 proves the charge and discharge *mechanisms* work. It does
not qualify the rail voltage. Anything depending on a known rail — pulse energy,
repeatability — waits for a probe.

## 8. Out of scope

**Pulsing.** With no tip the SMA is an open circuit, so a pulse dumps nothing
and leaves the rail standing on an exposed centre pin. Pulse bring-up needs a
tip or dummy load and is a separate session.

Suggested tip parts, per `hardware/injection_tips/README.md`: Würth `744710603`
ferrite-core inductor plus a `CONSMA013.062` edge-mount SMA male.

## 9. Safety rules for every phase

1. `SW3` for one second before touching the board, whenever it has been armed.
2. Never touch J1. Keep a plastic dust cap fitted from Phase 3 on.
3. Shield stays glued down from Phase 3 on.
4. One hand behind your back while any phase can charge — no path across the
   chest.

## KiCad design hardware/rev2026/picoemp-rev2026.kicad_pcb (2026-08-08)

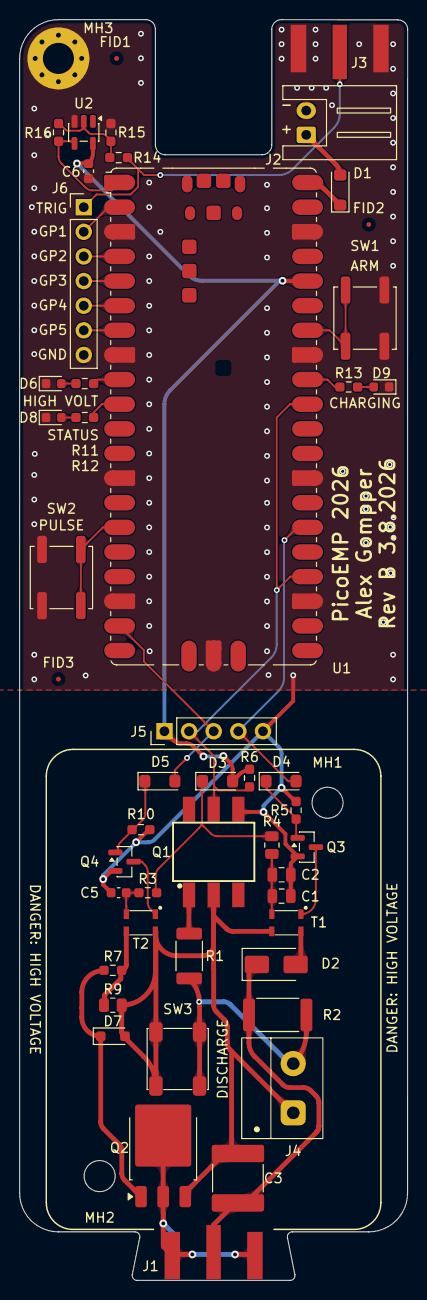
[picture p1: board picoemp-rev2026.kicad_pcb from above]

Board: 2 copper layers, 40.0 x 130.0 mm, 52 parts (0 on the bottom side), 38 nets.

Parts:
C1, C2: 4.7uF/50V; C_0805_2012Metric
C3: 0.47uF,630V,X7T; C_2220_5750Metric
C5, C6: 100n; C_0603_1608Metric
D1, D3, D4, D5: SM4005PL-TP; D_SOD-123FL
D2: MURA160T3G; D_SMA
D6, D9: LED, 0603, Red; LED_0603_1608Metric
D7: MM3Z18VB; D_SOD-323_HandSoldering
D8: LED, 0603, Green; LED_0603_1608Metric
FID1, FID2, FID3: Fiducial; Fiducial_0.5mm_Mask1.5mm
J1, J3: EDGE-SMA; SMA_Linx_CONSMA020_062_G_EdgeMount
J2: 1x2_Pin_Header; JST_XH_S2B-XH-A_1x02_P2.50mm_Horizontal
J4: MKDSN 1,5/2-5,08; TerminalBlock_Phoenix_MKDSN-1,5-2-5.08_1x02_P5.08mm_Horizon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
J5: Header 4; PinHeader_1x05_P2.54mm_Vertical
J6: Header 7; PinHeader_1x07_P2.54mm_Vertical
MH1, MH2: M3; MountingHole_3.2mm_M3
MH3: M3; MountingHole_3.2mm_M3_Pad_Via
Q1: LDA111STR; SOP-6_LDA111
Q2: RGT16BM65DTL; TO-252-3_TabPin2
Q3, Q4: AO3422; SOT-23
R1: 20M; R_2010_5025Metric
R2: 300K; R_2512_6332Metric
R3, R7: 10R; R_0603_1608Metric_Pad0.98x0.95mm_HandSolder
R4: 75R; R_0805_2012Metric
R5, R10, R11, R12, R13: 1k; R_0603_1608Metric_Pad0.98x0.95mm_HandSolder
R6: 22k; R_0603_1608Metric_Pad0.98x0.95mm_HandSolder
R9: 2k; R_0805_2012Metric
R14: 100R; R_0603_1608Metric_Pad0.98x0.95mm_HandSolder
R15: 10k; R_0603_1608Metric_Pad0.98x0.95mm_HandSolder
R16: 0R; R_0603_1608Metric_Pad0.98x0.95mm_HandSolder
SW1, SW2: KSC741J LFS; SW_Push_1P1T_NO_CK_KSC7xxJ
SW3: TL3301AF160QJ; SW_Push_ESwitch_TL3301AJ
T1, T2: ATB322524
U1: SC0915; RaspberryPi_Pico_SMD
U2: 74LVC1G17; SOT-23-5

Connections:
+3V3: C6.1, D3.2 (A), J5.1, R6.2, U1.36 (3V3), U2.5 (VCC)
/ARM_SW: SW1.1, U1.34 (GPIO28_ADC2)
/CHARGED: J5.2, Q1.5 (C), R6.1, U1.24 (GPIO18), U1.31 (GPIO26_ADC0)
/CHARGE_LED: R13.1, U1.32 (GPIO27_ADC1)
/GP0: R16.1, U1.1 (GPIO0), U2.4
/GP1: J6.2, U1.2 (GPIO1)
/GP2: J6.3, U1.4 (GPIO2)
/GP3: J6.4, U1.5 (GPIO3)
/GP4: J6.5, U1.6 (GPIO4)
/GP5: J6.6, U1.7 (GPIO5)
/HVPULSE: D5.2 (A), J5.3, U1.19 (GPIO14)
/HVPWM: D4.2 (A), J5.4, U1.26 (GPIO20)
/HV_DET_LED: R11.1, U1.9 (GPIO6)
/HV_GATE: D7.1 (K), Q2.1 (G), R7.1
/HV_GATE_DRV: R7.2, R9.2, T2.3
/HV_OUT: J1.2 (Ext), Q2.2 (C)
/HV_RAIL: C3.2, D2.1 (K), J1.1 (In), R2.1
/HV_RECT: D2.2 (A), T1.2
/HV_RTN: C3.1, D7.2 (A), J4.1, Q1.2 (K), Q2.3 (E), R9.1, SW3.1, T1.3, T2.2
/HV_SENSE: J4.2, R1.1, R2.2, SW3.2
/HV_SENSE_LED: Q1.1 (A), R1.2
/LED_CHARGE_A: D9.2 (A), R13.2
/LED_HV_DET_A: D6.2 (A), R11.2
/LED_STATUS_A: D8.2 (A), R12.2
/PRI_CLAMP: D3.1 (K), R3.2, R4.2
/PULSE_SW: SW2.1, U1.15 (GPIO11)
/Q3_GATE: D4.1 (K), Q3.1 (G), R5.2
/Q4_GATE: D5.1 (K), Q4.1 (G), R10.2
/STATUS_LED: R12.1, U1.10 (GPIO7)
/T1_PRI_A: Q3.3 (D), T1.1
/T1_PRI_B: C1.2, C2.2, R4.1, T1.4
/T2_PRI_A: Q4.3 (D), T2.1
/T2_PRI_B: C5.2, R3.1, T2.4
/TRIG_BUF: R14.2, R15.1, R16.2, U2.2
/TRIG_IN: J3.1 (In), J6.1, R14.1
/VBUS: D1.1 (K), U1.40 (VBUS)
/VEXT_IN: D1.2 (A), J2.1
GND: C1.1, C2.1, C5.1, C6.2, D6.1 (K), D8.1 (K), D9.1 (K), J2.2, J3.2 (Ext), J5.5, J6.7, MH3.1 (1_1), Q1.4 (E), Q3.2 (S), Q4.2 (S), R5.1, R10.1, R15.2, SW1.2, SW2.2, U1.3 (GND), U1.8 (GND), U1.13 (GND), U1.18 (GND), U1.23 (GND), U1.28 (GND), U1.33 (AGND), U1.38 (GND), U1.D2 (GND), U2.3 (GND)

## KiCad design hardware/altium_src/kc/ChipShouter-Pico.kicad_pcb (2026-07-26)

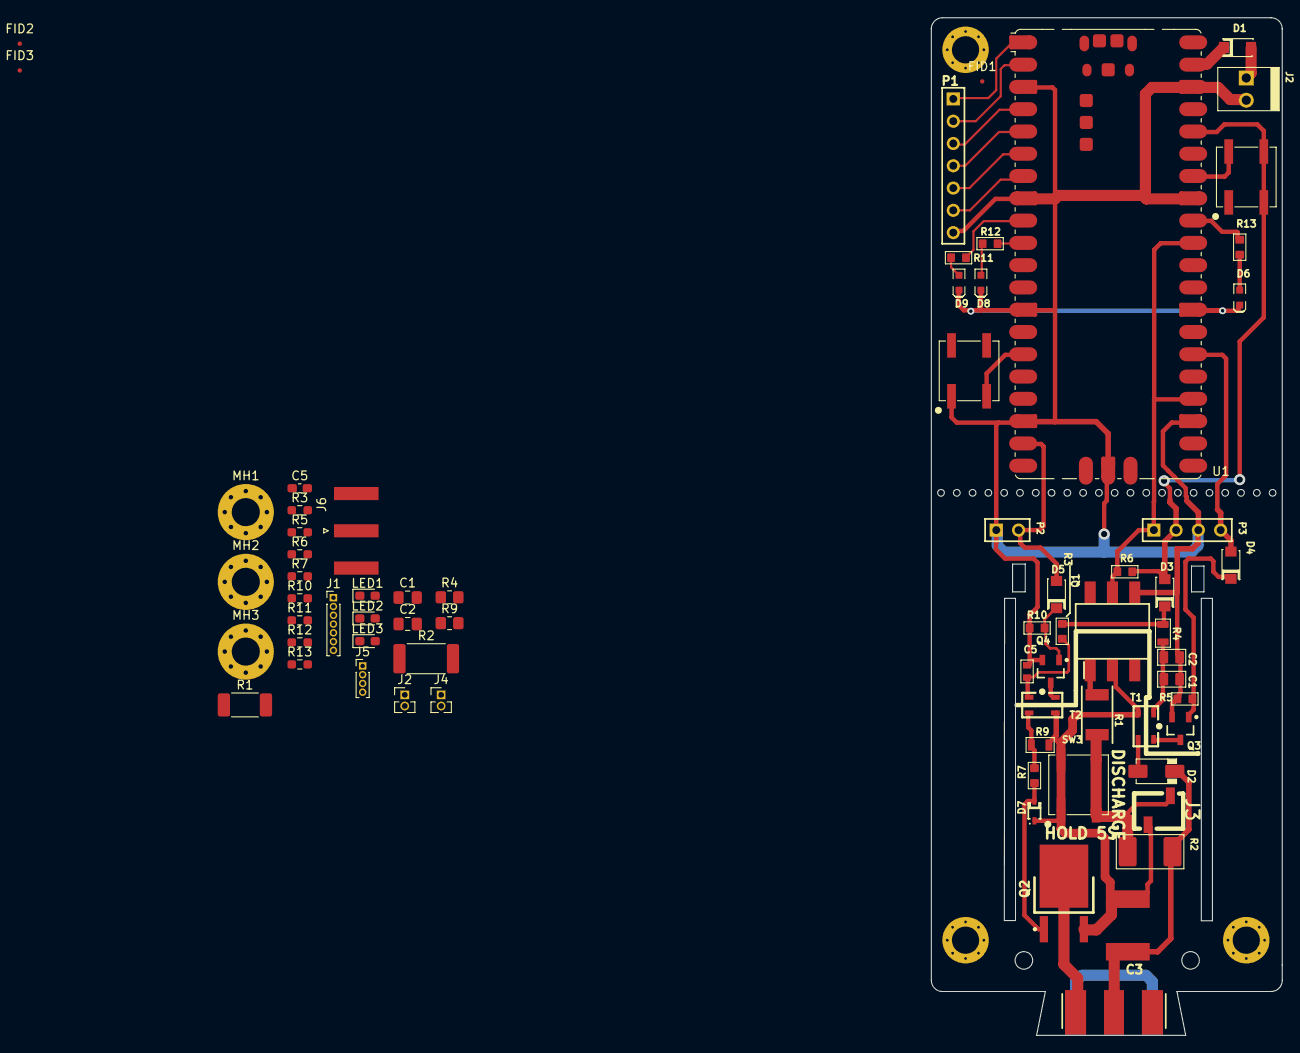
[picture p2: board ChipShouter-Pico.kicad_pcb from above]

Board: 2 copper layers, 40.0 x 116.0 mm, 73 parts (0 on the bottom side), 47 nets.

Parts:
C1, C2: 4.7uF/50V; C_0805_2012Metric_Pad1.18x1.45mm_HandSolder
C1#2, C2#2: 4.7uF/50V; CAPC0805_M
C3: 0.47uF,630V,X7T; CKG57N_2220
C5: ${ALTIUM_VALUE}; C_0603_1608Metric_Pad1.08x0.95mm_HandSolder
C5#2: 100n; CAPC0603_M
D1, D3, D4, D5: DSS13UTR
D2: MURA160T3G; DO-214AC
D6, D9: LED, 0603, Red; LED-0603-RED
D7: MM3Z18VB; SOD323
D8: LED, 0603, Green; LED-0603-GREEN
FID1, FID2, FID3: Fiducial; Fiducial_0.5mm_Mask1.5mm
J1: Header 7; PinHeader_1x07_P1.00mm_Vertical
J1#2: EDGE-SMA; CON-SMA-MALE-PCB-EDGE062
J2: 1x2_Pin_Header; PinHeader_1x02_P1.27mm_Vertical
J2#2: 1x2_Pin_Header; 22-23-2021
J3: BG306-02-A-2-0400-L-G; BG306-R2-2PIN
J4: Header 2; PinHeader_1x02_P1.27mm_Vertical
J5: Header 4; PinHeader_1x04_P1.00mm_Vertical
J6: EDGE-SMA; SMA_Amphenol_132289_EdgeMount
LED1, LED3: LED, 0603, Red; LED_0603_1608Metric_Pad1.05x0.95mm_HandSolder
LED2: LED, 0603, Green; LED_0603_1608Metric_Pad1.05x0.95mm_HandSolder
MH1, MH2, MH3#2: M3; MountingHole_3.2mm_M3_Pad_Via
MH1#2, MH2#2, MH3: M3, Tight Fit; MOUNT_M3_TIGHT
P1: Header 7; HDR1X7
P2: Header 2; HDR1X2
P3: Header 4; HDR1X4
Q1: LDA111STR; SOP254P952X470-6N
Q2: RGT16BM65DTL; DPAK_TO-252AA_M
Q3, Q4: AO3422; SOT95P245X110-3M
R1: 20M; R_2010_5025Metric_Pad1.40x2.65mm_HandSolder
R1#2: 20M; RESC5025X06N
R2: 300K; RESC6432X06N
R2#2: 300K; R_2512_6332Metric_Pad1.40x3.35mm_HandSolder
R3, R7: 10R; R_0603_1608Metric_Pad0.98x0.95mm_HandSolder
R3#2, R7#2: 10R; RESC1608X55N
R4: 75R; RESC2012X70N
R4#2: 75R; R_0805_2012Metric_Pad1.20x1.40mm_HandSolder
R5, R10, R11#2, R12, R13: 1k; RESC1608X55N
R5#2, R10#2, R11, R12#2, R13#2: 1k; R_0603_1608Metric_Pad0.98x0.95mm_HandSolder
R6: 22k; RESC1608X55N
R6#2: 22k; R_0603_1608Metric_Pad0.98x0.95mm_HandSolder
R9: 2k; RESC2012X70N
R9#2: 2k; R_0805_2012Metric_Pad1.20x1.40mm_HandSolder
SW1, SW2, SW3: KSC741J LFS; CK_KSC7J
T1, T2: ATB322524
U1: SC0915; RaspberryPi_Pico_SMD

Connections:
+3V3: J5.2, R6#2.2, U1.36 (3V3)
/CHARGED: J5.1, R6#2.1, U1.24 (GPIO18), U1.31 (GPIO26_ADC0)
/HVPULSE: J4.2, U1.19 (GPIO14)
/HVPWM: J5.4, U1.26 (GPIO20)
CHARGED: P3.1, Q1.5, R6.2
GND: C1.1, C1#2.2, C2.1, C2#2.2, C5.1, C5#2.2, D6.K, D8.K, D9.K, J1.7, J2.2, J2#2.2, J4.1, J5.3, LED1.1 (K), LED2.1 (K), LED3.1 (K), P1.7, P2.1, P3.3, Q1.4, Q3.2, Q4.2, R5.2, R5#2.1, R10.2, R10#2.1, SW2.1, U1.3 (GND), U1.8 (GND), U1.13 (GND), U1.18 (GND), U1.23 (GND), U1.28 (GND), U1.33 (AGND), U1.38 (GND), U1.D2 (GND)
HVPULSE: D5.A, P2.2
HVPWM: D4.A, P3.4
unnamed: C1.2, C2.2, R4#2.1
unnamed: C5.2, R3.1
unnamed: J6.1 (In), R2#2.1
unnamed: R3.2, R4#2.2
unnamed: R1.2, R9#2.1
unnamed: J1.1, U1.1 (GPIO0)
unnamed: J1.2, U1.2 (GPIO1)
unnamed: J1.3, U1.4 (GPIO2)
unnamed: J1.4, U1.5 (GPIO3)
unnamed: J1.5, U1.6 (GPIO4)
unnamed: J1.6, U1.7 (GPIO5)
unnamed: R1.1, R2#2.2
unnamed: LED1.2 (A), R11.2
unnamed: LED2.2 (A), R12#2.2
unnamed: LED3.2 (A), R13#2.2
unnamed: R7.2, R9#2.2
unnamed: R11.1, U1.9 (GPIO6)
unnamed: R12#2.1, U1.10 (GPIO7)
unnamed: R13#2.1, U1.32 (GPIO27_ADC1)
NetC1_1: C1#2.1, C2#2.1, R4.2, T1.4
NetC3_1: C3.1, D2.K, J1#2.1, R2.2
NetC3_2: C3.2, D7.A, J3.1, Q1.2, Q2.2, R9.2, SW3.1, SW3.4, T1.3, T2.2
NetC5_1: C5#2.1, R3#2.2, T2.4
NetD1_A: D1.A, J2#2.1
NetD2_A: D2.A, T1.2
NetD3_K: D3.K, R3#2.1, R4.1
NetD4_K: D4.K, Q3.1, R5.1
NetD5_K: D5.K, Q4.1, R10.1
NetD6_A: D6.A, R13.1
NetD7_K: D7.K, Q2.1, R7#2.2
NetD8_A: D8.A, R12.1
NetD9_A: D9.A, R11#2.1
NetJ1_2: J1#2.2, J1#2.3, J1#2.4, J1#2.5, Q2.3
NetJ3_2: J3.2, R1#2.2, R2.1, SW3.2, SW3.3
NetQ1_1: Q1.1, R1#2.1
NetQ3_3: Q3.3, T1.1
NetQ4_3: Q4.3, T2.1
NetR7_1: R7#2.1, R9.1, T2.3
VCC: D3.A, P3.2, R6.1, SW1.2, SW1.3

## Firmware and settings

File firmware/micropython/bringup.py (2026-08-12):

# PicoEMP bring-up self-test -- Phase 2
#
# Exercises every driven LED, all three buttons and the CHARGED input, and
# prints a structured result. It CANNOT make high voltage: GP20 (HVPWM) and
# GP14 (HVPULSE) are never referenced, so both stay high-Z and R5/R10 hold the
# Q3/Q4 gates at GND. GP12 (SAFE_DRV) is likewise never driven, so the U4
# photorelay stays open. tests/test_bringup_firmware.py enforces that.
#
# Run with:  mpremote connect <port> run bringup.py
# Do not save this as main.py -- it is a test, not the firmware.

from machine import Pin, ADC
import utime

PIN_STATUS_LED = 7
PIN_CHARGE_LED = 27
PIN_SAFE_LED = 15
PIN_ARM_SW = 28
PIN_PULSE_SW = 11
PIN_SAFE_SW = 13
PIN_CHARGED = 18
# CHARGED lands on two Pico pads: GP18 (U1.24) and GP26/ADC0 (U1.31). Both
# must be configured -- see the comment in main().
PIN_CHARGED_ADC = 26

# D6 (red, HV present) is deliberately absent: Q5 inverts CHARGED in hardware,
# so no GPIO drives it and there is nothing here to exercise. Confirm it by
# charging the rail (chargetest.py), not by blinking it. GP6 is now free.
LEDS = (
    ('STATUS', PIN_STATUS_LED),
    ('CHARGE', PIN_CHARGE_LED),
    ('SAFE', PIN_SAFE_LED),
)

BUTTON_TIMEOUT_MS = 15000


def led_walk():
    """Light each LED alone for a second, then all three together."""
    pins = [(name, Pin(gpio, Pin.OUT)) for name, gpio in LEDS]
    for _, pin in pins:
        pin.off()
    for name, pin in pins:
        print('LED %s: ON -- confirm it lit' % name)
        pin.on()
        utime.sleep_ms(1000)
        pin.off()
    print('LED ALL: ON')
    for _, pin in pins:
        pin.on()
    utime.sleep_ms(2000)
    for _, pin in pins:
        pin.off()
    print('LED ALL: OFF')


def wait_for_press(name, pin, pressed_level):
    """Block until `pin` reads `pressed_level`, or the timeout expires."""
    print('BUTTON %s: press it now (%d s)' % (name, BUTTON_TIMEOUT_MS // 1000))
    deadline = utime.ticks_add(utime.ticks_ms(), BUTTON_TIMEOUT_MS)
    while utime.ticks_diff(deadline, utime.ticks_ms()) > 0:
        if pin.value() == pressed_level:
            print('BUTTON %s: PASS' % name)
            return True
        utime.sleep_ms(10)
    print('BUTTON %s: FAIL -- no press seen' % name)
    return False


def main():
    print('=== PicoEMP bring-up self-test (Phase 2) ===')
    print('HVPWM and HVPULSE are not driven by this script.')

    led_walk()

    # All three buttons pull their net down to GND, so pressed reads low
    # against a pullup. SW1 used to pull ARM_SW up to +3V3 instead; that
    # asymmetry was inherited from upstream's milled single-layer prototype
    # and was dropped when the arm switch moved to GND.
    #
    # SW4 (SAFE) is read only. It does NOT drive SAFE_DRV (GP12) here -- the
    # photorelay is left alone so this script cannot actuate anything on the
    # HV side, same reasoning as HVPWM/HVPULSE above.
    arm = Pin(PIN_ARM_SW, Pin.IN, Pin.PULL_UP)
    pulse = Pin(PIN_PULSE_SW, Pin.IN, Pin.PULL_UP)
    safe = Pin(PIN_SAFE_SW, Pin.IN, Pin.PULL_UP)
    # CHARGED needs BOTH its pads configured. The RP2040 resets every GPIO
    # pad with its pull-down enabled (PADS_BANK0 reset value 0x56, bit 2
    # PDE=1), and CHARGED reaches two pads. Leaving GP26 at its default puts
    # a second ~65k pull-down on the net; the pair in parallel against R6's
    # 22k pull-up divides it to roughly 2 V, inside the RP2040's
    # indeterminate band (VIL 0.99 V, VIH 2.31 V), and the digital read
    # becomes arbitrary. Configuring GP26 as an analog input disables its
    # digital pull, leaving R6 -- the intended pull-up -- in charge.
    charged_adc = ADC(PIN_CHARGED_ADC)
    charged = Pin(PIN_CHARGED, Pin.IN, None)

    volts = charged_adc.read_u16() * 3.3 / 65535
    print('CHARGED idle: level %d, %.2f V (expect 1 and > 2.9 V at rest)'
          % (charged.value(), volts))
    if 1.0 < volts < 2.9:
        print('WARNING: CHARGED is in the indeterminate band -- the digital '
              'level above is not trustworthy.')

    ok_arm = wait_for_press('ARM', arm, 0)
    ok_pulse = wait_for_press('PULSE', pulse, 0)
    ok_safe = wait_for_press('SAFE', safe, 0)

    ok = ok_arm and ok_pulse and ok_safe
    print('=== RESULT: %s ===' % ('PASS' if ok else 'FAIL'))


main()

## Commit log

2026-07-26 Add in-progress KiCad migration of REV04, plus audit
    Captures the partially completed Altium -> KiCad port under
    hardware/altium_src/kc/ exactly as received, before any rework.
    This state is NOT fabricable. audit/AUDIT.md documents the findings:
    20 duplicated footprints on the board, a netlist split between legacy
    Altium and new KiCad net names with all 384 routed segments on the
    legacy side, all five header footprints at the wrong pitch, and 26
    unregistered libraries. It also covers 2026 part lifecycle: the TDK
    ATB322524 transformer and ROHM RGT16BM65DTL IGBT are both NRND, and
    the Kingbright APT1608SRCPRV red LED is obsolete.
    Upstream is unmodified. Licensed CC BY-SA 3.0, (c) NewAE Techn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
    [ChipShouter-Pico.kicad_pcb, ChipShouter-Pico.kicad_sch, bom-gap-analysis.csv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]
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2026-07-26 Scaffold rev2026 project and pytest design-rule harness
    Copies the as-received Altium-exported schematic/project into
    hardware/rev2026/ and adds a minimal s-expression parser plus pytest
    harness (kicad_parse.py, conftest.py, test_schematic.py) that later
    rework tasks will use as their verification gate.
    Extends the planned parser with two additions requested by the human
    after the plan was written:
    - Node.start/.end source-offset tracking and property_span() so Task 3
    can structurally locate and remove (property ...) blocks instead of
    using regex.
    - kicad_happy_skills() to discover the kicad-happy plugin's skills dir
    by globbing the highest installed version, instead of hardcoding a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
    [picoemp-rev2026.kicad_sch]
2026-07-26 Add project-local library tables, sync component datasheets
    Registers picoemp symbol/footprint libraries under ${KIPRJMOD} and adds
    a partial datasheets/manifest.json via LCSC sync (element14 skipped: no
    API key configured). Coverage is intentionally partial until Task 3
    normalizes MPN fields.
    [test_libraries.py]
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2026-07-26 Flatten Altium value variables, normalize BOM fields, fix R9 part data
    Structural rewrite via the Task 1 s-expression parser and property_span()
    (tools/normalize_fields.py) instead of the plan's regex approach -- a
    parenthesis inside a property value would silently corrupt an s-expression
    edited with blind regex. Flattens ${ALTIUM_VALUE} to each symbol's literal
    value, renames MANUFACTURE PART NUMBER 1/MANUFACTURER_PART_NUMBER -> MPN,
    MANUFACTURE 1/MANUFACTURER_NAME -> Manufacturer, SUPPLIER PART NUMBER 1 ->
    DigiKey, and deletes 33 kinds of Altium/distributor cruft fields (PART
    NUMBER, COMPONENT GROUP/KIND/TYPE, PP ROTATION, SNAPEDA_LINK, etc). Verified
    against the pre-edit netlist export: s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
    [picoemp-rev2026.kicad_sch]
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2026-07-26 Add missing Manufacturer on Q3/Q4 (AO3422)
    Review finding: Q3/Q4 were the only two BOM symbols with an MPN but no
    Manufacturer. Spec §5.2's row for AO3422 lists only the part number, no
    maker, unlike every other bare-MPN row in this task (R1->Vishay,
    R3-R7->Yageo, R2->TE Connectivity, T1/T2->TDK, Q2->ROHM) which I did fill
    in. Set Manufacturer = Alpha & Omega Semiconductor, the AO3422's actual
    maker (the "AO" prefix is that company's own numbering scheme). DigiKey
    stays blank on both -- the spec has no DigiKey PN for this row, same as
    Q2/R1/T1/T2.
    [picoemp-rev2026.kicad_sch]
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2026-07-26 Fix IGBT diode connectivity gap and strengthen pin-mapping test
    The antiparallel diode's lead-in wires stopped 2.54mm short of the
    diode's cathode bar / anode triangle on both sides, leaving it floating
    as a disconnected glyph -- exactly the thing the symbol exists to show.
    Extend both lead polylines to butt against the diode terminals.
    Also replace test_igbt_pin_names' independent substring checks (which
    passed regardless of which pin got which name) with a per-pin-block
    (number, name) parse that asserts the exact 1=G/2=C/3=E mapping.
    [test_libraries.py]
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2026-07-26 Correct symbol classes: IGBT, enhancement MOSFETs, non-Schottky rectifiers
    D1/D3/D4/D5 were drawn as Schottky diodes. This is a documented
    upstream errata - hardware/README.md notes the schematic 'claimed they
    were Schottky diodes, but as @settinger caught this was never the case'.
    Q2 -> picoemp:IGBT_NCH_Diode, Q3/Q4 -> Transistor_FET:Q_NMOS_GSD,
    Q1 -> picoemp:LDA111, T1/T2 -> new picoemp:ATB322524 (primary on pins
    1/4, secondary on 2/3, matching this design's actual wiring rather than
    Device:Transformer_1P_1S's 1/2+3/4 grouping). D1/D3/D4/D5 -> Device:D_Small.
    Q2/Q3/Q4 pin numbering changes (D/G/S -> 1/2/3) required deliberate
    per-uuid pin reconnection rather than a bare lib_id swap, veri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
    [picoemp-rev2026.kicad_sch]
2026-07-26 Add netlist co-membership regression test for Q2/Q3/Q4 pin-remap
    Task 5 review flagged that the lib_id-only tests in test_schematic.py
    give no regression coverage for the actual safety property (Q2's
    gate/collector not being swapped on a 650V IGBT). Adds
    test_netlist_connectivity.py: shells out to kicad-cli sch export
    netlist, parses it, and asserts co-membership (not net names, which
    drift) for Q2/Q3/Q4's gate/source/drain and T1/T2's winding grouping.
    Verified the test has teeth: temporarily swapped the IGBT symbol's
    pin 1/2 numbers (simulating a library-level gate/collector swap) in
    both lib/picoemp.kicad_sym and the schematic's lib_symbols cache,
    confirmed test_igbt_pin_mapping_not_swap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
    [test_netlist_connectivity.py]
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2026-07-26 Add ATB322524 transformer and LDA111 SOP-6 footprints with pin-1 markers
    Land patterns extracted from manufacturer datasheets and the as-received
    board's real fabricated footprints, rather than distributor parametrics -
    the audit found distributor package data wrong for both D7 (SOD-323 vs
    SOD-323F) and SM4005PL-TP.
    - ATB322524: body/pin-grouping from TDK's ATB3225 datasheet, exact pad
    geometry cross-checked against the as-fabricated ATB322524:ATB322524
    footprint on the original board (net wiring confirms pins 1/4 = primary,
    2/3 = secondary).
    - SOP-6_LDA111: all 6 pads copied verbatim from the as-received board's
    SamacSys:SOP254P952X470-6N footprint, including pad 3 (electrically NC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
    [test_libraries.py]
2026-07-26 Fix LDA111 fused pads and D_SOD-123FL short land; add regression tests
    Two Critical review findings, both fixed:
    1. SOP-6_LDA111 pads were `(size 2.54 1.27)` rotated 90 degrees, which put
    the 2.54mm dimension along Y (the 2.54mm pitch axis), fusing adjacent
    same-column pads into one solid bar with zero gap -- shorting pins
    1-2-3 and 4-5-6 together. Dropped the rotation so 2.54mm runs along X
    (toe-to-heel) and 1.27mm along Y, leaving a 1.27mm gap. Widened the
    courtyard to match. Consequence: the as-received board's
    SamacSys:SOP254P952X470-6N footprint that this geometry was copied from
    is itself corrupt (an Altium->KiCad import artifact) -- do not trust
    that board's f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
    [test_libraries.py]
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2026-07-26 Assign resolvable footprints to all but switches, headers and J3
    Fills in every symbol whose footprint was empty, a bare manufacturer
    part number, a HandSolder-pad variant string, or the corrupt Altium
    SamacSys path, per the Rev-2026 design spec section 6.1. D1/D3/D4/D5
    use the project-local picoemp:D_SOD-123FL (Task 6) rather than KiCad's
    stock D_SOD-123F, whose land is 0.3mm narrower than the correct part.
    SW1-3 and J3 stay empty (Task 8/9/11 own them); J1/J4/J5 keep their
    wrong-pitch Altium header footprints since they get renamed to
    P1/P2/P3 with 2.54mm footprints in Task 8.
    [picoemp-rev2026.kicad_sch]
2026-07-26 Add and adjust Task 7 footprint-assignment tests
    FOOTPRINTS is keyed by current ref designators, not the upstream ones
    the brief and design spec use: J1 (SMA) and the trigger front-end
    parts (U2, C6, new J4) don't exist under those names yet -- they only
    land after Task 8's designator rename and Task 9's new-parts work. The
    dict keeps every footprint value from the brief but points 'J1's
    target at the current J6 (already correct) and drops U2/C6/new-J4
    entirely, since a nonexistent symbol can't carry a wrong footprint.
    Also scoped test_every_footprint_has_a_library_prefix to symbols that
    have a footprint at all, so it doesn't double-flag the same SW1-3/J3
    gap that test_every_symbol_has_a_fo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
    [test_schematic.py]
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2026-07-26 Restore upstream designators and fix header pitch to 2.54mm
    The port had P1/P2/P3 replaced by 1.00mm and 1.27mm headers - a 2-2.5x
    pitch error on every one. Restoring upstream designators keeps
    BUILD-DRAWING-REV04.PDF and the README BOM explainer applicable.
    Renames (verified to move zero netlist connections via before/after
    membership comparison): LED1/2/3 -> D6/D8/D9, J1/J4/J5 (headers) ->
    P1/P2/P3, J6 (SMA) -> J1. Headers get 2.54mm-pitch footprints. Cleared
    stale DNP/in_bom=no flags on P1/P2/P3/J2/J3 left over from the
    half-finished port.
    SW1-3 get footprints: SW1/SW2 share KiCad's stock
    Button_Switch_SMD:SW_Push_1P1T_NO_CK_KSC7xxJ land (C&K KSC741JLFS).
    SW3 (E-Switch TL3301AF160QJ) ge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
    [picoemp-rev2026.kicad_sch]
2026-07-26 Update Task 8 tests: re-key FOOTPRINTS, fix forward-referencing EXPECTED_REFS, point J6->J1 in netlist test
    Appends the brief's Task 8 test coverage (designator restoration,
    2.54mm header pitch, switch footprints, full-ref-set check), with two
    corrections: EXPECTED_REFS and test_upstream_designators_restored both
    required Task 9's new J4 (SMA trigger input)/C6/U2/R14-16, none of
    which exist yet - same class of forward-reference bug Task 7 already
    found and fixed in the FOOTPRINTS dict. Removed the not-yet-existing
    refs so these tests reflect Task 8's actual scope instead of failing
    permanently until Task 9 lands.
    Re-keys FOOTPRINTS to the final post-rename designators (J1 for the
    SMA, adds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
    [test_netlist_connectivity.py, test_schematic.py]
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2026-07-26 Add buffered trigger front-end, widen J3, gate on ERC and netlist parity
    Trigger input gains a 74LVC1G17 Schmitt buffer (5.5V tolerant), series
    and pulldown resistors, and a DNP bypass. J3 moves to 5.08mm: its
    2.07mm pad gap failed IEC 60664-1 creepage at ~600V and the BG306's
    500VAC rating is a proof test, not a working rating.
    - U2 = Nexperia 74LVC1G17GV,125 (SOT-23-5), pinout verified against both
    the Nexperia and TI datasheets (1=NC, 2=A, 3=GND, 4=Y, 5=VCC).
    - J3 = Phoenix Contact MKDS 1,5/2-5.08 terminal block (DigiKey 277-1263-ND).
    - Pre-existing GND/AGND pin_to_pin ERC error resolved via a UUID-targeted
    erc_exclusions entry in the project file (not a net-tie or global
    severity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
    [picoemp-rev2026.kicad_sch]
2026-07-26 Add netlist-level regression test for the trigger front-end connectivity
    Review flagged that test_netlist.py only checked pre-existing Pico
    firmware pins, with nothing asserting the new trigger front-end's own
    wiring -- a swapped/floating U2 supply pin or an accidental direct
    P1.1-to-GP0 reconnect would have passed silently. Added
    test_trigger_front_end_connectivity, asserting by pin co-membership
    (U2 VCC/GND/input/output placement, plus a negative assertion that
    P1.1 and GP0 are NOT on the same net). Verified the test has teeth by
    injecting two regressions into a scratch copy and confirming failure
    before reverting cleanly.
    [test_netlist.py]
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2026-07-26 Fix Q1 optocoupler LED feedback path (floating anode from Altium import)
    Q1 (LDA111) pin 1, the LED anode, had a no_connect flag left over from the
    Altium->KiCad import, and R1's free end ran straight into Net-(D7-A) (the
    HV return) instead of into Q1 pin 1. This shorted the feedback LED out of
    the circuit: no LED current, phototransistor never conducts, /CHARGED
    never asserts.
    Rewired R1's free pin to Q1 pin 1 (HV+ -> R2 -> tap -> R1 -> Q1.1 LED
    anode; Q1.2 LED cathode stays on the HV return with Q2.3). Verified via
    netlist membership diff that this is the only change: Q1.1 moves off its
    unconnected-* net onto a new net with R1's free pin, and Net-(D7-A) loses
    exactly that one R1 member --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
    [picoemp-rev2026.kicad_sch]
2026-07-26 Adopt upstream's 1.0mm HV clearance rule; correct the voltage basis
    Raises the HV netclass 0.75 -> 1.0mm to match upstream's own annotation
    on SCH-PICOEMP-REV04.PDF:
    ISOLATION BARRIER, 400V MIN. >1MM CLEARANCE PER 61010-1.
    Corroborated by measurement - pad geometry on the hi-pot-validated
    original board gives ~1.002mm across the barrier in routed copper.
    The previous 0.75mm was anchored to T1's own 0.770mm primary-to-secondary
    pad spacing, chosen to avoid false-flagging. That was the wrong anchor:
    0.770mm is the ATB3225 package's internal geometry, not a routing
    clearance, and letting it set the rule pulled the design below upstream's
    stated intent. T1 will now flag once the board ca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
    [test_board_setup.py]
2026-07-26 Fix MH1-3 mounting hole symbol/footprint mismatch and restore LDA111 pin 3 NC
    MH1-3 used Mechanical:MountingHole_Pad_MP (pin "MP") with footprint
    MountingHole:MountingHole_3.2mm_M3_Pad_Via (pad "1"), a numbering mismatch
    in both directions that produced per-hole ERC warnings/errors and left
    plated copper floating at no defined potential inside the HV region.
    Switched to Mechanical:MountingHole / MountingHole_3.2mm_M3, which have no
    pins/pads at all (the 1551B shield is plastic, so no chassis bond is
    needed).
    picoemp:LDA111 was missing pin 3 entirely, even though the SOP-6 footprint
    correctly has six pads (the lead exists on the package, it's just
    electrically NC). Restored pin 3 as an expli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
    [picoemp-rev2026.kicad_sch]
2026-07-26 Place all carried-over parts from the validated layout; rescope HV rule
    Placement: 51 of 53 footprints positioned by translating the old board's
    coordinates (pure offset dX=-90.63, dY=-14.86; both outlines are 40x116
    with no rotation or flip). Task 8's designator restoration is what made
    this a 1:1 mapping. FID2/FID3 were off-board on the original and are left
    for manual placement. The six new parts (U2, R14-R16, C6, J4) are placed
    provisionally - trigger front-end near P1, J4 on the logic-end edge.
    Rule fix: the HV netclass clearance of 1.0mm was WRONG IN SCOPE. A
    netclass clearance applies between any two differing nets touching the
    class, including the two pads of one resistor - so it ma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
    [picoemp-rev2026.kicad_pcb]
2026-07-26 Update board-setup tests for the rescoped HV barrier rule
    The previous tests asserted the 1mm barrier lived in the HV netclass
    clearance. It now lives in picoemp-rev2026.kicad_dru as a rule
    conditioned on HV-to-non-HV, because a netclass clearance also applies
    between the two pads of a single component.
    Adds a test asserting the HV netclass clearance stays BELOW 0.70mm -
    at or above that, an 0603 resistor's own pad gap becomes a violation.
    [test_board_setup.py]
2026-07-26 Extend board to 40x130mm at the logic end; fix outline; rescope edge rule
    Outline: extended the logic end by 14mm (116 -> 130mm). The 1551B shield
    mounts on MH1/MH2 at the HV end, 100mm away, so lengthening this end
    costs nothing in shield compatibility. Widening past 40mm would.
    Fixed the invalid_outline error: three degenerate Edge.Cuts segments of
    ~0.02mm at the bottom corners, where the side lines terminated at
    y=35.12 while the corner arcs started at 35.14. Removed the slivers and
    snapped the side lines to the arc endpoints.
    J4 (optional trigger SMA) repositioned to the new logic-end edge,
    mirroring J1's 2.63mm offset from its own edge.
    Edge rule rescoped: "HV to board edge" applied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
    [picoemp-rev2026.kicad_pcb]
2026-07-26 Netclass widths, verified DRC rules, and outline repair
    Board setup for routing:
    * HV netclass gets real copper -- 0.5 mm default track, 0.8/0.4 via. Its
    clearance stays 0.2 mm; the 1 mm isolation barrier remains a scoped custom
    rule, not a netclass value.
    * New Power class (GND, +3V3) at 0.4 mm / 0.8-0.4 via.
    * Predefined track widths 0.2/0.3/0.4/0.5/0.8/1.0 and via sizes so W and V
    cycle useful values while routing.
    Deliberately NOT splitting an HV_PULSE class out of HV. KiCad 10 resolves each
    net to exactly one effective netclass -- an experiment with an overlapping
    HV_PULSE showed hasNetclass('HV_PULSE') never matching while hasNetclass('HV')
    still did. Splitting the discharge-lo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
    [picoemp-rev2026.kicad_pcb, picoemp-rev2026.kicad_sch]
2026-07-26 Name every net; scope the HV class by an HV_* wildcard
    Replaced all 20 auto-generated net names with meaningful ones by adding local
    labels to the schematic, and propagated them to the board.
    HV_RAIL <- Net-(D2-K) +250 V rail: C3+, D2 K, J1 shell, R2
    HV_RTN <- Net-(D7-A) isolated HV return
    HV_RECT <- Net-(D2-A) T1 secondary -> D2 anode
    HV_OUT <- Net-(J1-Ext) Q2 collector -> SMA centre (the pulse)
    HV_SENSE <- Net-(J3-Pin_2) divider tap, J3 pin 2
    HV_SENSE_LED <- Net-(Q1-A) R1 -> Q1 opto LED anode
    HV_GATE <- Net-(D7-K) Q2 gate, clamped by D7
    HV_GATE_DRV <- Net-(R7-Pad2) T2 sec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
    [picoemp-rev2026.kicad_pcb, picoemp-rev2026.kicad_sch]
2026-07-26 Move isolation slots outboard; fix inert HV netclass; restore pinless MH1-3
    Board geometry:
    * Both isolation slots moved 3.000 mm outboard and shortened to end at
    y=135.200, clear of the M3 holes. Island width 21.184 -> 27.184 mm, with a
    5.32 mm west strip and 4.96 mm east strip remaining.
    * The left slot was a parallelogram -- its outer wall ran from x=112.711 at the
    bottom to x=112.737 at the top, a 0.026 mm skew over 36.7 mm inherited from
    the Altium import. Rebuilt as a true rectangle.
    * The staggered notches above each slot moved with them and had their Y squared
    up; left sat at 96.3536/99.3 and right at 96.3728/99.3192, 0.019 mm of pure
    import noise.
    * East edge was two col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
    [picoemp-rev2026.kicad_pcb, picoemp-rev2026.kicad_sch]
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2026-07-26 Align MH1/MH2 with the bottom corners; correct the shield constraint claim
    MH1/MH2 move 1.855 mm south to y=140.872, putting them 4.000 mm from the south
    edge as well as 4.000 mm from the side edges. The R=4.000 corner arcs are
    centred on exactly those points, so all three mounting holes now sit concentric
    in their corners with a constant 2.400 mm FR4 web, instead of only MH3.
    I previously said their Y was fixed by the Hammond 1551B shield and could not
    move. That was inference from upstream's layout, not something I had checked,
    and it was overstated. hardware/shield/picoempshield-1551BTRD-top.stl is
    50 x 25 x 8 mm with corner bosses and contains no 32 mm screw pattern, so
    nothing in the r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
    [picoemp-rev2026.kicad_pcb]
2026-07-26 Centre the HV SMA tab; settle the pad-size axis question by plotting
    The outcropping for J1 was drawn 0.500 mm east of the board centreline -- tab
    centred on x=124.890 against a board centre of x=124.390. J1 itself sits at
    x=124.390, so the connector was centred on the board but off-centre in its own
    tab. Shifting the tab west by 0.500 mm centres both.
    Separately, the pad-size axis question behind BOTH the Q2 0.080 mm item and the
    J4 rotation short is now resolved, by plotting F.Cu and measuring the copper
    that would actually reach the gerbers rather than reasoning about coordinates:
    J1 / J4 pads 1.500 mm wide, 4.250 mm pitch -> 2.750 mm gaps. Fine.
    Q2 lead pads 2.200 mm wide, 2.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
    [picoemp-rev2026.kicad_pcb]
2026-07-26 Cut a USB notch in the north edge; J4 east; rearrange the north end
    The Pico's USB faces north with 13.6 mm of board in front of it. The connector
    centreline sits ~1.5 mm above our board surface, so a micro-B plug body -- ~6 mm
    tall, centred -- would need to occupy space 1.5 mm BELOW the board. It cannot be
    inserted at all. Moving J4 alone would not have fixed this; the plug is the
    problem, not the SMA.
    Chose a notch over moving the Pico north. Moving it up sounds cleaner and frees
    enough length to shorten the board back toward 116 mm, but the module is 23 mm
    wide and the usable north edge is only 32 mm, so the Pico would occupy all but
    ~4.5 mm at each end and J4 -- which must be at rot +/-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
    [picoemp-rev2026.kicad_pcb]
2026-07-27 Fix Q2's pad rotation: 0.080 mm -> 1.080 mm between IGBT leads
    The library footprint was never the problem. Package_TO_SOT_SMD:TO-252-3_TabPin2
    is correct -- 1.2 mm pads on a 2.286 mm pitch, matching a 0.9 mm DPAK lead.
    Pad angles in a .kicad_pcb are ABSOLUTE. Q2's pads carried no angle at all while
    its footprint sat at rot 90, so they never rotated with it and presented their
    2.2 mm dimension across the 2.286 mm pitch instead of their 1.2 mm one. That is
    where 0.080 mm came from. Stamping the footprint's 90 deg onto its eight pads
    fixes it; the pads now plot 1.200 mm across the pitch with 1.080 mm gaps, and
    Q2's DRC violations are gone.
    Those pads are the IGBT gate, collector and emitter.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
    [picoemp-rev2026.kicad_pcb]
2026-07-27 Restore DNP attributes wiped by Update Footprints from Library
    Update Footprints from Library fixed all 22 remaining pad-rotation mismatches --
    the audit now reports zero, and Q2's fix survived intact. It also reset the
    board-side "Do not populate" attribute on J4 and R16, which the schematic still
    marks dnp=True. Restored, taking schematic parity from 55 issues to 53.
    The 53 that remain are all one warning repeated: "Missing symbol field 'DigiKey'
    in footprint". Footprints do not carry BOM fields and are not meant to -- the BOM
    comes from the schematic, which still has every MPN and DigiKey number. Benign.
    [picoemp-rev2026.kicad_pcb]
2026-07-27 Bring the GND pour clearance in line with the rest of the board
    MCU GND Pour was set to 0.5 mm clearance on a board whose netclass clearance is
    0.2 mm. Nothing needed the extra 0.3 mm, and it was generating a batch of
    near-misses -- pads sitting at 0.4255 and 0.4630 mm that are perfectly fine.
    Dropped to 0.25 mm, which still leaves margin over the 0.2 mm everything else
    uses. Thermal gap 0.5 -> 0.3 mm for the same reason.
    The two 'Pad Keep Out TP7' keepout zones from U1's footprint also carry a
    connect_pads clearance, but theirs is 0 and has to stay 0. Left alone.
    DRC errors 45 -> 38.
    The 13 zone-clearance errors left are all at 0.0000 mm -- the pour is sitting
    directly on top of tracks a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
    [picoemp-rev2026.kicad_pcb]
2026-07-27 Clear the HV routing and lay a verified skeleton; the original copper cannot be reused
    Removed all 68 HV-net track segments and 4 HV vias, then laid 13 new segments
    at the HV netclass width of 0.5 mm. Every one was checked before writing against
    foreign pads (1 mm barrier), foreign tracks, and the board outline including the
    isolation slots. DRC errors involving an HV net: 0. Total errors 38 -> 17, all
    that remain on the logic side. Parity clean.
    THE ORIGINAL COPPER CANNOT BE TRANSPLANTED. Measured rather than assumed.
    Translating the original's 384 segments into our frame and grouping them into
    connected clusters -- a routed net is a chain, so only its end segments touch
    pads, and per-segm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
    [picoemp-rev2026.kicad_pcb]
2026-07-27 Checkpoint before HV placement redistribution
    Snapshot taken at the user's request so the placement work that follows is easy
    to revert in one step.
    [picoemp-rev2026.kicad_pcb, picoemp-rev2026.kicad_sch]
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

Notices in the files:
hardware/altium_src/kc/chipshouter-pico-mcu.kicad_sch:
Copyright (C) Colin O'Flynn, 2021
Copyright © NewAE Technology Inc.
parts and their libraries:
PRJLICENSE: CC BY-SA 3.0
